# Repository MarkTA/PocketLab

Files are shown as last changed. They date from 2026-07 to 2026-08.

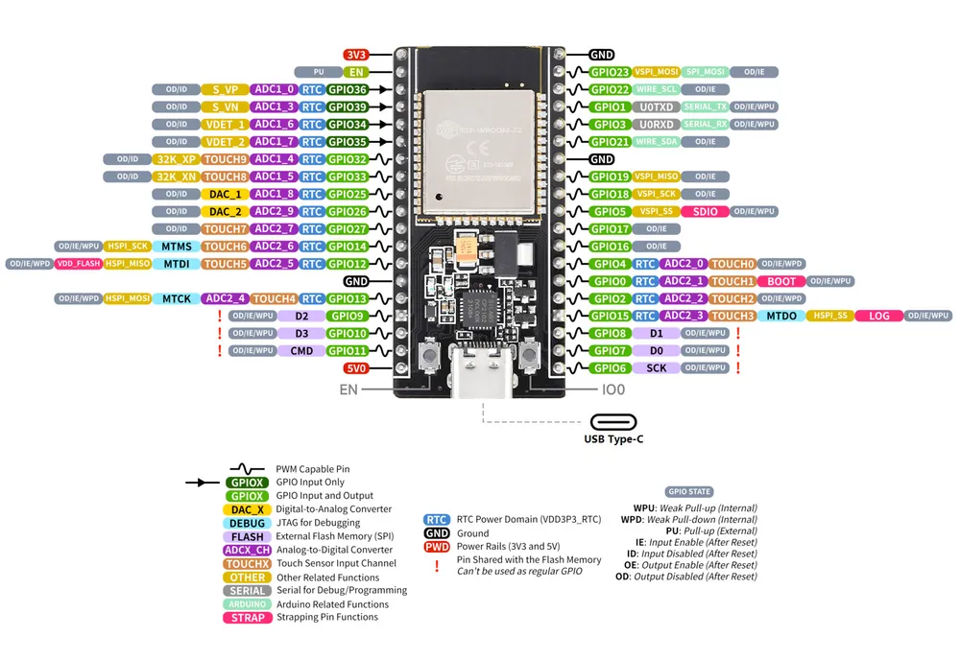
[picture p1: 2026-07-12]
docs/Component Reference/NodeMCU-ESP32S-BLE/en5HGiIniw-1000.webp

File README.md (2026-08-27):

# PocketLab

PocketLab is a modular, portable electronics instrumentation platform designed to combine common bench tools with a mobile interface.

The system is built around a compact **Bluetooth Low Energy (BLE) digital multimeter**, with additional instruments designed as stackable hardware modules. The goal is to create a practical, low-cost electronics lab that can travel with a laptop or fit in a small work area.

## Current Development

The first hardware prototype, **PocketLab DMM EVT-0**, is currently in PCB development.

### DMM EVT-0

- **Nordic nRF52840** BLE microcontroller
- **TI ADS1220** 24-bit delta-sigma ADC
- Voltage and resistance measurement
- Relay-based measurement routing
- USB-C power and charging
- Battery-powered portable operation
- 4-layer custom PCB designed in **Altium Designer**
- Stackable interface for future PocketLab instrument modules
- BLE communication with the PocketLab mobile application

EVT-0 is intentionally focused on validating the complete hardware/software system: PCB design, assembly, measurement circuitry, calibration, firmware, BLE communication, and mobile application integration.

## Planned Modules

PocketLab is designed as a modular platform rather than a single instrument.

Planned development includes:

- **FPGA Oscilloscope** — high-speed single-channel acquisition using an AMD Artix-7 FPGA and TI ADS6125 12-bit, 125 MS/s ADC
- **Function Generator**
- Additional measurement and electronics-development modules

## Software

PocketLab includes a companion mobile application for instrument control, measurement display, data logging, and interaction with connected modules.

The application is being developed with **React Native** and communicates with PocketLab hardware over Bluetooth Low Energy.

## Project Goals

PocketLab is also an ongoing engineering platform for developing experience in:

- Mixed-signal circuit design
- PCB schematic capture and layout
- Embedded systems
- Bluetooth Low Energy
- Precision data acquisition
- FPGA and RTL development
- Hardware/software integration
- Test, calibration, and design validation

## License

The software in this repository is licensed under the Apache License 2.0.

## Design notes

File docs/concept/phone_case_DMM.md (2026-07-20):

# PocketLab Phone-Case Multimeter Concept

**Recorded:** July 16, 2026  
**Status:** Future project idea—defer until the current PocketLab function generator is complete

## Concept

A compact, low-voltage digital multimeter integrated into—or attached to—a phone case. The phone supplies the display, controls, graphing, data logging, and user interface through a native mobile app. A thin measurement module contains the analog front end, precision ADC, low-power nRF52 microcontroller, BLE interface, and power source.

The defining physical feature would be two independently retractable probes with approximately 12-inch leads. Each probe would store along the edge of the case, while its wire retracts into a replaceable twin-reel cartridge on the back of the phone.

## Initial Product Scope

- Low-voltage electronics use only
- Approximately 0–30 V DC measurement
- Resistance and continuity
- Diode test
- Live numeric display and scrolling graph
- Automatic BLE connection and offline operation
- Measurement history and data export
- Two independent 12-inch retractable probes
- No mains rating
- No current measurement in the first version

## Proposed Architecture

- nRF52 MCU/module for low-power BLE and measurement control
- External precision ADC
- Protected, autoranging analog front end
- Thin rechargeable battery, coin cell, or USB-C power
- React Native PocketLab app as the display and interface
- Modular electronics pod compatible with multiple phone-specific shells
- 3D-printed enclosure prototypes using PETG, with optional TPU phone-retention features

## Retractable-Probe Design

- Two side-by-side reels, approximately 25–30 mm in diameter
- Thin, flexible 28–30 AWG silicone-insulated wire
- Constant-force or clock-style return springs
- Pull-and-lock ratchet with tug-to-release retraction
- Short probes stored in molded channels along the phone edges
- Replaceable reel/probe cartridge for serviceability
- Prefer a limited-rotation flexible clock-spring electrical connection instead of sliding contacts or inexpensive slip rings
- Calibrate and subtract lead resistance for continuity and low-resistance measurements

## Product Differentiators

- Always available because it stays attached to the phone
- Self-storing probes with no separate lead pouch
- Phone-quality display, controls, graphing, and logging
- Pocketable low-voltage electronics tool for students, makers, embedded developers, and technicians
- Fast, memorable demonstration for interviews and professional networking
- Potential foundation for additional PocketLab modules, including a function generator, oscilloscope, and logic analyzer

## Important Engineering Questions

- Can the twin-reel mechanism remain thin, smooth, and reliable over thousands of cycles?
- Can the rotating electrical connection maintain stable resistance without adding noise?
- What reel and probe geometry is comfortable in a pocket?
- How should the instrument pod attach across different phone models?
- What input protection is appropriate for the stated 30 V maximum?
- What accuracy, sample rate, battery life, and production cost are achievable?
- Does the mechanical design contain protectable intellectual property, and what related prior art exists?

## Recommended Future Development Sequence

1. Inventory the available nRF52 modules and development board.
2. Build a bench prototype that measures 0–5 V DC and sends readings to the PocketLab app over BLE.
3. Characterize accuracy, noise, update rate, and power consumption.
4. Disassemble inexpensive badge reels or retractable cable mechanisms for dimensional and durability studies.
5. Print a non-electronic PETG phone-case mockup with a twin-reel cartridge.
6. Develop and cycle-test the reel, ratchet, probe storage, and clock-spring connection.
7. Combine the mechanical prototype with the measurement electronics.
8. Expand to 0–30 V, resistance, continuity, and diode modes.
9. Conduct prior-art, market, manufacturability, and cost studies before designing a production PCB.

## Current Decision

Preserve this concept for later development without interrupting the present PocketLab function-generator work. Finish and document the function generator first, then revisit the phone-case multimeter as a potential second PocketLab instrument and commercial product.

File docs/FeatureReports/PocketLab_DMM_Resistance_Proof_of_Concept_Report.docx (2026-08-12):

ENGINEERING VALIDATION REPORT

# PocketLab DMM Resistance Measurement Proof of Concept

ADS1220 breadboard validation and provisional Rev A switching architecture

Project: PocketLab modular test platform

Test platform: ESP32 NodeMCU-32S + genuine ADS1220IPWR on a breadboard breakout

Report date: August 8, 2026

Status: Proof of concept successful; final parts and protection network pending schematic review

# Executive conclusion

Outcome: The tested resistance architectures provide credible overlapping coverage from continuity/near-zero resistance through approximately 10 MΩ. The genuine ADS1220 successfully supported both IDAC-based ratiometric measurements and a separate supply-ratiometric voltage-divider method.

The breadboard work was intentionally architectural, not a final accuracy qualification. One-percent resistors, jumper/contact resistance, solderless-breadboard leakage, and unguarded high-impedance nodes dominate several observed errors. Those limitations do not invalidate the topology; they define what the first precision PCB must improve.

# 1. Test platform and common settings

Item | Bench configuration
ADC | ADS1220IPWR, 24-bit delta-sigma ADC, TSSOP-16
Controller | ESP32 NodeMCU-32S
Supplies | 3.3 V analog and digital rails; common analog/digital ground on breadboard
SPI | Mode 1 (CPOL=0, CPHA=1), 1 MHz
Conversion | 20 SPS, normal mode, continuous conversion; typically 10 samples/report
Serial interface | 115200 baud; configurable divider firmware supports rref, samples, interval, predict, start/stop, once, status, regs, and adcreset
Safety state | Unprotected bench circuit. Tests used only unpowered resistors and discharged components.

# 2. Pin assignments

## ADS1220IPWR TSSOP-16 and ESP32 wiring

Pin | ADS1220 signal | Bench connection | Function
1 | SCLK | ESP32 GPIO 18 | SPI clock
2 | CS | ESP32 GPIO 27 | Active-low chip select
3 | CLK | DGND | Internal oscillator used
4 | DGND | Ground | Digital ground
5 | AVSS | Ground | Analog ground
6 | AIN3 / REFN1 | Unused | Reserve/test point on PCB
7 | AIN2 | IDAC Node A | IDAC1 injection point in ratiometric ohms mode
8 | REFN0 | AGND | External reference low
9 | REFP0 | Rref top / 3.3 V | Rref node in IDAC mode; excitation rail in divider mode
10 | AIN1 | Node B / AGND | Negative ADC input; grounded in divider mode
11 | AIN0 / REFP1 | Node A / divider junction | Positive ADC input
12 | AVDD | 3.3 V | 100 nF or larger to AVSS
13 | DVDD | 3.3 V | 100 nF or larger to DGND
14 | DRDY | ESP32 GPIO 26 | Dedicated data-ready, active low
15 | DOUT / DRDY | ESP32 GPIO 19 | SPI MISO
16 | DIN | ESP32 GPIO 23 | SPI MOSI

Pin numbers above are for the PW (TSSOP-16) package used in the breadboard build. Any adapter/header numbering should be checked against the adapter schematic before PCB capture.

# 3. Tested resistance configurations

## A. IDAC verification with 9.99 kΩ reference

Purpose: verify that the genuine ADS1220 correctly produces its low excitation-current settings before relying on ratiometric resistance measurements. IDAC1 was routed directly to REFP0 with 9.99 kΩ from REFP0 to REFN0/AGND. The 10 µA, 50 µA, and 100 µA settings correspond to nominal reference voltages of 0.0999 V, 0.4995 V, and 0.9990 V.

Interpretation: The genuine ADS1220 corrected the abnormal 10 µA behavior seen on the earlier third-party module, clearing the internal IDAC for continued range development.

## B. IDAC/ratiometric resistance mode

Wiring and equation:

Node/path | Connection
Node A | AIN2 (IDAC1 output) tied to AIN0; Rx connects from Node A to Node B
Node B | AIN1 tied to REFP0; Rref connects from Node B to REFN0/AGND
Measurement | ADC measures AIN0 − AIN1 while REFP0 − REFN0 is the external reference
Equation | Rx = (ADC code / 2²³) × Rref / PGA gain

Because the same IDAC current passes through Rx and Rref, absolute IDAC-current error largely cancels. Tested range configurations included 21.6 kΩ / 50 µA and 100.6 kΩ / 10 µA. The latter used registers 00 04 41 60 at gain 1 and was exercised across the resistor set below.

Comparison value | ADS1220 mean | Approx. FS use | Observation
99.8 Ω | 100.940 Ω | 0.100% | Low ADC utilization; lead/contact/offset effects dominate
1.003 kΩ | 1.005676 kΩ | 1.000% | After subtracting the same-setup short mean, result was approximately 1.0028 kΩ
4.74 kΩ | 4.752627 kΩ | 4.724% | Stable proof-of-concept response
9.90 kΩ | 9.897055 kΩ | 9.838% | Close agreement at gain 1
21.49 kΩ | 21.475935 kΩ | 21.348% | Stable midrange response

The gain-1 short averaged 2.876 Ω with 0.160 Ω batch-to-batch standard deviation. That offset is not a universal correction; it changes with gain, switch path, probes, and physical connections. Low-ohm production measurements therefore require per-range zeroing and automatic PGA selection. True sub-ohm accuracy would require a later Kelvin/four-wire mode.

## C. 1.000 MΩ supply-ratiometric divider mode

Connection/setting | Divider-mode assignment
AIN0 (pin 11) | Junction of 1.000 MΩ reference and Rx
AIN1 (pin 10) | AGND
REFP0 (pin 9) | Same 3.3 V excitation rail feeding Rref
REFN0 (pin 8) | AGND
IDACs | Disabled
Registers | 01 04 40 00: AIN0−AIN1, gain 1, PGA bypassed, external REFP0/REFN0
Equation | k = ADC code / 2²³; Rx = Rref × k / (1 − k)

Fluke reading | ADS1220 mean | Difference | Divider ratio | Interpretation
100.6 kΩ | 100.0879 kΩ | −0.51% | 9.10% | Clean lower overlap with IDAC ranges
467 kΩ | 462.628 kΩ | −0.94% | 31.63% | Stable mid-divider result; modest upward settling drift
9.80 MΩ | 9.6159 MΩ | −1.88% | 90.58% | Successful multi-megaohm measurement; leakage and near-full-scale sensitivity visible

The increasing negative error with resistance is consistent with leakage becoming more influential, while the nominal 1 MΩ reference value, Fluke uncertainty, ADC input current, and breadboard contamination also contribute. The 9.80 MΩ reading operated near 91% of ADC full scale, making the calculated resistance highly sensitive to small ratio errors. A 10 MΩ reference is therefore recommended for the upper range.

# 4. Coverage demonstrated and proposed range map

Target region | Method | Provisional configuration | Evidence/status
Continuity to ~1 kΩ | IDAC, ratiometric | 10 kΩ precision Rref; ~100 µA; higher PGA gain | Partially demonstrated; low-ohm accuracy needs zeroing and gain
~1 kΩ to 10 kΩ | IDAC, ratiometric | 10 kΩ precision Rref; 100 µA; auto gain | Topology and excitation verified
~10 kΩ to 100 kΩ | IDAC, ratiometric | 100 kΩ precision Rref; 10 µA | Validated from 100 Ω through 21.49 kΩ; electrical headroom supports extension
~100 kΩ to 3–5 MΩ | Voltage divider, ratiometric | 1 MΩ precision Rref; 3.3 V excitation/reference | Validated at ~100 kΩ and 467 kΩ; 10 MΩ measurement also succeeded with reduced accuracy
~3 MΩ to 20 MΩ+ | Voltage divider, ratiometric | 10 MΩ precision Rref; guarded high-Z path | Recommended next range; not yet tested

Range policy: Use overlapping ranges and autorange toward the center of ADC span. Avoid relying on results below roughly 1% or above roughly 90% of full scale when a neighboring range is available.

# 5. Provisional Rev A switching architecture

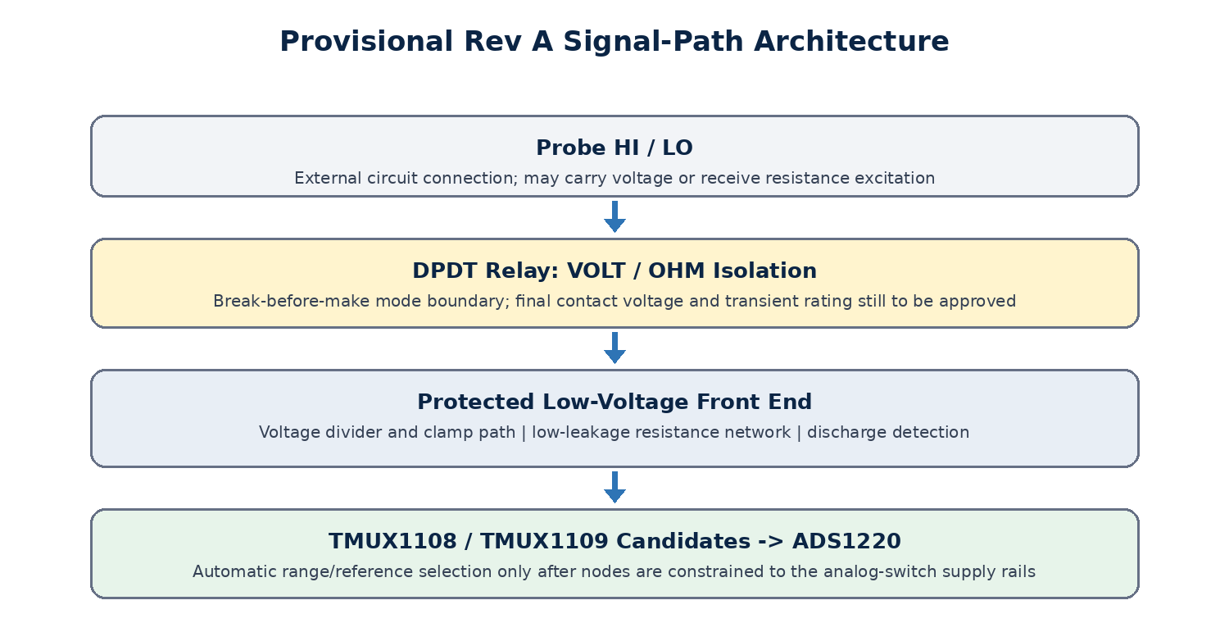
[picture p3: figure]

Figure 1. Proposed separation between the hazardous/probe-level mode boundary and the protected low-voltage range-selection network.

## Relay: voltage/ohms mode boundary

Use a DPDT, break-before-make relay to select the probe pair between the voltage-measurement front end and the powered resistance-measurement front end. Mechanical contacts provide galvanic separation from the low-voltage analog switches and prevent the ADS1220 IDAC from being connected to an energized voltage source during normal operation.

- Default/fail-safe state should be voltage mode or fully disconnected, with resistance excitation disabled during boot, reset, brownout, and relay transitions.
- Firmware must disable both IDACs, wait for the relay to settle, verify the selected state where possible, and only then enable the chosen resistance range.
- Include a transistor or MOSFET coil driver, flyback suppression, a defined MCU pull state, and local supply decoupling. Do not drive the 3 V coil directly from an MCU pin.
- The Panasonic TQ2-3V remains a useful prototype candidate: sealed, 2 Form C (DPDT), break-before-make, 3 V coil, and 140 mW rated coil power. Its published nominal resistive switching capacity is 1 A at 30 VDC. Final approval depends on the exact location of the relay relative to the input protection/divider and the product’s maximum DC input and transient requirements.

Purchasing gate: Do not commit the TQ2-3V as the final probe-level relay until the voltage-mode protection/divider schematic proves that every contact operating and transient condition is within the relay’s ratings. If the relay directly sees the planned ~70 V input, select or validate a relay specifically for that DC voltage and measurement-category environment.

## Analog multiplexers: automatic resistor and topology ranges

Candidate | Topology | Best provisional role | Reason / constraint
TMUX1108PWR | Single 8:1 precision multiplexer | Select one of several reference/excitation branches or calibration/open positions | Very low leakage, break-before-make, enable-all-off state; 0–VDD signal path only
TMUX1109PWR | Dual 4:1 / differential 4:1 precision multiplexer | Switch two related low-voltage nodes together, such as ADC input/reference or paired topology nodes | Coordinated dual channels reduce GPIO and timing mismatch; same rail-limit restriction

Both TI parts are strong candidates because their typical leakage is in the picoamp region, they are bidirectional and break-before-make, and they include an enable state that disconnects all channels. At 3.3 V, however, their analog signal pins must remain within the switch supply rails. They are not input-protection devices and must sit behind the relay and protection/scaling network.

- Do not automatically assume the TMUX on-resistance is harmless in the continuity/low-ohm path. TMUX1108 is typically about 4 Ω at a 3.3 V supply under its datasheet test condition. Place it so its resistance is calibrated as part of Rref/path resistance, or bypass it with a lower-resistance solution for the lowest range.
- For the 1 MΩ and 10 MΩ divider ranges, leakage is more important than on-resistance. Keep the high-impedance node short, guarded, clean, and separated from relay-coil and digital traces.
- Reserve explicit all-off/open, short-calibration, 10 kΩ, 100 kΩ, 1 MΩ, and optional 10 MΩ states. Unused channels can become test or future ranges only after leakage impact is reviewed.
- Add 0 Ω links and test points so each range can be isolated from the switch during bring-up. This allows direct resistor testing before attributing errors to the multiplexer.

# 6. Recommended Rev A implementation plan

1. Freeze the functional range plan. Adopt overlapping low/mid IDAC ranges plus 1 MΩ and 10 MΩ divider ranges. Treat Kelvin measurement as a future enhancement, not a Rev A blocker.
2. Complete the voltage-input protection and divider schematic first. Establish maximum input, transient goals, discharge detection, current limiting, creepage/clearance, and the voltage actually appearing at the mode relay and TMUX nodes.
3. Draw the full switching truth table. For every relay and TMUX state, define probe connection, ADC inputs, reference selection, IDAC route, expected node voltages, boot state, and forbidden transitions.
4. Select precision references. Use low-tempco 0.05% or 0.01% parts where cost permits; provide 10 kΩ, 100 kΩ, 1 MΩ, and optional 10 MΩ footprints. Store measured/calibrated value per assembled board.
5. Prototype the uncertain switching functions quickly. Validate TMUX leakage at ~10 MΩ, low-range series resistance/zero repeatability, relay-mode isolation, and relay-driver behavior before the consolidated DigiKey order.
6. Lay out the analog section for measurement integrity. Separate high-Z nodes from digital/relay traces, add guard copper where useful, omit solder mask only when justified, provide cleaning access, and place decoupling and RC filters at the ADC pins.
7. Implement safe autoranging firmware. Start de-energized, open analog switches before changing range, wait for settling, reject overrange/negative ratios, and fall back to voltage/disconnected mode after faults or reset.
8. Calibrate and verify the PCB by range. Record zero/path resistance, Rref value, gain/offset constants, leakage behavior, repeatability, temperature drift, and cross-checks against the Fluke and a better reference instrument when available.

# 7. Rev A acceptance targets

Gate | Acceptance evidence
Coverage | Continuity/near-zero through at least 10 MΩ with no manual rewiring
Autoranging | Stable range selection with overlap and no IDAC exposure during switching
Mode safety | Ohms excitation cannot be enabled while the voltage path or an overvoltage condition is present
Low-ohm behavior | Repeatable software-zero result; continuity response target defined separately from precision resistance
High-ohm behavior | 1 MΩ and 10 MΩ ranges characterized for leakage after PCB cleaning and environmental exposure
Serviceability | Test points and 0 Ω isolation links allow each reference and switch path to be measured independently
Documentation | Per-range register map, switching truth table, calibration constants, and protection assumptions captured in the schematic notes

# Appendix A. Test artifacts and source documents

The following firmware files preserve the breadboard configurations summarized in this report. Serial measurement logs from the working sessions were reduced into the result tables above; the PCB design should retain new raw logs by board serial number and range.

Firmware artifact | Purpose
ADS1220_9k99_IDAC_Range_Test.ino | Direct 10 µA / 50 µA / 100 µA IDAC verification with 9.99 kΩ
ADS1220_21k6_50uA_Ratiometric_Test.ino | 21.6 kΩ / 50 µA ratiometric resistance configuration
ADS1220_100k6_10uA_Ratiometric_Test.ino | 100.6 kΩ / 10 µA multi-resistor configuration
ADS1220_Serial_Configurable_Resistance_Divider.ino | Serial-configurable 1 MΩ supply-ratiometric divider configuration

## Manufacturer references

Texas Instruments, ADS1220 datasheet (Rev. D, May 2026) (https://www.ti.com/lit/ds/symlink/ads1220.pdf)

Texas Instruments, TMUX1108 datasheet (Rev. B) (https://www.ti.com/lit/ds/symlink/tmux1108.pdf)

Texas Instruments, TMUX1109 datasheet (Rev. A) (https://www.ti.com/lit/ds/symlink/tmux1109.pdf)

Panasonic Industry, TQ2-3V product specifications (https://na.industrial.panasonic.com/products/relays-contactors/mechanical-signal-relays/series/119572/model/119866)

PocketLab DMM •

PocketLab DMM | Engineering Validation Report

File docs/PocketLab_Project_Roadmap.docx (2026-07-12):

PocketLab Project Roadmap

# Vision

PocketLab is a portable, BLE-controlled electronics laboratory built around an ESP32. The first instrument is a programmable function generator. Future instruments will include an oscilloscope, logic analyzer, programmable power supply, and signal injector. The mobile application should be instrument-focused and transport-agnostic.

# Architecture

UI → Instrument API → PocketLab Device → Transport → BLE (future USB/Wi-Fi). The UI never sends raw BLE commands. Instruments expose methods such as setFrequency(), setAmplitude(), and outputEnabled().

# Milestone 1 – BLE Foundation

Complete: scanning, connecting, reconnecting, disconnecting, service discovery, read/write characteristics, connection status UI.

# Milestone 2 – PocketLab Command Protocol

Implement ASCII request/response protocol (PING, INFO, SET_FREQ, SET_AMP, SET_OFFSET, SET_WAVE, OUTPUT). Every command returns OK or ERR.

# Milestone 3 – Command Parser Firmware

Create a reusable parser independent of BLE. BLE callback simply forwards received commands to the parser.

# Milestone 4 – Function Generator

Integrate AD9833 driver. Connect all UI controls to firmware commands. Verify waveform, frequency, amplitude, offset, presets, and output enable.

# Milestone 5 – Protocol Robustness

Device identification, firmware versioning, capability discovery, validation, acknowledgements, error handling.

Milestone 6 – Notifications

Push asynchronous status changes, settings updates, and faults from device to app.

Milestone 7 – Hardware

Rail-to-rail output amplifier, adjustable offset, output protection, calibration, PCB prototype.

# Milestone 8 – Additional Instruments

Reuse the same transport and command framework for oscilloscope, logic analyzer, programmable power supply, and signal injector.

# Design Principles

• Separate UI from transport. • Commands are human-readable during development. • Every command receives a response. • BLE is only one transport layer. • Each instrument exposes a clean API. • Reuse infrastructure whenever possible.

# Conversation Context

Current status: BLE communication infrastructure is operational. The next task is implementing the PocketLab command protocol and firmware command parser before integrating the AD9833 function generator.

src/

├── app/

│ ├── navigation/

│ └── providers/

│

├── core/

│ ├── device/

│ │ ├── PocketLabDevice.ts

│ │ ├── DeviceProvider.tsx

│ │ └── deviceTypes.ts

│ │

│ ├── transport/

│ │ ├── PocketLabTransport.ts

│ │ ├── BleTransport.ts

│ │ └── transportTypes.ts

│ │

│ └── protocol/

│ ├── commands.ts

│ ├── responses.ts

│ ├── parser.ts

│ └── protocolTypes.ts

│

├── instruments/

│ ├── functionGenerator/

│ │ ├── FunctionGenerator.ts

│ │ ├── FunctionGeneratorScreen.tsx

│ │ ├── FunctionGeneratorControls.tsx

│ │ ├── FunctionGeneratorPreview.tsx

│ │ └── functionGeneratorTypes.ts

│ │

│ ├── oscilloscope/

│ │ ├── Oscilloscope.ts

│ │ ├── OscilloscopeScreen.tsx

│ │ └── oscilloscopeTypes.ts

│ │

│ ├── logicAnalyzer/

│ │ ├── LogicAnalyzer.ts

│ │ ├── LogicAnalyzerScreen.tsx

│ │ └── logicAnalyzerTypes.ts

│ │

│ ├── powerSupply/

│ │ ├── PowerSupply.ts

│ │ ├── PowerSupplyScreen.tsx

│ │ └── powerSupplyTypes.ts

│ │

│ └── signalInjector/

│ ├── SignalInjector.ts

│ ├── SignalInjectorScreen.tsx

│ └── signalInjectorTypes.ts

│

├── features/

│ └── connection/

│ ├── DeviceStatusCard.tsx

│ ├── ScanDeviceSheet.tsx

│ └── blePermissions.ts

│

├── components/

│ └── shared UI components

│

├── themes/

└── utils/

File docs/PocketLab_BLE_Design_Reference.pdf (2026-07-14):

PROJECT REFERENCE

# PocketLab BLE Design

A durable reference for the function generator's BLE architecture, safety model, and extensible GATT namespace.

1/3

## SYSTEM AT A GLANCE

MOBILE APP

React Native / Expo

BLE LINK

Custom GATT service

CONTROL

ESP32 + NimBLE

SIGNAL

AD9833 DDS

## DESIGN BASELINE

## Control objective

Low-latency, bidirectional control with explicit device state, predictable disconnect behavior, and room for future PocketLab instruments.

## Logical safe idle

WAVE=DC | FREQ=0
AMP=0.00 | OFFSET=0.00
OUTPUT=OFF

DC is an internal safe-state sentinel. The AD9833 is not asked to synthesize DC; hardware output is disabled instead.

SUFFIX | ATTRIBUTE | ACCESS | ROLE | STATUS
0001 | PocketLab service | Primary service | Function-generator control namespace | In use
0002 | Command | Write / Write NR | App -> ESP32 request frames | In use
0003 | Response | Notify + Read | ESP32 -> app ACK, ERR, data | In use
0004 | State | Read + Notify | Snapshot and unsolicited state changes | Reserved
0005 | Device info | Read | Protocol version and capabilities | Reserved

SERVICE 8f5b0001-6c4d-4a73-a8f1-3d9ea01c0001

COMMAND 8f5b0002-6c4d-4a73-a8f1-3d9ea01c0001

Strategy: replace N in 8f5b000N with the table suffix; keep the shared 128-bit base for every function-generator attribute.

PocketLab BLE Design Reference | Baseline: firmware v0.3.2 | Mark Anderson | 13 July 2026 | 1

ENGINEERING RECORD

# NimBLE Migration & Debugging

The important failures, observations, and design rules preserved as reusable project knowledge.

2/3

## WHY NIMBLE

### Lean stack

Lower memory overhead and a smaller embedded BLE surface for the ESP32.

### Explicit behavior

Characteristic properties, callbacks, notifications, and advertising are configured deliberately.

### Stable foundation

A consistent server API for reconnect handling and future PocketLab services.

## DEBUGGING HISTORY

### 10 JUL Generic GATT baseline

BAAD/F00D demo reads worked. Writes appeared successful on Android, but the ESP32 onWrite callback did not run and the original value remained unchanged.

### 11 JUL Write-path isolation

Request and Command modes plus write-with-response and write-without-response were tested. In one nRF Connect test, the attribute value changed to PING while callback logging was still absent.

### 11-12 JUL Custom service + reconnect

Service discovery, characteristic reads, notifications, connection status, and automatic reconnect worked. A PING write was accepted, then the app timed out after 5 seconds waiting for a response.

### 12 JUL NimBLE command path operational

The custom command server began delivering responsive app control. Fast round trips confirmed the BLE path was viable for interactive waveform control.

### 13 JUL Safe-idle hardening

Disconnect behavior exposed an unwanted roughly 3.3 V DC output. The design separated logical DC idle from supported AD9833 waveforms and made OUTPUT=OFF the default and disconnect action.

## MIGRATION GUARDRAILS

AREA | RULE TO KEEP
Callbacks | Attach characteristic callbacks before starting the service; log payload length and decoded text at entry.
Properties | Firmware properties must match the app's selected write type. Support both only when both paths are tested.
Notifications | Subscribe before sending the first command; create one response for every accepted request.
Reconnect | On disconnect, force safe idle, restart advertising, and let only the app initiate automatic reconnect.
State | Keep logical state separate from hardware modes; DC is never passed to the AD9833 waveform function.
PocketLab BLE Design Reference | Baseline: firmware v0.3.2 | Mark Anderson | 13 July 2026 | 2

PROTOCOL SPECIFICATION

# PocketLab Command Protocol v1

A compact ASCII request/response protocol designed to remain reliable at the default BLE MTU of 23 bytes.

3/3

## WIRE FORMAT

UTF-8/ASCII, one frame per characteristic write or notification, no terminator required. Keep v1 frames at 20 bytes or fewer so they fit the MTU-3 payload without fragmentation. The app permits one outstanding request at a time.

## COMMAND SET

REQUEST | PURPOSE | SUCCESS RESPONSE
PING | Verify the complete write/notify path | OK:PONG
GET:STATE | Request a complete state transaction | STATE:* frames, then STATE:END
SET:WAVE:SINE | Set SINE, TRIANGLE, or SQUARE | OK:WAVE:SINE
SET:FREQ:1000 | Set output frequency in hertz | OK:FREQ:1000
SET:AMP:0.65 | Set requested amplitude in Vpp | OK:AMP:0.65
SET:OFFSET:0.00 | Set requested DC offset in volts | OK:OFFSET:0.00
OUTPUT:ON | Enable hardware output after validation | OK:OUTPUT:ON
OUTPUT:OFF | Immediately disable hardware output | OK:OUTPUT:OFF

## STATE TRANSACTION

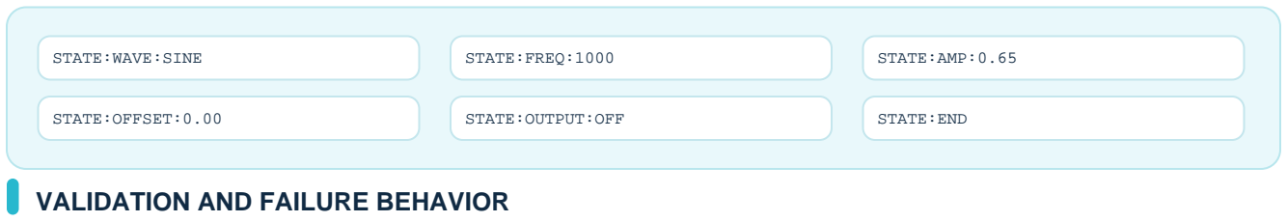
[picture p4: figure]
STATE:WAVE:SINE; STATE:FREQ:1000; STATE:AMP:0.65; STATE:OFFSET:0.00; STATE:OUTPUT:OFF; STATE:END; VALIDATION AND FAILURE BEHAVIOR
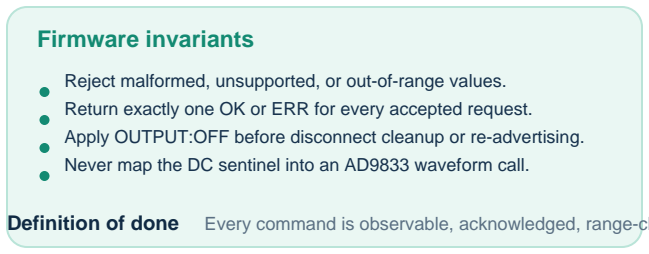
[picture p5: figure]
Firmware invariants

Reject malformed, unsupported, or out-of-range values.
Return exactly one OK or ERR for every accepted request. Apply OUTPUT:OFF before disconnect cleanup or re-advertising. Never map the DC sentinel into an AD9833 waveform call.

### Implementation sequence

1 Add parser + unit tests
2 Add response notification queue 3 Serialize app requests + timeout 4 Verify MTU 23 and reconnect cases 5 Record scope readings by waveform Definition of done Every command is observable, acknowledged, range-checked, and safe across disconnect/reconnect.
PocketLab BLE Design Reference | Baseline: firmware v0.3.2 | Mark Anderson | 13 July 2026 | 3

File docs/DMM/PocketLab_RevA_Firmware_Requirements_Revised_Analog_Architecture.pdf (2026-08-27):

# PocketLab Rev A Firmware Requirements

## Revised ADS1220 / TMUX1109 Analog Architecture

Status: design note for schematic freeze and later firmware implementation. Revision date: 2026-08-18. This document reflects the revised unipolar resistance excitation plan while preserving the ADS1220 bipolar analog supply (+2.5 V / -2.5 V). Core rule: voltage measurement remains bipolar-capable, but all valid resistance-mode probe signals are constrained to approximately 0 V through +2.5 V. The ADS1220 internal low-side PSW is not used.

## 1. Final ADS1220 analog pin assignment

ADS1220 input | Connection | Purpose
AIN0 | VSENSE_BUF | Voltage measurement input
AIN1 | GND | Voltage reference input and high-ohms negative ADC input
AIN2 | OHMS_SENSE_LO | Resistance Rref/divider junction
AIN3 | OHMS_SENSE_HI | Resistance probe-high node and IDAC1 destination
REFP0 | ADC_REFP0 | Ratiometric reference high
REFN0 | GND | Ratiometric reference low

## 2. ADS1220 mode configuration

Mode | ADC MUX | MUX bits | Reference | PGA / IDAC
Voltage | AIN0 - AIN1 | 0000 | Internal 2.048 V | Gain 1, PGA bypass, IDAC off
10k Rref | AIN3 - AIN2 | 0111 | REFP0 / REFN0 | IDAC on, PSW off
100k Rref | AIN3 - AIN2 | 0111 | REFP0 / REFN0 | IDAC on, PSW off
1M divider | AIN1 - AIN2 | 0011 | +2V5A / GND | Gain 1, PGA bypass, IDAC off
10M divider | AIN1 - AIN2 | 0011 | +2V5A / GND | Gain 1, PGA bypass, IDAC off

The ADS1220 datasheet defines MUX=0000 as AIN0-AIN1, 0011 as AIN1-AIN2, and 0111 as AIN3-AIN2. For high-ohms mode the conversion is intentionally negative because AIN1 is GND and AIN2 is the positive divider node.

## 3. External TMUX1109 functions

MUX_OHMS keeps the four range states. A1:A0 = 00/01/10/11 selects 10k/100k/1M/10M. Its A bank selects the Rref topology; its B bank selects REFP0. EN=0 must disconnect all channels.

A1 A0 | Range | Rref connection | ADC_REFP0 | IDAC / PSW
00 | 10k | 10k to GND | OHMS_SENSE_LO | IDAC selected / PSW OFF
01 | 100k | 100k to GND | OHMS_SENSE_LO | IDAC selected / PSW OFF
10 | 1M | 1M to +2V5A | +2V5A | IDAC OFF / PSW OFF
11 | 10M | 10M to +2V5A | +2V5A | IDAC OFF / PSW OFF

Repurposed MUX_ADC: DA connects to OHMS_SENSE_HI. S1A and S2A are NC/open. S3A and S4A connect to GND. The B bank is unused. Prefer MUX_ADC_EN=0 in voltage and low/mid-ohms modes, and MUX_ADC_EN=1 only in the 1M/10M divider modes. TMUX1109 EN=0 turns all channels off.

## 4. Resistance-mode electrical behavior

Low/mid ohms (10k and 100k Rref): IDAC1 is routed to AIN3/OHMS_SENSE_HI. Current flows through Rx and the selected Rref to GND. The ADC measures AIN3-AIN2 while REFP0 is tied to OHMS_SENSE_LO and REFN0 to GND. This remains ratiometric because the same excitation current flows through Rx and Rref.
High ohms (1M and 10M Rref): the selected Rref is connected from +2V5A to OHMS_SENSE_LO. The repurposed TMUX1109 grounds OHMS_SENSE_HI. Rx therefore sits between OHMS_SENSE_LO and GND. REFP0 is +2V5A and REFN0 is GND. The ADC measures AIN1-AIN2 = GND - OHMS_SENSE_LO.
High-ohms conversion: sign-extend the 24-bit conversion to a signed integer. For a valid divider reading the code should be negative. Define k = -code / 2^23 (gain 1), then compute Rx = Rref * k / (1 - k). Reject k <= 0, k >= 1, unexpected positive code, or values too close to either endpoint.

## 5. IDAC requirements and compliance

The ADS1220 IDAC output pin must remain at or below approximately AVDD - 0.9 V for specified IDAC accuracy. With AVDD = +2.5 V, the AIN3/OHMS_SENSE_HI target is therefore <= about +1.6 V while an IDAC is active.

Example setting | Approx. total R at 1.6 V compliance | Approx. Rx headroom after Rref
100 uA, 10k Rref | 16k ohm | 6k ohm
50 uA, 10k Rref | 32k ohm | 22k ohm
10 uA, 100k Rref | 160k ohm | 60k ohm

Do not freeze autorange thresholds from these estimates alone. Bench characterization should choose the current/PGA combination that keeps the IDAC in compliance while maintaining adequate ADC utilization. The earlier 100 uA / 10k and 10 uA / 100k values remain useful starting points, not unconditional full-range settings.

## 6. Required mode-transition sequence

1. Enter safe state: IDAC off, PSW off, MUX_ADC_EN=0, MUX_OHMS_EN=0, ohms relays open.
2. If entering resistance mode, first verify the DUT is not externally energized and no protection fault is present.
3. Program A1/A0 for the desired range while the muxes are disabled.
4. Configure ADS1220 input MUX, reference source, gain, PGA bypass, and IDAC current.
5. For low/mid ohms: enable MUX_OHMS, route IDAC1 to AIN3 only after programming the IDAC current, then wait at least 200 us for IDAC startup.
6. For high ohms: enable MUX_OHMS, then enable MUX_ADC ground-switch state; IDAC remains off.
7. Close the ohms relays only in the intended safe sequence; allow relay and analog settling.
8. Start/synchronize conversion, discard initial unsettled conversion(s) as required by bench characterization, then accept data.
9. On fault, reset, brownout, overrange, invalid ratio, or mode change: IDAC off first, disable muxes, then open ohms relays.

## 7. Provisional firmware configuration by mode

Item | Voltage | 10k/100k ohms | 1M/10M ohms
OHMS relays | Open | Closed after safety check | Closed after safety check
MUX_OHMS | Disabled | Enabled; range selected | Enabled; range selected
MUX_ADC | Disabled | Disabled | Enabled; S3/S4 -> GND
ADS MUX | 0000 | 0111 | 0011
VREF bits | 00 internal | 01 external REFP0/REFN0 | 01 external REFP0/REFN0
PSW | 0 | 0 | 0
IDAC | Off | Selected by range/compliance | Off
IDAC1 route | Disabled | AIN3 (I1MUX=100) | Disabled
PGA | Bypass initially | Range-dependent | Bypass
Expected sign | +/- voltage | Positive Rx drop | Negative code; negate in FW

## 8. Calibration and diagnostic requirements

- Store calibrated Rref values per board for 10k, 100k, 1M, and 10M ranges.
- Low-ohm calibration must include probe/lead resistance, reed-relay contact resistance, R_PROT_HI/LO, and any series switch resistance in the active path.
- Characterize zero offset separately for each gain/current/range combination; do not apply one universal short correction.
- High-ohms calibration must characterize leakage after PCB cleaning and under representative humidity/temperature conditions.
- Log the selected range, ADC register state, raw signed code, calculated ratio k, calibrated Rref, and protection/fault status during development.
- Autorange should prefer the middle of the useful ADC ratio span and avoid ratios close to 0 or 1 when an overlapping range exists.

## 9. Schematic items to correct before freeze

- MUX_ADC wiring: S1A/S2A must be NC; S3A/S4A must be GND. In the supplied screenshot S1A/S2A are presently tied to GND, which is reversed for the intended range coding.
- MUX_OHMS truth-table note: remove the old high-ohms 'PSW CLOSE' and 'AVDD-AVSS reference' text. High-ohms now uses PSW OFF and external +2V5A/GND reference.
- ADC firmware note: remove the old statement that 1M/10M uses the analog-supply reference and PSW. Replace it with the revised note provided with this document.
- Protection stage: TMUX7462F threshold/supply compatibility remains a separate open item. Do not declare the schematic frozen until that protection issue is resolved.
- Probe loading check: review the permanently connected voltage-divider path during resistance mode. If it remains across the probes, either isolate it in hardware or explicitly include its parallel loading in the resistance model/calibration, especially on the 1M/10M ranges.

## 10. References

- Texas Instruments, ADS1220 datasheet, Rev. D, May 2026 (SBAS501D).
- Texas Instruments, TMUX1109 datasheet, Rev. A, February 2024 (SCDS406A).
- PocketLab DMM Resistance Measurement Proof of Concept engineering validation report, August 8, 2026.

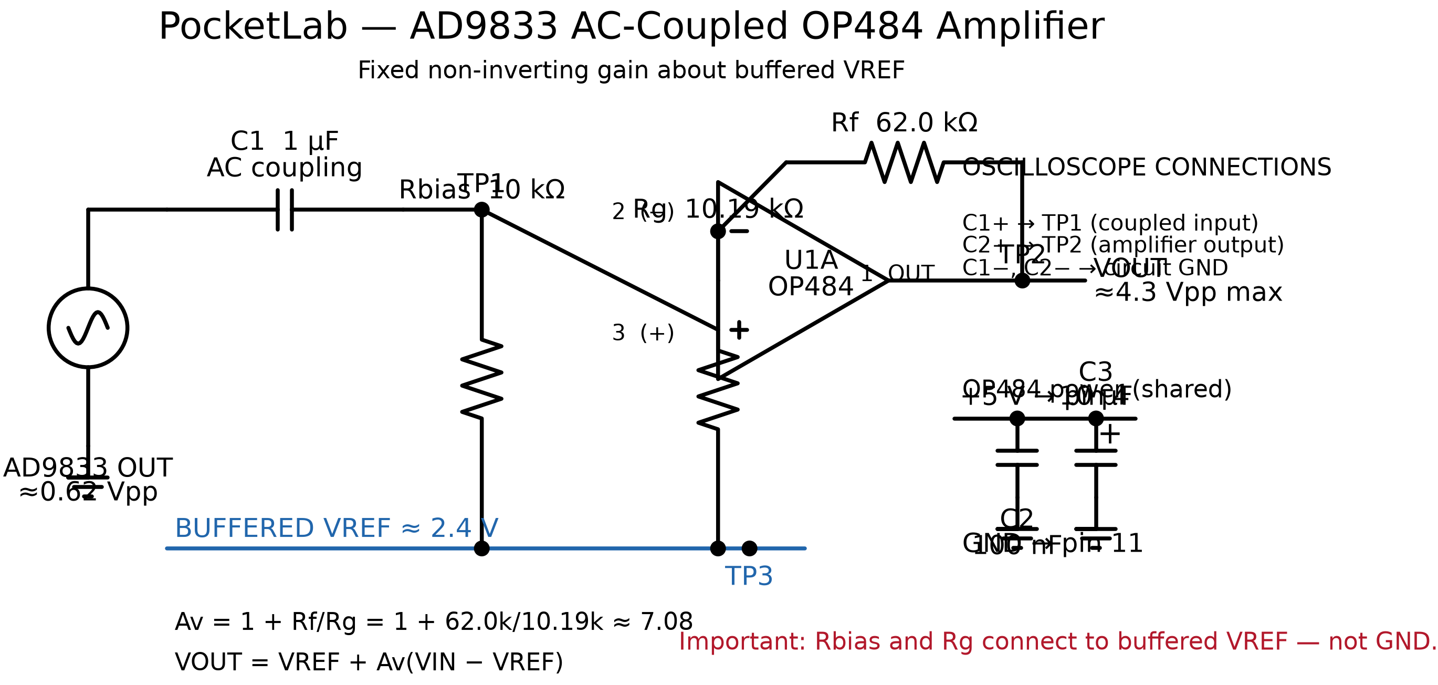
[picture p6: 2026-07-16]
hardware/schematics/PocketLab_OP484_Amplifier_Schematic.png

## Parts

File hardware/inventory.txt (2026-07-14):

ADALP2000 Analog Parts Kit Inventory
Kit part number: 240-000
Source: Analog Devices ADALP2000
Note: This inventory reflects the items visible in the two provided photographs.

AMPLIFIERS
1 x AD8226 - Instrumentation amplifier - Breakout board
1 x ADTL082 - JFET operational amplifier - Breakout board
1 x AD8542 - CMOS rail-to-rail operational amplifier - Breakout board
2 x OP482 - High-speed JFET operational amplifier - 14-lead PDIP
1 x OP484 - Precision rail-to-rail input/output operational amplifier - 14-lead PDIP
2 x OP27 - Low-noise precision operational amplifier - 8-lead PDIP
2 x OP37 - Precision operational amplifier - 8-lead PDIP
2 x OP97 - Low-power, high-precision operational amplifier - 8-lead PDIP
1 x LTC1541 - Micropower operational amplifier, comparator, and reference - Breakout board

SENSORS
1 x AD8210 - Current-shunt monitor - Breakout board
1 x AD22151 - Magnetic-field sensor - Breakout board
1 x ADXL327 - Three-axis accelerometer - Breakout board
2 x AD22100 - Voltage-output temperature sensor - TO-92
1 x AD592 - Current-output temperature sensor - TO-92
1 x TMP01 - Temperature controller - 8-lead PDIP
1 x Electret microphone
1 x 10 kOhm thermistor
1 x OP999 - PIN photodiode

POWER COMPONENTS
1 x ADP3300 - 3.3 V, 50 mA LDO linear regulator - Breakout board
1 x LT3092 - Programmable current source - Breakout board
1 x LTM8067 - Isolated DC-to-DC converter - Breakout board
1 x LT3080 - Adjustable 1.1 A LDO regulator - TO-220
1 x LT1054 - Switched-capacitor regulator - 8-lead PDIP

DATA CONVERSION
1 x AD654 - Voltage-to-frequency converter - 8-lead PDIP
1 x AD5626 - 12-bit nanoDAC+ - Breakout board
1 x AD7920 - 12-bit, 250 kSPS SPI ADC - Breakout board

MISCELLANEOUS INTEGRATED CIRCUITS
1 x AD584 - Programmable voltage reference - 8-lead PDIP
2 x AD8561 - Comparator - 8-lead PDIP
1 x LTC1485 - Differential bus transceiver - 8-lead PDIP
1 x LTC1043 - Precision switched-capacitor building block - 8-lead PDIP

TRANSISTORS AND MOSFETS
3 x 2N3904 - Small-signal NPN transistor
3 x 2N3906 - Small-signal PNP transistor
1 x IRF510 - Power MOSFET
1 x TIP31CFS - NPN power transistor
1 x TIP32CFS - PNP power transistor
1 x ZVN2110A - N-channel DMOS FET
2 x ZVN3310 - N-channel MOSFET
2 x ZVP2110A - P-channel MOSFET

LOGIC ICS
1 x SN74HC08 - Quad AND gate - 14-lead PDIP
1 x SN74HC32 - Quad OR gate - 14-lead PDIP
1 x SN74HC273 - Octal flip-flop
1 x SN74HC04 - Hex inverter - 14-lead PDIP

Note: The printed card appears to describe the SN74HC273 as a 14-lead PDIP, but this part is normally supplied in a larger package. Check the physical IC before relying on the package description.

DIODES
1 x 1N3064 - Small-signal diode
1 x 1N4001 - General-purpose rectifier
1 x 1N4735 - 1 W Zener diode
4 x 1N914 - Fast-switching diode

LEDS AND INFRARED COMPONENTS
2 x Green LED
2 x Yellow LED
2 x Red LED
1 x QED123 - Infrared LED
1 x QSD123 - Infrared phototransistor

POTENTIOMETERS
1 x 5 kOhm
2 x 10 kOhm
1 x 50 kOhm

RESISTORS
5 x 1.1 Ohm
5 x 10 Ohm
5 x 47 Ohm
5 x 68 Ohm
5 x 100 Ohm
5 x 470 Ohm
5 x 1 kOhm
5 x 1.5 kOhm
5 x 2.2 kOhm
5 x 4.7 kOhm
5 x 6.8 kOhm
5 x 10 kOhm
5 x 20 kOhm
5 x 47 kOhm
5 x 68 kOhm
5 x 100 kOhm
5 x 200 kOhm
5 x 470 kOhm
5 x 1 MOhm
5 x 5 MOhm
1 x 6.2 Ohm, 10 W power resistor

CAPACITORS
2 x 39 pF
2 x 100 pF
2 x 0.001 uF
2 x 0.0047 uF
2 x 0.01 uF
2 x 0.047 uF
2 x 0.1 uF
2 x 1 uF
2 x 4.7 uF
2 x 10 uF
2 x 22 uF
2 x 47 uF
1 x 220 uF

INDUCTORS AND MAGNETICS
2 x RFB0807-1R0L - 1.0 uH
2 x RFB0807-100L - 10 uH
2 x RFB0807-101L - 100 uH
2 x RFB0807-102L - 1 mH
2 x RFB0807-103L - 10 mH
1 x HPH1-1400L - Hexa-Path magnetics - Breakout board
1 x HPH1-0190L - Hexa-Path magnetics - Breakout board

OTHER HARDWARE
1 x Speaker
1 x Solderless breadboard
1 x Flathead screwdriver
1 x USB connector breakout board
1 x Audio connector breakout board
45 x Jumper wires with pin ends

BOB = breakout board for a surface-mount device.

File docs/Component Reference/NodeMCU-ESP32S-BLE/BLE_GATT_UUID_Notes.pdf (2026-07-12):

PocketLab BLE reference | Page 1

# PocketLab BLE GATT and UUID Notes

A compact reference for custom BLE services, characteristics, properties, and addressing.

BLE Device

GATT Server

Service

Characteristic

Descriptor

## 1. UUIDs

A UUID is the address used to identify a BLE service, characteristic, or descriptor. The client uses the service UUID to find a subsystem and the characteristic UUID to find a specific value or command inside it.

## 2. Standard vs. custom UUIDs

Bluetooth SIG defines standard short UUIDs, such as 0x180F for Battery Service. Private projects should use custom 128-bit UUIDs because commands such as SET_FREQ or OUTPUT ON are application-specific.

## 3. GATT server and client

GATT means Generic Attribute Profile. In PocketLab, the ESP32 is the GATT server because it owns the data structure. The phone or laptop is the GATT client because it connects, discovers, reads, writes, and subscribes.

## 4. Services

A service groups related characteristics. One PocketLab service may contain command, response, device-state, and firmware-information characteristics. Larger systems can later separate instruments into multiple services.

## 5. Characteristics

A characteristic holds a value and declares which operations are permitted. Its UUID identifies it; its properties define whether it can be read, written, notified, or indicated.

## 6. Characteristic properties

Read: client asks for the current value. Write with response: client sends a value and waits for a GATT acknowledgment; nRF Connect calls this a Request. Write without response: client sends without acknowledgment; nRF Connect calls this a Command. Notify: server pushes updates to a subscribed client. Indicate: like notify, but the client confirms receipt.

## 7. Descriptors

Descriptors provide metadata about a characteristic. The most common is 0x2902, the Client Characteristic Configuration Descriptor, which enables notifications or indications. BLE libraries usually manage it automatically when the app subscribes.

## 8. PocketLab current structure

The minimal test uses one custom service and one characteristic with Read, Write, and Write Without Response. The phone writes PING, the ESP32 onWrite callback runs, and a later read returns PING.

## 9. Recommended PocketLab structure

Use a Command RX characteristic for phone-to-ESP32 writes and a Response TX characteristic for ESP32-to-phone reads or notifications. A separate Device State characteristic can expose current settings and notify when they change.

## 10. RX and TX naming

RX and TX are named from the ESP32 peripheral perspective. Command RX means the ESP32 receives commands there. Response TX means the ESP32 transmits responses there.

## 11. Advertising vs. GATT

Advertising is how the ESP32 announces itself before connection, using a small packet containing items such as device name or service UUID. GATT is the full data structure discovered after connection. The advertisement does not need to list every characteristic.

## 12. How a BLE write is addressed

A write needs three things: the active device connection, the service UUID, and the characteristic UUID. All three must belong to the same current connection. This is why stale Device objects can cause confusing failures even when the UUIDs are correct.

## 13. UUIDs do not define behavior

A UUID is only an identifier. Behavior comes from characteristic properties, server callbacks, and the application protocol. Both sides must agree that a given characteristic carries commands such as PING or SET_FREQ 1000.

## 14. Useful analogy

Think of a BLE service as an API namespace, a characteristic as an endpoint, a UUID as the endpoint address, Read as GET, Write as POST or PUT, and Notify as a server-pushed event. The analogy is not exact, but it is useful.

# Custom UUID Rules

Use these rules when creating PocketLab services and characteristics.

Format | Use 128-bit UUIDs: xxxxxxxx-xxxx-xxxx-xxxx-xxxxxxxxxxxx
Characters | Hexadecimal only: 0-9 and a-f. Uppercase or lowercase is acceptable.
Generation | Generate a random UUID with PowerShell: [guid]::NewGuid()
Short UUIDs | Do not invent custom 16-bit or 32-bit UUIDs; those spaces are intended for Bluetooth SIG assignments.
Uniqueness | Keep every service and characteristic UUID unique within the design.
Avoid | Do not use 00000000-0000-0000-0000-000000000000.
Behavior | The UUID does not determine Read, Write, Notify, or protocol meaning. Code and properties do.

## Example PocketLab UUID family

Service: 7a110001-2d44-4a73-a8f1-3d9ea01c0001 Command RX: 7a110002-2d44-4a73-a8f1-3d9ea01c0001 Response TX: 7a110003-2d44-4a73-a8f1-3d9ea01c0001 Device State: 7a110004-2d44-4a73-a8f1-3d9ea01c0001

## Recommended PocketLab GATT layout

Object | Properties | Purpose
PocketLab Service | - | Groups the custom PocketLab protocol.
Command RX | Write, Write Without Response | Phone sends commands to the ESP32.
Response TX | Read, Notify | ESP32 returns command responses.
Device State | Read, Notify | Current frequency, waveform, amplitude, offset, and output state.

## PocketLab communication flow

ESP32 advertises PocketLab service
-> Phone discovers and connects
-> Phone discovers services and characteristics -> Phone writes a command to Command RX
-> ESP32 parses the command in onWrite()
-> ESP32 sends a response through Response TX
-> Phone receives the response by read or notification

## Key rule

After connecting and discovering services, keep one authoritative connected Device object and use that same object for reads, writes, notifications, and connection checks.

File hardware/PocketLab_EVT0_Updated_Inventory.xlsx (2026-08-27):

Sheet: Summary
PocketLab EVT-0 - DigiKey Inventory
Reconciled from shipped quantities on four DigiKey packing lists; user-confirmed items are tracked separately.
Packlists |  | Shipped line items |  | Total units shipped |  | Unique DigiKey MPNs
4 |  | 51 |  | 571 |  | 51
Packing-list reconciliation
Source PDF | Invoice | Sales Order | Order Date | Document Date | Line Items | Units Shipped | Status
DK_PACKLIST_129266064(1).pdf | 129266064 | 100418268 | 2026-07-15 | 2026-07-15 | 3 | 9 | Complete
DK_PACKLIST_129819844(1).pdf | 129819844 | 100611278 | 2026-07-25 | 2026-07-27 | 10 | 101 | Complete
DK_PACKLIST_130620885(1).pdf | 130620885 | 100887148 | 2026-08-08 | 2026-08-09 | 7 | 41 | Complete
DK_PACKLIST_131043164.pdf | 131043164 | 101027459 | 2026-08-17 | 2026-08-18 | 31 | 420 | Complete
Source notes
• Quantities represent items shipped on the attached packing lists; Qty Used is intentionally initialized to zero.
• DK_PACKLIST_131043164.pdf confirms 10 × GRM21BR61C226ME44L, 22 µF / 16 V / X5R / 0805, with zero backordered.
• MDBT50Q-1MV2 modules are user-confirmed on hand and are excluded from DigiKey shipment totals.
• RGV3216P-3004-B-T1 is normalized to 3 MΩ; the earlier inventory sheet incorrectly described it as 30 MΩ.

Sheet: DigiKey Inventory
Category | Manufacturer | Manufacturer Part Number | DigiKey Part Number | Normalized Description | Total Shipped | Qty Used | Qty Available | Packlist Invoice | Verification | Notes
Capacitors | KEMET | C0805C103K5RACTU | 399-C0805C103K5RACTUCT-ND | CAP CER 10000PF 50V X7R 0805 | 10 | 0 | 10 | 131043164 | Verified shipped
Capacitors | KEMET | C0805C104K3RACTU | 399-C0805C104K3RACTUCT-ND | CAP CER 0.1UF 25V X7R 0805 | 100 | 0 | 100 | 131043164 | Verified shipped
Capacitors | KEMET | C0805C220J5GACTU | 399-C0805C220J5GACTUCT-ND | CAP CER 22PF 50V C0G/NP0 0805 | 10 | 0 | 10 | 131043164 | Verified shipped
Capacitors | KYOCERA AVX | 0805YD106KAT2A | 478-5165-1-ND | CAP CER 10UF 16V X5R 0805 | 50 | 0 | 50 | 131043164 | Verified shipped
Capacitors | Murata Electronics | GRM21BR61C226ME44L | 490-10747-1-ND | CAP CER 22UF 16V X5R 0805 | 10 | 0 | 10 | 131043164 | Verified shipped
Capacitors | Murata Electronics | GRM21BR71C105KA01L | 490-1691-1-ND | CAP CER 1UF 16V X7R 0805 | 50 | 0 | 50 | 131043164 | Verified shipped
Capacitors | Murata Electronics | GRM21BR71C225KA12L | 490-3906-1-ND | CAP CER 2.2UF 16V X7R 0805 | 10 | 0 | 10 | 131043164 | Verified shipped
Capacitors | Murata Electronics | GRM21BR71C475KE51L | 490-14466-1-ND | CAP CER 4.7UF 16V X7R 0805 | 10 | 0 | 10 | 131043164 | Verified shipped
Connectors | GCT | USB4105-GF-A | 2073-USB4105-GF-ACT-ND | CONN RCP USB2.0 TYP C 16P SMD RA | 3 | 0 | 3 | 131043164 | Verified shipped
Connectors | JST Sales America Inc. | S2B-PH-SM4-TB | 455-S2B-PH-SM4-TBCT-ND | CONN HEADER SMD R/A 2POS 2MM | 3 | 0 | 3 | 131043164 | Verified shipped
Connectors | Samtec Inc. | FTSH-105-01-L-DV-K | SAM8799-ND | CONN HEADER SMD 10POS 1.27MM | 2 | 0 | 2 | 131043164 | Verified shipped
Crystals | Raltron Electronics | RT3215-32.768-12.5-TR-10PPM | 2151-RT3215-32.768-12.5-TR-10PPMCT-ND | CRYSTAL 32.7680KHZ 12.5PF SMD | 3 | 0 | 3 | 131043164 | Verified shipped
Diodes & Protection | Diodes Incorporated | BAV199-7-F | BAV199-FDICT-ND | DIODE ARRAY GP 85V 140MA SOT23-3 | 10 | 0 | 10 | 129819844 | Verified shipped
Diodes & Protection | Nexperia USA Inc. | PTVS60VP1UP,115 | 1727-4448-1-ND | TVS DIODE 60VWM 96.8VC SOD1285 | 10 | 0 | 10 | 131043164 | Verified shipped
Diodes & Protection | onsemi | 1N914BWT | 1N914BWTCT-ND | DIODE STANDARD 75V 200MA SOD523F | 10 | 0 | 10 | 131043164 | Verified shipped
Diodes & Protection | STMicroelectronics | BAT54SFILMY | 497-12132-1-ND | DIODE ARR SCHOTT 40V 300MA SOT23 | 10 | 0 | 10 | 129819844 | Verified shipped
Diodes & Protection | Texas Instruments | TPD2E001DRLR | 296-21883-1-ND | TVS DIODE 5.5VWM SOT5 | 2 | 0 | 2 | 131043164 | Verified shipped
Fuses & Protection | Bourns Inc. | MF-R010-2 | 118-MF-R010-2CT-ND | PTC RESET FUSE 60V 100MA RADIAL | 5 | 0 | 5 | 130620885 | Verified shipped
ICs - ADC | Texas Instruments | ADS1220IPWR | 296-39851-1-ND | IC ADC 24BIT 16-TSSOP | 2 | 0 | 2 | 129819844 | Verified shipped
ICs - Amplifiers | Texas Instruments | OPA197IDGKR | 296-44205-1-ND | IC OPAMP GP 1 CIRCUIT 8VSSOP | 4 | 0 | 4 | 129819844 | Verified shipped
ICs - Amplifiers | Texas Instruments | TLV9154IDR | 296-TLV9154IDRCT-ND | IC OPAMP GP 4 CIRCUIT 14SOIC | 4 | 0 | 4 | 129266064 | Verified shipped
ICs - Analog Switching | Texas Instruments | TMUX1108PWR | 296-53256-1-ND | IC MUX 8:1 4OHM 16TSSOP | 2 | 0 | 2 | 130620885 | Verified shipped
ICs - Analog Switching | Texas Instruments | TMUX1109PWR | 296-53438-1-ND | IC MUX DUAL 4:1 4OHM 16TSSOP | 2 | 0 | 2 | 130620885 | Verified shipped
ICs - Analog Switching | Texas Instruments | TMUX7462FPWR | 296-TMUX7462FPWRCT-ND | 60-V FAULT-PROTECTED, LATCH-UP I | 2 | 0 | 2 | 131043164 | Verified shipped
ICs - Comparator | Texas Instruments | TLV3501AIDR | 296-43611-1-ND | IC COMPARATOR 1CH 8-SOIC | 3 | 0 | 3 | 129266064 | Verified shipped
ICs - Digital Potentiometer | Renesas Electronics Corporation | ISL23415WFUZ | ISL23415WFUZ-ND | IC DIG POT 10K 10-MSOP | 3 | 0 | 3 | 129819844 | Verified shipped
ICs - Power Management | Texas Instruments | BQ25180YBGR | 296-BQ25180YBGRCT-ND | 1-A LI-ION IC PROGRAMMABLE CHARG | 3 | 0 | 3 | 131043164 | Verified shipped
ICs - Power Management | Texas Instruments | LM27762DSSR | 296-47331-1-ND | IC REG CHARGE PUMP ADJ DL 12WSON | 2 | 0 | 2 | 131043164 | Verified shipped
ICs - Power Management | Texas Instruments | TPS63900DSKR | 296-TPS63900DSKRCT-ND | IC REG BUCK BST PROG 400MA 10SON | 4 | 0 | 4 | 131043164 | Verified shipped
ICs - Power Management | Texas Instruments | TPS7A3901DSCR | 296-TPS7A3901DSCRCT-ND | IC REG LINEAR POS/NEG ADJ 10WSON | 2 | 0 | 2 | 131043164 | Verified shipped
Inductors | Würth Elektronik | 74479275222 | 732-9708-1-ND | FIXED IND 2.2UH 2A 190 MOHM SMD | 4 | 0 | 4 | 131043164 | Verified shipped
Power Modules | Traco Power | TMA 0505D | 1951-2715-ND | DC DC CONVERTER +/-5V 1W | 2 | 0 | 2 | 129266064 | Verified shipped
Relays | Coto Technology | 9201-05-00TR | 306-1389-1-ND | RELAY REED SPST 500MA 5V | 2 | 0 | 2 | 129819844 | Verified shipped
Relays | Panasonic Industry | TQ2-3V | 255-1225-5-ND | RELAY TELECOM DPDT 1A 3V | 2 | 0 | 2 | 130620885 | Verified shipped
Resistors | Stackpole Electronics Inc. | RNCF0805TKY10K0 | RNCF0805TKY10K0CT-ND | RES SMD 10K OHM 0.01% 1/8W 0805 | 10 | 0 | 10 | 129819844 | Verified shipped
Resistors | Susumu | RGV3216P-3004-B-T1 | 408-RGV3216P-3004-B-T1CT-ND | RES 3M OHM 0.1% 1/4W 1206, thin-film anti-sulfur | 20 | 0 | 20 | 129819844 | Verified shipped | 3004 is 3 MΩ. Corrected from the earlier inventory-sheet typo of 30 MΩ; packlist description omitted the value.
Resistors | Susumu | RGV3216P-3603-B-T1 | 408-RGV3216P-3603-B-T1CT-ND | RES 360K OHM 0.1% 1/4W 1206 | 20 | 0 | 20 | 129819844 | Verified shipped
Resistors | Susumu | RGV3216P-6203-B-T1 | 408-RGV3216P-6203-B-T1CT-ND | RES 620K OHM 0.1% 1/4W 1206 | 20 | 0 | 20 | 129819844 | Verified shipped
Resistors | TE Connectivity Passive Product | CPF-A-0805B100KE1 | 1712-CPF-A-0805B100KE1CT-ND | RES SMD 100K OHM 0.1% 1/10W 0805 | 10 | 0 | 10 | 130620885 | Verified shipped
Resistors | TE Connectivity Passive Product | CPF-A-0805B1M0E1 | 1712-CPF-A-0805B1M0E1CT-ND | RES SMD 1M OHM 0.1% 1/10W 0805 | 10 | 0 | 10 | 130620885 | Verified shipped
Resistors | Vishay | MCA1206MD1005BP500 | 749-MCA1206MD1005BP500CT-ND | RES 10M OHM 0.1% 0.52W 1206 | 10 | 0 | 10 | 130620885 | Verified shipped
Resistors | YAGEO | RC0805FR-0711KL | 311-11.0KCRCT-ND | RES 11K OHM 1% 1/8W 0805 | 10 | 0 | 10 | 131043164 | Verified shipped
Resistors | YAGEO | RC0805FR-0716K2L | 311-16.2KCRCT-ND | RES 16.2K OHM 1% 1/8W 0805 | 10 | 0 | 10 | 131043164 | Verified shipped
Resistors | YAGEO | RC0805FR-0721KL | 311-21.0KCRCT-ND | RES 21K OHM 1% 1/8W 0805 | 10 | 0 | 10 | 131043164 | Verified shipped
Resistors | YAGEO | RC0805FR-07270KL | 311-270KCRCT-ND | RES 270K OHM 1% 1/8W 0805 | 10 | 0 | 10 | 131043164 | Verified shipped
Resistors | YAGEO | RC0805FR-07274KL | 311-274KCRCT-ND | RES 274K OHM 1% 1/8W 0805 | 10 | 0 | 10 | 131043164 | Verified shipped
Resistors | YAGEO | RC0805FR-0727RL | 311-27.0CRCT-ND | RES 27 OHM 1% 1/8W 0805 | 10 | 0 | 10 | 131043164 | Verified shipped
Resistors | YAGEO | RC0805FR-0736K5L | 311-36.5KCRCT-ND | RES 36.5K OHM 1% 1/8W 0805 | 25 | 0 | 25 | 131043164 | Verified shipped
Resistors | YAGEO | RC0805FR-078K25L | 311-8.25KCRCT-ND | RES 8.25K OHM 1% 1/8W 0805 | 10 | 0 | 10 | 131043164 | Verified shipped
Sensors | Murata Electronics | NCU18XH103F6SRB | 490-18139-1-ND | THERMISTOR NTC 10KOHM 3380K 0603 | 5 | 0 | 5 | 131043164 | Verified shipped
Transistors | onsemi | MMBT3904LT1G | MMBT3904LT1GOSCT-ND | TRANS NPN 40V 0.2A SOT23-3 | 20 | 0 | 20 | 131043164 | Verified shipped

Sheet: Packlist Detail
Invoice | Order Date | Document Date | Line | Category | Manufacturer Part Number | DigiKey Part Number | Manufacturer | Qty Ordered | Qty Shipped | Qty Backordered | Packlist Description | Source PDF
129266064 | 2026-07-15 | 2026-07-15 | 1 | Power Modules | TMA 0505D | 1951-2715-ND | Traco Power | 2 | 2 | 0 | DC DC CONVERTER +/-5V 1W | DK_PACKLIST_129266064(1).pdf
129266064 | 2026-07-15 | 2026-07-15 | 2 | ICs - Comparator | TLV3501AIDR | 296-43611-1-ND | Texas Instruments | 3 | 3 | 0 | IC COMPARATOR 1CH 8-SOIC | DK_PACKLIST_129266064(1).pdf
129266064 | 2026-07-15 | 2026-07-15 | 3 | ICs - Amplifiers | TLV9154IDR | 296-TLV9154IDRCT-ND | Texas Instruments | 4 | 4 | 0 | IC OPAMP GP 4 CIRCUIT 14SOIC | DK_PACKLIST_129266064(1).pdf
129819844 | 2026-07-25 | 2026-07-27 | 1 | Resistors | RGV3216P-3004-B-T1 | 408-RGV3216P-3004-B-T1CT-ND | Susumu | 20 | 20 | 0 | RESISTOR THIN FILM ANTIC SULFUR | DK_PACKLIST_129819844(1).pdf
129819844 | 2026-07-25 | 2026-07-27 | 2 | Resistors | RGV3216P-3603-B-T1 | 408-RGV3216P-3603-B-T1CT-ND | Susumu | 20 | 20 | 0 | RES 360K OHM 0.1% 1/4W 1206 | DK_PACKLIST_129819844(1).pdf
129819844 | 2026-07-25 | 2026-07-27 | 3 | Resistors | RGV3216P-6203-B-T1 | 408-RGV3216P-6203-B-T1CT-ND | Susumu | 20 | 20 | 0 | RES 620K OHM 0.1% 1/4W 1206 | DK_PACKLIST_129819844(1).pdf
129819844 | 2026-07-25 | 2026-07-27 | 4 | ICs - Amplifiers | OPA197IDGKR | 296-44205-1-ND | Texas Instruments | 4 | 4 | 0 | IC OPAMP GP 1 CIRCUIT 8VSSOP | DK_PACKLIST_129819844(1).pdf
129819844 | 2026-07-25 | 2026-07-27 | 5 | Diodes & Protection | BAV199-7-F | BAV199-FDICT-ND | Diodes Incorporated | 10 | 10 | 0 | DIODE ARRAY GP 85V 140MA SOT23-3 | DK_PACKLIST_129819844(1).pdf
129819844 | 2026-07-25 | 2026-07-27 | 6 | Diodes & Protection | BAT54SFILMY | 497-12132-1-ND | STMicroelectronics | 10 | 10 | 0 | DIODE ARR SCHOTT 40V 300MA SOT23 | DK_PACKLIST_129819844(1).pdf
129819844 | 2026-07-25 | 2026-07-27 | 7 | Relays | 9201-05-00TR | 306-1389-1-ND | Coto Technology | 2 | 2 | 0 | RELAY REED SPST 500MA 5V | DK_PACKLIST_129819844(1).pdf
129819844 | 2026-07-25 | 2026-07-27 | 8 | ICs - Digital Potentiometer | ISL23415WFUZ | ISL23415WFUZ-ND | Renesas Electronics Corporation | 3 | 3 | 0 | IC DIG POT 10K 10-MSOP | DK_PACKLIST_129819844(1).pdf
129819844 | 2026-07-25 | 2026-07-27 | 9 | ICs - ADC | ADS1220IPWR | 296-39851-1-ND | Texas Instruments | 2 | 2 | 0 | IC ADC 24BIT 16-TSSOP | DK_PACKLIST_129819844(1).pdf
129819844 | 2026-07-25 | 2026-07-27 | 10 | Resistors | RNCF0805TKY10K0 | RNCF0805TKY10K0CT-ND | Stackpole Electronics Inc. | 10 | 10 | 0 | RES SMD 10K OHM 0.01% 1/8W 0805 | DK_PACKLIST_129819844(1).pdf
130620885 | 2026-08-08 | 2026-08-09 | 1 | ICs - Analog Switching | TMUX1109PWR | 296-53438-1-ND | Texas Instruments | 2 | 2 | 0 | IC MUX DUAL 4:1 4OHM 16TSSOP | DK_PACKLIST_130620885(1).pdf
130620885 | 2026-08-08 | 2026-08-09 | 2 | ICs - Analog Switching | TMUX1108PWR | 296-53256-1-ND | Texas Instruments | 2 | 2 | 0 | IC MUX 8:1 4OHM 16TSSOP | DK_PACKLIST_130620885(1).pdf
130620885 | 2026-08-08 | 2026-08-09 | 3 | Relays | TQ2-3V | 255-1225-5-ND | Panasonic Industry | 2 | 2 | 0 | RELAY TELECOM DPDT 1A 3V | DK_PACKLIST_130620885(1).pdf
130620885 | 2026-08-08 | 2026-08-09 | 4 | Resistors | CPF-A-0805B1M0E1 | 1712-CPF-A-0805B1M0E1CT-ND | TE Connectivity Passive Product | 10 | 10 | 0 | RES SMD 1M OHM 0.1% 1/10W 0805 | DK_PACKLIST_130620885(1).pdf
130620885 | 2026-08-08 | 2026-08-09 | 5 | Resistors | CPF-A-0805B100KE1 | 1712-CPF-A-0805B100KE1CT-ND | TE Connectivity Passive Product | 10 | 10 | 0 | RES SMD 100K OHM 0.1% 1/10W 0805 | DK_PACKLIST_130620885(1).pdf
130620885 | 2026-08-08 | 2026-08-09 | 6 | Resistors | MCA1206MD1005BP500 | 749-MCA1206MD1005BP500CT-ND | Vishay | 10 | 10 | 0 | RES 10M OHM 0.1% 0.52W 1206 | DK_PACKLIST_130620885(1).pdf
130620885 | 2026-08-08 | 2026-08-09 | 7 | Fuses & Protection | MF-R010-2 | 118-MF-R010-2CT-ND | Bourns Inc. | 5 | 5 | 0 | PTC RESET FUSE 60V 100MA RADIAL | DK_PACKLIST_130620885(1).pdf
131043164 | 2026-08-17 | 2026-08-18 | 1 | Diodes & Protection | 1N914BWT | 1N914BWTCT-ND | onsemi | 10 | 10 | 0 | DIODE STANDARD 75V 200MA SOD523F | DK_PACKLIST_131043164.pdf
131043164 | 2026-08-17 | 2026-08-18 | 2 | Transistors | MMBT3904LT1G | MMBT3904LT1GOSCT-ND | onsemi | 20 | 20 | 0 | TRANS NPN 40V 0.2A SOT23-3 | DK_PACKLIST_131043164.pdf
131043164 | 2026-08-17 | 2026-08-18 | 3 | ICs - Power Management | LM27762DSSR | 296-47331-1-ND | Texas Instruments | 2 | 2 | 0 | IC REG CHARGE PUMP ADJ DL 12WSON | DK_PACKLIST_131043164.pdf
131043164 | 2026-08-17 | 2026-08-18 | 4 | ICs - Analog Switching | TMUX7462FPWR | 296-TMUX7462FPWRCT-ND | Texas Instruments | 2 | 2 | 0 | 60-V FAULT-PROTECTED, LATCH-UP I | DK_PACKLIST_131043164.pdf
131043164 | 2026-08-17 | 2026-08-18 | 5 | Diodes & Protection | PTVS60VP1UP,115 | 1727-4448-1-ND | Nexperia USA Inc. | 10 | 10 | 0 | TVS DIODE 60VWM 96.8VC SOD1285 | DK_PACKLIST_131043164.pdf
131043164 | 2026-08-17 | 2026-08-18 | 6 | ICs - Power Management | BQ25180YBGR | 296-BQ25180YBGRCT-ND | Texas Instruments | 3 | 3 | 0 | 1-A LI-ION IC PROGRAMMABLE CHARG | DK_PACKLIST_131043164.pdf
131043164 | 2026-08-17 | 2026-08-18 | 7 | ICs - Power Management | TPS63900DSKR | 296-TPS63900DSKRCT-ND | Texas Instruments | 4 | 4 | 0 | IC REG BUCK BST PROG 400MA 10SON | DK_PACKLIST_131043164.pdf
131043164 | 2026-08-17 | 2026-08-18 | 8 | Inductors | 74479275222 | 732-9708-1-ND | Würth Elektronik | 4 | 4 | 0 | FIXED IND 2.2UH 2A 190 MOHM SMD | DK_PACKLIST_131043164.pdf
131043164 | 2026-08-17 | 2026-08-18 | 9 | ICs - Power Management | TPS7A3901DSCR | 296-TPS7A3901DSCRCT-ND | Texas Instruments | 2 | 2 | 0 | IC REG LINEAR POS/NEG ADJ 10WSON | DK_PACKLIST_131043164.pdf
131043164 | 2026-08-17 | 2026-08-18 | 10 | Sensors | NCU18XH103F6SRB | 490-18139-1-ND | Murata Electronics | 5 | 5 | 0 | THERMISTOR NTC 10KOHM 3380K 0603 | DK_PACKLIST_131043164.pdf
131043164 | 2026-08-17 | 2026-08-18 | 11 | Connectors | S2B-PH-SM4-TB | 455-S2B-PH-SM4-TBCT-ND | JST Sales America Inc. | 3 | 3 | 0 | CONN HEADER SMD R/A 2POS 2MM | DK_PACKLIST_131043164.pdf
131043164 | 2026-08-17 | 2026-08-18 | 12 | Crystals | RT3215-32.768-12.5-TR-10PPM | 2151-RT3215-32.768-12.5-TR-10PPMCT-ND | Raltron Electronics | 3 | 3 | 0 | CRYSTAL 32.7680KHZ 12.5PF SMD | DK_PACKLIST_131043164.pdf
131043164 | 2026-08-17 | 2026-08-18 | 13 | Connectors | USB4105-GF-A | 2073-USB4105-GF-ACT-ND | GCT | 3 | 3 | 0 | CONN RCP USB2.0 TYP C 16P SMD RA | DK_PACKLIST_131043164.pdf
131043164 | 2026-08-17 | 2026-08-18 | 14 | Connectors | FTSH-105-01-L-DV-K | SAM8799-ND | Samtec Inc. | 2 | 2 | 0 | CONN HEADER SMD 10POS 1.27MM | DK_PACKLIST_131043164.pdf
131043164 | 2026-08-17 | 2026-08-18 | 15 | Diodes & Protection | TPD2E001DRLR | 296-21883-1-ND | Texas Instruments | 2 | 2 | 0 | TVS DIODE 5.5VWM SOT5 | DK_PACKLIST_131043164.pdf
131043164 | 2026-08-17 | 2026-08-18 | 16 | Resistors | RC0805FR-0727RL | 311-27.0CRCT-ND | YAGEO | 10 | 10 | 0 | RES 27 OHM 1% 1/8W 0805 | DK_PACKLIST_131043164.pdf
131043164 | 2026-08-17 | 2026-08-18 | 17 | Resistors | RC0805FR-078K25L | 311-8.25KCRCT-ND | YAGEO | 10 | 10 | 0 | RES 8.25K OHM 1% 1/8W 0805 | DK_PACKLIST_131043164.pdf
131043164 | 2026-08-17 | 2026-08-18 | 18 | Resistors | RC0805FR-0711KL | 311-11.0KCRCT-ND | YAGEO | 10 | 10 | 0 | RES 11K OHM 1% 1/8W 0805 | DK_PACKLIST_131043164.pdf
131043164 | 2026-08-17 | 2026-08-18 | 19 | Resistors | RC0805FR-0716K2L | 311-16.2KCRCT-ND | YAGEO | 10 | 10 | 0 | RES 16.2K OHM 1% 1/8W 0805 | DK_PACKLIST_131043164.pdf
131043164 | 2026-08-17 | 2026-08-18 | 20 | Resistors | RC0805FR-0721KL | 311-21.0KCRCT-ND | YAGEO | 10 | 10 | 0 | RES 21K OHM 1% 1/8W 0805 | DK_PACKLIST_131043164.pdf
131043164 | 2026-08-17 | 2026-08-18 | 21 | Resistors | RC0805FR-0736K5L | 311-36.5KCRCT-ND | YAGEO | 25 | 25 | 0 | RES 36.5K OHM 1% 1/8W 0805 | DK_PACKLIST_131043164.pdf
131043164 | 2026-08-17 | 2026-08-18 | 22 | Resistors | RC0805FR-07270KL | 311-270KCRCT-ND | YAGEO | 10 | 10 | 0 | RES 270K OHM 1% 1/8W 0805 | DK_PACKLIST_131043164.pdf
131043164 | 2026-08-17 | 2026-08-18 | 23 | Resistors | RC0805FR-07274KL | 311-274KCRCT-ND | YAGEO | 10 | 10 | 0 | RES 274K OHM 1% 1/8W 0805 | DK_PACKLIST_131043164.pdf
131043164 | 2026-08-17 | 2026-08-18 | 24 | Capacitors | C0805C104K3RACTU | 399-C0805C104K3RACTUCT-ND | KEMET | 100 | 100 | 0 | CAP CER 0.1UF 25V X7R 0805 | DK_PACKLIST_131043164.pdf
131043164 | 2026-08-17 | 2026-08-18 | 25 | Capacitors | GRM21BR71C105KA01L | 490-1691-1-ND | Murata Electronics | 50 | 50 | 0 | CAP CER 1UF 16V X7R 0805 | DK_PACKLIST_131043164.pdf
131043164 | 2026-08-17 | 2026-08-18 | 26 | Capacitors | GRM21BR71C225KA12L | 490-3906-1-ND | Murata Electronics | 10 | 10 | 0 | CAP CER 2.2UF 16V X7R 0805 | DK_PACKLIST_131043164.pdf
131043164 | 2026-08-17 | 2026-08-18 | 27 | Capacitors | GRM21BR71C475KE51L | 490-14466-1-ND | Murata Electronics | 10 | 10 | 0 | CAP CER 4.7UF 16V X7R 0805 | DK_PACKLIST_131043164.pdf
131043164 | 2026-08-17 | 2026-08-18 | 28 | Capacitors | 0805YD106KAT2A | 478-5165-1-ND | KYOCERA AVX | 50 | 50 | 0 | CAP CER 10UF 16V X5R 0805 | DK_PACKLIST_131043164.pdf
131043164 | 2026-08-17 | 2026-08-18 | 29 | Capacitors | C0805C103K5RACTU | 399-C0805C103K5RACTUCT-ND | KEMET | 10 | 10 | 0 | CAP CER 10000PF 50V X7R 0805 | DK_PACKLIST_131043164.pdf
131043164 | 2026-08-17 | 2026-08-18 | 30 | Capacitors | C0805C220J5GACTU | 399-C0805C220J5GACTUCT-ND | KEMET | 10 | 10 | 0 | CAP CER 22PF 50V C0G/NP0 0805 | DK_PACKLIST_131043164.pdf
131043164 | 2026-08-17 | 2026-08-18 | 31 | Capacitors | GRM21BR61C226ME44L | 490-10747-1-ND | Murata Electronics | 10 | 10 | 0 | CAP CER 22UF 16V X5R 0805 | DK_PACKLIST_131043164.pdf

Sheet: User Confirmed
User-confirmed on-hand items not included in DigiKey shipment totals
Category | Manufacturer Part Number | Description | Qty Confirmed | Qty Used | Qty Available | Evidence / Notes
BLE MCU Modules | MDBT50Q-1MV2 | Raytac nRF52840 BLE module with chip antenna | 3 | 0 | 3 | Quantity confirmed directly by the user on 2026-08-21; not present in the supplied packing lists.

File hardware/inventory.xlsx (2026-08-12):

MFG# | QTY | Description | Intention | In Use | Notes | Vendor
Function Generator
TMA 0505D | 2 | DC DC Converter +/- 5V 1W | FG: 10V output envelope | Yes | Powered by 4.7 V produced approx. +/- 5.12 V output | DigiKey
OP484 | 1 | IC OP Amp x 4 | FG: amplify signal to desired range | No | Replaced with TLV9154 for its bipolar capabilities | AD Parts kit
TLV9154IDR | 4 | IC BiPolar OP Amp x 4 | FG: amplify signal to desired range | Yes |  | DigiKey
X9C103S | 4 | IC DIG POT 10K | FG: Signal Amplitude Control | No | 32 wiper positions and niosy. Replaced with ISL23415 | Amazon
ISL23415WFUZ | 3 | IC DIG POT 10K | FG: Signal Amplitude Control | YES | 255 wiper position, finer control with less noise | DigiKey
AD9833 | 1 | DDS SIGNAL GENERTOR | FG: SINE, TRIANGLE, SQUARE WAVE GEN | YES | MIGHT BE REPLACED IN THE FUTURE WITH FPGA CONTROL | Amazon
AD5626 | 1 | 12-Bit Digital to Analog Converter | FG: SIGNAL OFFSET CONTROL | YES |  | AD Parts kit
TLV3501AIDR | 3 | IC Comparator 1Ch | FG: TTL/ Digital Square wave generator | No | To be added in future revision | DigiKey
Digial MultiMeter
RGV3216P-3004-B-T1 | 20 | RES 30M OHM 0.1% 1/4W 1206 | DMM: high-side divider |  |  | DigiKey
RGV3216P-3603-B-T1 | 20 | RES 360K OHM 0.1% 1/4W 1206 | DMM: high-side divider |  |  | DigiKey
RGV3216P-6203-B-T1 | 20 | RES 620K OHM 0.1% 1/4W 1206 | DMM: high-side divider |  |  | DigiKey
OPA197IDGKR | 4 | IC OPAMP GP 1 CIRCUIT 8VSSOP | DMM: Precision DMM input buffer |  |  | DigiKey
BAV199-7-F | 10 | DIODE ARRAY GP 85V 140MA SOT23-3 | DMM: Low-leakage input protection/clamping |  |  | DigiKey
BAT54SFILMY | 10 | DIODE ARR SCHOTT 40V 300MA SOT23 | DMM: Schottky clamps protecting the ADC input |  |  | DigiKey
9201-05-00TR | 2 | RELAY REED SPST 500MA 5V | DMM: 5 V reed relay for resistance/diode-mode switching |  |  | DigiKey
ADS1220 ADC Module | 1 | 24 Bit ADC Converter Module | DMM: 24-bit DMM ADC with PGA and current sources |  |  | DigiKey
ADS1220IPWR | 2 | IC ADC 24BIT 16-TSSOP | DMM: 24-bit DMM ADC with PGA and current sources |  |  | Amazon
RNCF0805TKY10K0 | 10 | RES SMD 10K OHM 0.01% 1/8W 0805 | DMM: Precision 10.000 kΩ lower divider resistor |  |  | DigiKey
FEATHER NRF52 BLUEFRUIT LE | 1 | MDBT42Q, nRF52832 - Bluetooth® Smart 4.x Low Energy (BLE) Transceiver 2.4GHz Evaluation Board | DMM: BLE +MCU |  |  | Adafruit
Resistors
Resistor 1% 0.25W | 15 | 1 Ω
Resistor 1% 0.25W | 15 | 1.5 Ω
Resistor 1% 0.25W | 15 | 2.2 Ω
Resistor 1% 0.25W | 15 | 3.3 Ω
Resistor 1% 0.25W | 15 | 4.7 Ω
Resistor 1% 0.25W | 15 | 6.8 Ω
Resistor 1% 0.25W | 15 | 10 Ω
Resistor 1% 0.25W | 15 | 15 Ω
Resistor 1% 0.25W | 15 | 22 Ω
Resistor 1% 0.25W | 15 | 33 Ω
Resistor 1% 0.25W | 15 | 47 Ω
Resistor 1% 0.25W | 15 | 68 Ω
Resistor 1% 0.25W | 20 | 100 Ω
Resistor 1% 0.25W | 20 | 120 Ω
Resistor 1% 0.25W | 20 | 150 Ω
Resistor 1% 0.25W | 20 | 180 Ω
Resistor 1% 0.25W | 20 | 220 Ω
Resistor 1% 0.25W | 20 | 270 Ω
Resistor 1% 0.25W | 20 | 330 Ω
Resistor 1% 0.25W | 20 | 390 Ω
Resistor 1% 0.25W | 20 | 470 Ω
Resistor 1% 0.25W | 20 | 560 Ω
Resistor 1% 0.25W | 20 | 680 Ω
Resistor 1% 0.25W | 20 | 820 Ω
Resistor 1% 0.25W | 20 | 1 kΩ
Resistor 1% 0.25W | 20 | 1.2 kΩ
Resistor 1% 0.25W | 20 | 1.5 kΩ
Resistor 1% 0.25W | 20 | 1.8 kΩ
Resistor 1% 0.25W | 20 | 2.2 kΩ
Resistor 1% 0.25W | 20 | 2.7 kΩ
Resistor 1% 0.25W | 20 | 3.3 kΩ
Resistor 1% 0.25W | 20 | 3.9 kΩ
Resistor 1% 0.25W | 20 | 4.7 kΩ
Resistor 1% 0.25W | 20 | 5.6 kΩ
Resistor 1% 0.25W | 20 | 6.8 kΩ
Resistor 1% 0.25W | 20 | 8.2 kΩ
Resistor 1% 0.25W | 20 | 10 kΩ
Resistor 1% 0.25W | 20 | 12 kΩ
Resistor 1% 0.25W | 20 | 15 kΩ
Resistor 1% 0.25W | 20 | 18 kΩ
Resistor 1% 0.25W | 20 | 22 kΩ
Resistor 1% 0.25W | 20 | 27 kΩ
Resistor 1% 0.25W | 20 | 33 kΩ
Resistor 1% 0.25W | 20 | 39 kΩ
Resistor 1% 0.25W | 20 | 47 kΩ
Resistor 1% 0.25W | 20 | 56 kΩ
Resistor 1% 0.25W | 20 | 68 kΩ
Resistor 1% 0.25W | 20 | 82 kΩ
Resistor 1% 0.25W | 15 | 100 kΩ
Resistor 1% 0.25W | 15 | 150 kΩ
Resistor 1% 0.25W | 15 | 220 kΩ
Resistor 1% 0.25W | 15 | 330 kΩ
Resistor 1% 0.25W | 15 | 470 kΩ
Resistor 1% 0.25W | 15 | 680 kΩ
Resistor 1% 0.25W | 15 | 1 MΩ
Resistor 1% 0.25W | 15 | 1.5 MΩ
Resistor 1% 0.25W | 15 | 2.2 MΩ
Resistor 1% 0.25W | 15 | 3.3 MΩ
Resistor 1% 0.25W | 15 | 4.7 MΩ
Resistor 1% 0.25W | 15 | 6.8 MΩ
Resistor 1% 0.25W | 15 | 10 MΩ
DIODES
P/N | QTY | V(RRM) | I(AV)
1N4001 | 10 | 50 V | 1A
1N4002 | 10 | 100 V | 1A
1N4003 | 10 | 200 V | 1A
1N4004 | 10 | 400 V | 1A
1N4005 | 10 | 600 V | 1A
1N4006 | 10 | 800 V | 1A
1N4007 | 10 | 1000 V | 1A
1N4148 | 10 | 100 V | 200 mA
1N5404 | 10 | 400 V | 3A
1N5406 | 10 | 600 V | 3A
1N5408 | 10 | 1000 V | 3A
RL207 | 10 | 1000 V | 2A
UF4007 | 10 | 1000 V | 1A
FR107 | 10 | 1000 V | 1A
FR207 | 10 | 1000 V | 2A
1N5817 | 10 | 20 V | 1A
1N5819 | 10 | 40 V | 1A
1N5822 | 10 | 40 V | 3A
15SQ045 | 5 | 45 V | 15A
10A10 | 5 | 1000 V | 10A
1N914 | 100 | 100 V | 200mA
CAPACITORS
Type | QTY | Capacitance | Voltage | Marking Code | Dimensions
Ceramic | 10 | 10pF |  | 100
Ceramic | 10 | 20pF |  | 200
Ceramic | 10 | 30pF |  | 300
Ceramic | 10 | 47pF |  | 470
Ceramic | 10 | 56pF |  | 560
Ceramic | 10 | 68pF |  | 680
Ceramic | 10 | 100pF |  | 101
Ceramic | 10 | 220pF |  | 221
Ceramic | 10 | 330pF |  | 331
Ceramic | 10 | 680pF |  | 681
Ceramic | 10 | 1nF |  | 102
Ceramic | 10 | 4.7nF |  | 472
Ceramic | 10 | 10nF |  | 103
Ceramic | 10 | 47nF |  | 473
Ceramic | 10 | 100nF |  | 104
Ceramic | 10 | 0.15µF |  | 154
Ceramic | 10 | 0.22µF |  | 224
Ceramic | 10 | 0.33µF |  | 334
Ceramic | 10 | 0.47µF |  | 474
Ceramic | 10 | 0.68µF |  | 684
Ceramic | 10 | 1µF |  | 105
Ceramic | 10 | 2.2µF |  | 225
Ceramic | 10 | 4.7µF |  | 475
Ceramic | 10 | 10µF |  | 106
Electrolytic | 10 | 0.1µF | 50V |  | 4x7mm
Electrolytic | 10 | 0.22µF | 50V |  | 5x11mm
Electrolytic | 10 | 0.47µF | 50V |  | 5x11mm
Electrolytic | 10 | 1µF | 50V |  | 5x11mm
Electrolytic | 10 | 2.2µF | 50V |  | 4x7mm
Electrolytic | 10 | 3.3µF | 50V |  | 4x7mm
Electrolytic | 10 | 4.7µF | 50V |  | 4x7mm
Electrolytic | 10 | 10µF | 25V |  | 4x7mm
Electrolytic | 10 | 10µF | 50V |  | 5x11mm
Electrolytic | 10 | 22µF | 16V |  | 4x7mm
Electrolytic | 10 | 22µF | 25V |  | 4x7mm
Electrolytic | 10 | 33µF | 16V |  | 4x7mm
Electrolytic | 10 | 47µF | 10V |  | 4x7mm
Electrolytic | 10 | 47µF | 25V |  | 5x11mm
Electrolytic | 10 | 47µF | 50V |  | 6x11mm
Electrolytic | 10 | 100µF | 16V |  | 5x11mm
Electrolytic | 10 | 100µF | 25V |  | 5x11mm
Electrolytic | 10 | 220µF | 10V |  | 5x11mm
Electrolytic | 10 | 220µF | 25V |  | 6x11mm
Electrolytic | 10 | 330µF | 25V |  | 8x12mm
Electrolytic | 10 | 470µF | 10V |  | 6x11mm
Electrolytic | 10 | 470µF | 16V |  | 8x12mm
Electrolytic | 10 | 680µF | 16V |  | 8x12mm
Electrolytic | 10 | 1000µF | 16V |  | 10x16mm
Analog Parts Kit
MFG# | QTY | Description | Intention | In Use | Notes | Vendor
AD8226 | 1 | Instrumentation amplifier (breakout board) |  |  |  | AD Parts kit
ADTL082 | 1 | JFET operational amplifier (breakout board) |  |  |  | AD Parts kit
AD8542 | 1 | CMOS rail-to-rail operational amplifier (breakout board) |  |  |  | AD Parts kit
OP482 | 2 | High-speed JFET operational amplifier, 14-lead PDIP |  |  |  | AD Parts kit
OP484 | 1 | Precision rail-to-rail input/output operational amplifier, 14-lead PDIP |  |  |  | AD Parts kit
OP27 | 2 | Low-noise precision operational amplifier, 8-lead PDIP |  |  |  | AD Parts kit
OP37 | 2 | Precision operational amplifier, 8-lead PDIP |  |  |  | AD Parts kit
OP97 | 2 | Low-power high-precision operational amplifier, 8-lead PDIP |  |  |  | AD Parts kit
LTC1541 | 1 | Micropower amplifier, comparator, and reference (breakout board) |  |  |  | AD Parts kit
AD8210 | 1 | Current-shunt monitor (breakout board) |  |  |  | AD Parts kit
AD22151 | 1 | Magnetic-field sensor (breakout board) |  |  |  | AD Parts kit
ADXL327 | 1 | 3-axis accelerometer (breakout board) |  |  |  | AD Parts kit
AD22100 | 2 | Voltage-output temperature sensor, TO-92 |  |  |  | AD Parts kit
AD592 | 1 | Current-output temperature sensor, TO-92 |  |  |  | AD Parts kit
TMP01 | 1 | Temperature controller, 8-lead PDIP |  |  |  | AD Parts kit
Electret microphone | 1 | Electret microphone |  |  |  | AD Parts kit
10 kΩ thermistor | 1 | Thermistor, 10 kΩ |  |  |  | AD Parts kit
OP999 | 1 | PIN photodiode |  |  |  | AD Parts kit
ADP3300 | 1 | 3.3 V, 50 mA LDO linear regulator (breakout board) |  |  |  | AD Parts kit
LT3092 | 1 | Programmable current source (breakout board) |  |  |  | AD Parts kit
LTM8067 | 1 | Isolated DC-to-DC converter (breakout board) |  |  |  | AD Parts kit
LT3080 | 1 | Adjustable 1.1 A LDO regulator, TO-220 |  |  |  | AD Parts kit
LTC1054 | 1 | Switched-capacitor regulator, 8-lead PDIP |  |  |  | AD Parts kit
AD654 | 1 | Voltage-to-frequency converter, 8-lead PDIP |  |  |  | AD Parts kit
AD5626 | 1 | 12-bit nanoDAC+ (breakout board) |  |  |  | AD Parts kit
AD7091R-5 | 1 | 12-bit 4-channel I²C ADC (breakout board) |  |  |  | AD Parts kit
AD584 | 1 | Programmable voltage reference, 8-lead PDIP |  |  |  | AD Parts kit
AD8561 | 2 | Comparator, 8-lead PDIP |  |  |  | AD Parts kit
LTC1485 | 1 | Differential bus transceiver, 8-lead PDIP |  |  |  | AD Parts kit
LTC1043 | 1 | Precision switched-capacitor building block, 8-lead PDIP |  |  |  | AD Parts kit
Resistor 1.1 Ω | 5 | Through-hole resistor, 1.1 Ω |  |  |  | AD Parts kit
Resistor 10 Ω | 5 | Through-hole resistor, 10 Ω |  |  |  | AD Parts kit
Resistor 47 Ω | 5 | Through-hole resistor, 47 Ω |  |  |  | AD Parts kit
Resistor 68 Ω | 5 | Through-hole resistor, 68 Ω |  |  |  | AD Parts kit
Resistor 100 Ω | 5 | Through-hole resistor, 100 Ω |  |  |  | AD Parts kit
Resistor 470 Ω | 5 | Through-hole resistor, 470 Ω |  |  |  | AD Parts kit
Resistor 1 kΩ | 5 | Through-hole resistor, 1 kΩ |  |  |  | AD Parts kit
Resistor 1.5 kΩ | 5 | Through-hole resistor, 1.5 kΩ |  |  |  | AD Parts kit
Resistor 2.2 kΩ | 5 | Through-hole resistor, 2.2 kΩ |  |  |  | AD Parts kit
Resistor 4.7 kΩ | 5 | Through-hole resistor, 4.7 kΩ |  |  |  | AD Parts kit
Resistor 6.8 kΩ | 5 | Through-hole resistor, 6.8 kΩ |  |  |  | AD Parts kit
Resistor 10 kΩ | 5 | Through-hole resistor, 10 kΩ |  |  |  | AD Parts kit
Resistor 20 kΩ | 5 | Through-hole resistor, 20 kΩ |  |  |  | AD Parts kit
Resistor 47 kΩ | 5 | Through-hole resistor, 47 kΩ |  |  |  | AD Parts kit
Resistor 68 kΩ | 5 | Through-hole resistor, 68 kΩ |  |  |  | AD Parts kit
Resistor 100 kΩ | 5 | Through-hole resistor, 100 kΩ |  |  |  | AD Parts kit
Resistor 200 kΩ | 5 | Through-hole resistor, 200 kΩ |  |  |  | AD Parts kit
Resistor 470 kΩ | 5 | Through-hole resistor, 470 kΩ |  |  |  | AD Parts kit
Resistor 1 MΩ | 5 | Through-hole resistor, 1 MΩ |  |  |  | AD Parts kit
Resistor 5 MΩ | 5 | Through-hole resistor, 5 MΩ |  |  |  | AD Parts kit
Power resistor 6.2 Ω | 1 | Power resistor, 6.2 Ω, 10 W |  |  |  | AD Parts kit
Potentiometer 5 kΩ | 1 | Potentiometer, 5 kΩ |  |  |  | AD Parts kit
Potentiometer 10 kΩ | 2 | Potentiometer, 10 kΩ |  |  |  | AD Parts kit
Potentiometer 50 kΩ | 1 | Potentiometer, 50 kΩ |  |  |  | AD Parts kit
Capacitor 39 pF | 2 | Capacitor, 39 pF |  |  |  | AD Parts kit
Capacitor 100 pF | 2 | Capacitor, 100 pF |  |  |  | AD Parts kit
Capacitor 0.001 µF | 2 | Capacitor, 0.001 µF |  |  |  | AD Parts kit
Capacitor 0.0047 µF | 2 | Capacitor, 0.0047 µF |  |  |  | AD Parts kit
Capacitor 0.01 µF | 2 | Capacitor, 0.01 µF |  |  |  | AD Parts kit
Capacitor 0.047 µF | 2 | Capacitor, 0.047 µF |  |  |  | AD Parts kit
Capacitor 0.1 µF | 2 | Capacitor, 0.1 µF |  |  |  | AD Parts kit
Capacitor 1 µF | 2 | Capacitor, 1 µF |  |  |  | AD Parts kit
Capacitor 4.7 µF | 2 | Capacitor, 4.7 µF |  |  |  | AD Parts kit
Capacitor 10 µF | 2 | Capacitor, 10 µF |  |  |  | AD Parts kit
Capacitor 22 µF | 2 | Capacitor, 22 µF |  |  |  | AD Parts kit
Capacitor 47 µF | 2 | Capacitor, 47 µF |  |  |  | AD Parts kit
Capacitor 220 µF | 1 | Capacitor, 220 µF |  |  |  | AD Parts kit
2N3904 | 3 | Small-signal NPN transistor |  |  |  | AD Parts kit
2N3906 | 3 | Small-signal PNP transistor |  |  |  | AD Parts kit
IRF510 | 1 | Power MOSFET |  |  |  | AD Parts kit
TIP31CFS | 1 | NPN power transistor |  |  |  | AD Parts kit
TIP32CFS | 1 | PNP power transistor |  |  |  | AD Parts kit
ZVN2110A | 1 | N-channel DMOS FET |  |  |  | AD Parts kit
ZVN3310 | 2 | N-channel DMOS FET |  |  |  | AD Parts kit
ZVP2110A | 2 | P-channel MOSFET |  |  |  | AD Parts kit
SN74HC08 | 1 | Quad AND gate, 14-lead PDIP |  |  |  | AD Parts kit
SN74HC32 | 1 | Quad OR gate, 14-lead PDIP |  |  |  | AD Parts kit
SN74HC273 | 1 | Octal flip-flop, 14-lead PDIP |  |  |  | AD Parts kit
SN74HC04 | 1 | Hex inverter, 14-lead PDIP |  |  |  | AD Parts kit
Green LED | 2 | Green LED |  |  |  | AD Parts kit
Yellow LED | 2 | Yellow LED |  |  |  | AD Parts kit
Red LED | 2 | Red LED |  |  |  | AD Parts kit
QED123 | 1 | Infrared LED |  |  |  | AD Parts kit
QSD123 | 1 | Infrared phototransistor |  |  |  | AD Parts kit
1N3064 | 1 | Small-signal diode |  |  |  | AD Parts kit
1N4001 | 1 | General-purpose plastic rectifier diode |  |  |  | AD Parts kit
1N4735 | 1 | 1 W Zener diode |  |  |  | AD Parts kit
1N914 | 4 | Fast-switching diode |  |  |  | AD Parts kit
RFB0807-1R0L | 2 | Inductor, 1.0 µH |  |  |  | AD Parts kit
RFB0807-100L | 2 | Inductor, 10 µH |  |  |  | AD Parts kit
RFB0807-101L | 2 | Inductor, 100 µH |  |  |  | AD Parts kit
RFB0807-102L | 2 | Inductor, 1 mH |  |  |  | AD Parts kit
RFB0807-103L | 2 | Inductor, 10 mH |  |  |  | AD Parts kit
HPH1-1400L | 1 | Hexa-Path magnetics component (breakout board) |  |  |  | AD Parts kit
HPH1-0190L | 1 | Hexa-Path magnetics component (breakout board) |  |  |  | AD Parts kit
Speaker | 1 | Speaker |  |  |  | AD Parts kit
Solderless breadboard | 1 | Solderless breadboard |  |  |  | AD Parts kit
Flathead screwdriver | 1 | Flathead screwdriver |  |  |  | AD Parts kit
USB connector | 1 | USB connector (breakout board) |  |  |  | AD Parts kit
Audio connector | 1 | Audio connector (breakout board) |  |  |  | AD Parts kit
Jumper wires | 45 | Jumper wires with pin ends |  |  |  | AD Parts kit

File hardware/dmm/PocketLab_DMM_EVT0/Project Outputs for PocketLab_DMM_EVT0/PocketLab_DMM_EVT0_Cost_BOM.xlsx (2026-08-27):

Name | Description | Designator | Footprint | Quantity | Manufacturer | Manufacturer Part Number | Supplier | Supplier Part Number | Supplier 1 | Supplier Stock 1 | Supplier Subtotal per Board 1 | Supplier Order Qty 1 | Supplier Subtotal 1
1K | RES 1/8W 0805 | R36 | R0805 | 1 | Stackpole Electronics | RNCF0805TKY10K0 | DigiKey | RNCF0805TKY10K0CT-ND
1M RREF | RES 1/8W 0805 | R41 | R0805 | 1 | Stackpole Electronics | RNCF0805TKY10K0 | DigiKey | RNCF0805TKY10K0CT-ND
1N914BWT | DIODE STANDARD 75V 200MA SOD523F | D2 | 1N914BWT | 1 | onsemi | 1N914BWT | DigiKey | 1N914BWTCT-ND
2.2R | RES 1/8W 0805 | R23 | R0805 | 1 | Stackpole Electronics | RNCF0805TKY10K0 | DigiKey | RNCF0805TKY10K0CT-ND
10k | THERMISTOR NTC 10KOHM 3380K 0603 / NTC Thermistor 10k 0603 (1608 Metric) | RT1 | 0608_THERM | 1 | Murata | NCU18XH103F6SRB | DigiKey | 490-18139-6-ND
10K RREF | RES 1/8W 0805 | R38 | R0805 | 1 | Stackpole Electronics | RNCF0805TKY10K0 | DigiKey | RNCF0805TKY10K0CT-ND
10-PIN BUS | 10-pin stackable module interface for power, I2C, SPI, and shared interrupt | J6 | MODULE_BUS_10_TAB_SLOT | 1
11K | RES 1/8W 0805 | R1 | R0805 | 1 | Stackpole Electronics | RNCF0805TKY10K0 | DigiKey | RNCF0805TKY10K0CT-ND
16.2K | RES 1/8W 0805 | R15 | R0805 | 1 | Stackpole Electronics | RNCF0805TKY10K0 | DigiKey | RNCF0805TKY10K0CT-ND
21K | RES 1/8W 0805 | R3 | R0805 | 1 | Stackpole Electronics | RNCF0805TKY10K0 | DigiKey | RNCF0805TKY10K0CT-ND
32.768KHz DNP | Parallel - Fundamental Quartz Crystal, 0.032768MHz Nom | Y1 | RT3215 | 1 | Raltron Electronics | RT3215-32.768-12.5-TR-10PPM | DigiKey | 2151-RT3215-32.768-12.5-TR-10PPMCT-ND
100K RREF | RES 1/8W 0805 | R39 | R0805 | 1 | Stackpole Electronics | RNCF0805TKY10K0 | DigiKey | RNCF0805TKY10K0CT-ND
360K | RES 360K OHM 0.1% 1/4W 1206 | R49 | R1206 | 1 | Susumu | RGV3216P-3603-B-T1 | DigiKey | 408-RGV3216P-3603-B-T1CT-ND
360K RREF | RES 1/8W 0805 | R40 | R0805 | 1 | Stackpole Electronics | RNCF0805TKY10K0 | DigiKey | RNCF0805TKY10K0CT-ND
ADS1220IPWR | IC ADC 24BIT 16-TSSOP | U6 | ADS1220IPWR | 1 | Texas Instruments | ADS1220IPWR | DigiKey | 296-39851-1-ND
B3U-1000P | Switch Tactile N.O. SPST Round Button Solder Tab 12VDC 200000Cycles 1.5N SMD Emboss T/R | SW1 | B3U-1000P | 1 | Omron | B3U-1000P | Arrow Electronics | B3U-1000P
BQ25180YBGR | 5.5V /Polymer 1 1A DSBGA-8(1.1x1.6) Battery Management ICs ROHS | U4 | BQ25180 | 1 | Texas Instruments | BQ25180YBGR | DigiKey | 296-BQ25180YBGRCT-ND
FCR7350B | 4 mm shrouded banana socket, PCB mount | J5 | FCR7350R | 1 | Cliff | FCR7350R | DigiKey | 4654-FCR7350R-ND
FCR7350R | 4 mm shrouded banana socket, PCB mount | J4 | FCR7350R | 1 | Cliff | FCR7350R | DigiKey | 4654-FCR7350R-ND
HDR 10POS | CONN HEADER SMD 10POS 1.27MM / Connector Header Surface Mount 10 position 0.050" (1.27mm) | J3 | FTSH-105-01-L-DV-K | 1 | Samtec | FTSH-105-01-L-DV-K | DigiKey | SAM8799-ND
LM27762 | IC REG CHARGE PUMP ADJ DL 12WSON | U1 | LM27762 | 1 | Texas Instruments | LM27762DSSR | DigiKey | 296-47331-1-ND
MDBT50Q-1MV2 | 802.15.4, Bluetooth Bluetooth v5.4, ZigbeeÂ® Transceiver Module 2.36GHz ~ 2.5GHz Integrated, Chip Surface Mount | U5 | NRF52840_MDBT50Q-1MV2 | 1
MMBT3904LT1G | TRANS NPN 40V 0.2A SOT23-3 | Q1 | MMBT3904 | 1 | onsemi | MMBT3904LT1G | DigiKey | MMBT3904LT1GOSDKR-ND
OPA197IDGKR | Precision rail-to-rail operational amplifier | U8 | OPA197IDGKR | 1 | Texas Instruments | OPA197IDGKR | DigiKey | 296-44205-1-ND
S2B-PH-SM4-TB | Board Connector, 2 Contact(s), 1 Row(s), Male, Right Angle, Surface Mount Terminal | J2 | S2B-PH-SM4-TB | 1 | JST | S2B-PH-SM4-TB | DigiKey | 455-S2B-PH-SM4-TBDKR-ND
TMUX1109PWR | 4 4.9Ω Double Pole Four Throw (DP4T) TSSOP-16-175mil Analog Switches, Multiplexers ROHS | U7 | TMUX1109PWR | 1 | Texas Instruments | TMUX1109PWR | DigiKey | 296-53438-1-ND
TQ2-3V (ATQ201) | Electromechanical Relay Double Pole Double Throw 1A 3 Volt 64.3Ohm Through Hole | K1 | TQ2-3V | 1 | Panasonic | TQ2-3V | DigiKey | 255-1225-5-ND | Future Electronics
TVS DIODE 5.5VWM | TVS DIODE 5.5VWM SOT5 | D1 | TPD2E001DRLR | 1 | Texas Instruments | TPD2E001DRLR | DigiKey | 296-21883-1-ND
USB-C | USB Connector, 24 Contact(s), Female, Right Angle, Solder Terminal, Locking, Receptacle | J1 | USB4105-GF-A | 1 | Global Connector Technology | USB4105-GF-A | DigiKey | 2073-USB4105-GF-ADKR-ND
0R | RES 1/8W 0805 | R8, R14 | R0805 | 2 | Stackpole Electronics | RNCF0805TKY10K0 | DigiKey | RNCF0805TKY10K0CT-ND
1uF |  | C11, C13 | C0805 | 2
2.2uF |  | C3, C5 | C0805 | 2
2.2uH | FIXED IND 2.2UH 2A 190 MOHM SMD | L1, L2 | L_2.2uH | 2 | Wurth Elektronik | 74479275222 | DigiKey | 732-9708-1-ND
4.7uF |  | C1, C6 | C0805 | 2
8.25K | RES 1/8W 0805 | R4, R18 | R0805 | 2 | Stackpole Electronics | RNCF0805TKY10K0 | DigiKey | RNCF0805TKY10K0CT-ND
10nF |  | C22, C23 | C0805 | 2
22uF |  | C8, C10 | C0805 | 2
27R | RES 1/8W 0805 | R24, R25 | R0805 | 2 | Stackpole Electronics | RNCF0805TKY10K0 | DigiKey | RNCF0805TKY10K0CT-ND
CLOAD DNP |  | C17, C18 | C0805 | 2
TPS63900DSKR | Buck-Boost Yes 2MHz Programmable 1 5V 1.8V 5.5V 1.8V WFDFN-10(EP) SMD mount，glue mount | U2, U3 | TPS63900 | 2 | Texas Instruments | TPS63900DSKR | DigiKey | 296-TPS63900DSKRCT-ND
5.1K | RES 1/8W 0805 | R7, R11, R12 | R0805 | 3 | Stackpole Electronics | RNCF0805TKY10K0 | DigiKey | RNCF0805TKY10K0CT-ND
36.5K | RES 1/8W 0805 | R13, R17, R19 | R0805 | 3 | Stackpole Electronics | RNCF0805TKY10K0 | DigiKey | RNCF0805TKY10K0CT-ND
TEST POINT | SMD TEST POINT | TP1, TP2, TP3 |  | 3
1.0uF |  | C4, C19, C26, C27 | C0805 | 4
3M | RES 30M OHM 0.1% 1/4W 1206 | R45, R46, R47, R48 | R1206 | 4 | Susumu | RGV3216P-3004-B-T1 | DigiKey | 408-RGV3216P-3004-B-T1CT-ND
10uF |  | C7, C9, C12, C15, C16 | C0805 | 5
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

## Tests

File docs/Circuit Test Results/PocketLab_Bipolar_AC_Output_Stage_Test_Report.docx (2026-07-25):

POCKETLAB

# Bipolar AC Output Stage

Breadboard Validation and Characterization Report

Project | PocketLab Programmable Function Generator
Test date | July 22, 2026
Prepared for | Mark Anderson
Status | PASS — provisional high-impedance AC output validated

Executive result A 47 µF coupling capacitor, 100 Ω protection resistor, and permanent 100 kΩ ground-reference resistor converted the existing 2.34 V-biased output into a clean bipolar waveform centered within a few millivolts of 0 V. Amplitude tracking was within 0.5% from 10 Hz through 100 kHz under high-impedance loading. Loads of 10 kΩ or greater produced about 1% or less additional attenuation.

# 1. Objective

Validate a passive output branch that removes the function generator’s DC bias while preserving the AC waveform. The stage was evaluated for waveform centering, amplitude transfer, frequency response, load response, and power-switching behavior.

# 2. Circuit under test

Connection | Component / node | Purpose
DC OUT → capacitor + | 47 µF, 10 V electrolytic | Blocks steady DC after charging; passes the changing waveform
Capacitor − → AC OUT | 100 Ω series resistor | Limits fault and capacitive-load current; creates predictable load attenuation
AC OUT → ground | 100 kΩ permanent resistor | References output average to 0 V and discharges the capacitor
Measurement | Analog Discovery 3, 1 MΩ input | High-impedance observation of DC OUT and AC OUT

Capacitor polarity was positive toward the OP484 output and negative toward AC OUT. The existing DC output remained available and unchanged.

# 3. Operating principle

At steady state, the capacitor charges to approximately the 2.34 V DC bias at DC OUT. The constant component is blocked, while voltage changes are coupled through. The 100 kΩ resistor establishes ground as the new average level.

vDC(t) ≈ 2.343 V + 0.496 sin(2πft) V

vAC(t) ≈ 0.496 sin(2πft) V

The permanent 100 kΩ resistor in parallel with the 1 MΩ instrument input gives about 90.9 kΩ. With 47 µF, the calculated high-pass corner is approximately 0.037 Hz—far below the tested 10 Hz minimum.

Important limitation This stage produces negative waveform excursions but not a negative DC rail. It supports an AC waveform centered at 0 V; it cannot provide steady negative offset or an adjustable center below ground.

# 4. Safety and initial powered checks

- Continuity confirmed from OP484 pin 1 / existing output to the capacitor positive lead.
- Capacitor negative lead to AC OUT measured approximately 99.1 Ω.
- AC OUT to circuit ground measured approximately 99.8 kΩ.
- AC OUT to +5 V measured about 100 kΩ and rising, consistent with capacitor charging rather than a short.
- +5 V to ground showed no short; measurement grounds used common circuit ground.

Initial powered checks were normal: +5 V rail = 4.71 V; supply current = 0.06–0.07 A; DC OUT = 2.345 V when active; AC OUT decayed toward 0 V. With output logically off, DC OUT measured 10.6 mV and AC OUT measured 0.0 mV.

# 5. Initial 1 kHz validation

Metric | AC OUT result | Interpretation
Maximum | +0.50396 V | Near expected +0.5 V peak
Minimum | −0.50196 V | Near expected −0.5 V peak
Peak-to-peak | 1.0059 V | 0.59% above 1.00 V command
Average | +1.818 mV | Essentially centered at ground
Frequency | 999.05 Hz | Matches 1 kHz command

A two-channel capture showed DC OUT at approximately 0.992 Vpp centered at 2.343 V and AC OUT at approximately 0.994 Vpp centered near 0 V. The stage removed the bias while preserving waveform amplitude and phase.

# 6. No-added-load frequency sweep

Set f | AC Vpp | DC Vpp | AC/DC | AC average | Phase
10 Hz | 0.9473 | 0.9505 | 99.67% | +1.72 mV | 0.254°
100 Hz | 0.9560 | 0.9606 | 99.52% | +1.92 mV | 0.245°
1 kHz | 0.9936 | 0.9952 | 99.84% | +1.97 mV | 0.205°
10 kHz | 0.9966 | 0.9982 | 99.84% | +2.00 mV | 0.311°
50 kHz | 0.9874 | 0.9888 | 99.86% | −0.64 mV | 0.473°
100 kHz | 0.9487 | 0.9504 | 99.83% | +1.72 mV | 0.552°
200 kHz | 0.8427 | 0.8310 | 101.41%* | +2.60 mV | 0.794°

*At 200 kHz the waveform was visibly distorted; automatic Vpp is sensitive to peaks and noise, so the apparent ratio above 100% is not passive gain.

## Frequency-sweep findings

- AC OUT remained within approximately −0.6 mV to +2.6 mV of ground.
- From 10 Hz through 100 kHz, AC OUT differed from DC OUT by less than 0.5%.
- Phase difference stayed below 0.8° at every tested point.
- No visible low-frequency droop occurred at 10 Hz.
- Amplitude reduction and distortion near 200 kHz appeared on both outputs and therefore originate primarily in the upstream DDS/amplifier path.

# 7. 1 kHz load sweep

Added load | Effective load* | AC Vpp | DC Vpp | AC/DC | AC average
None | 90.9 kΩ | 0.9940 | 0.9955 | 99.85% | +11.28 mV
100 kΩ | 47.6 kΩ | 0.9893 | 0.9917 | 99.76% | +4.11 mV
10 kΩ | 9.01 kΩ | 0.9831 | 0.9925 | 99.06% | +2.16 mV
1 kΩ | 988 Ω | 0.8932 | 0.9858 | 90.61% | +0.84 mV

*Includes the permanent 100 kΩ resistor and the Analog Discovery’s 1 MΩ input.

Loss closely matches the divider formed by the intentional 100 Ω resistor and effective load. For the 1 kΩ test, predicted transfer was 90.8% and measured transfer was 90.6%. Estimated peak output current was approximately 0.45 mA.

## Load-sweep findings

- Loads of 10 kΩ or greater preserved amplitude to about 1% or better.
- The 1 kΩ load caused approximately 9.4% attenuation, consistent with the 100 Ω protection resistor.
- No clipping, oscillation, or major distortion was visible under any tested load.
- DC OUT remained stable; the loads did not significantly disturb the OP484 stage.
- The output is not intended for 50 Ω loads.

# 8. Power-switching transient

A separate bench-supply switching capture showed a positive transient at both outputs. The largest recorded excursions were approximately +2.80 V at AC OUT and +2.88 V at DC OUT, with no significant negative excursion. These remained inside the approximately 0–4.71 V internal supply range.

The coupling capacitor converts a rapid internal DC-level change into a pulse at AC OUT. Narrow spikes and the intermediate plateau may also include supply switching or switch bounce. The capture does not prove that extremely short spikes are absent, but it showed no immediately dangerous excursion for the generator or Analog Discovery.

External-circuit caution The transient is acceptable for breadboard characterization but could disturb a sensitive device connected to AC OUT. Keep the external load disconnected during power transitions, or set OUTPUT OFF and isolate the device before cycling bench power.

# 9. Conclusions and provisional rating

Parameter | Provisional rating / conclusion
Waveforms | Sine validated; triangle characterization pending
Recommended frequency | 10 Hz–100 kHz
Extended operation | 200 kHz with reduced amplitude and visible upstream distortion
Amplitude | 1.00 Vpp characterized; higher-amplitude sweep pending
Output center | Approximately 0 V; within a few millivolts in the sweep
Recommended load | 10 kΩ or greater
1 kΩ operation | Usable with approximately 9% attenuation at 1 kHz
50 Ω drive | Not supported
DC capability | AC only; no sustained negative DC or adjustable negative center

Overall result: PASS. The passive bipolar AC-output stage removes the midrail bias, centers the waveform near ground, and preserves signal integrity over the intended high-impedance range.

# 10. Recommended next steps

1. Capture startup and shutdown separately at 20–100 ms/div with OUTPUT OFF before cycling power.
2. Run triangle checks at 10 Hz, 1 kHz, 50 kHz, and 200 kHz.
3. Test 2.0, 4.0, and 4.15 Vpp into high impedance; verify symmetry and clipping margin.
4. Add an AC/DC selector, first manual, then evaluate a relay or suitable analog switch with startup isolation.
5. Implement safe switching: mute, establish midrail, switch coupling, settle, restore amplitude, and unmute.
6. Add COUPLING=AC/DC to firmware/BLE and update the app so AC mode displays 0 V center and disables adjustable offset.

# 11. Safe breadboard operation

- Before shutdown: set OUTPUT OFF, verify AC OUT is near 0 V, isolate the external device, then switch off bench power.
- At startup: leave output disconnected, power the generator, wait for safe initialization, then connect the load and enable output.
- Do not connect laptop USB and external 5 V simultaneously until the ESP32 board’s dual-power behavior is verified.
- Use common ground and avoid wiring changes while powered or attached to the laptop.

Bipolar AC Output Stage — Test Report • July 22, 2026 •

POCKETLAB / FUNCTION GENERATOR

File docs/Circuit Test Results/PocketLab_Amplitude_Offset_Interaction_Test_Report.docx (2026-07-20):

TEST REPORT

PocketLab Amplitude/Offset Interaction Test

Firmware envelope validation versus measured analog output limits

Project: PocketLab BLE-Controlled Function Generator

Test date: July 16, 2026

Test frequency: 1 kHz

Primary waveform: Sine

Overall result: PASS WITH FOLLOW-UP ACTIONS

# Executive Summary

The amplitude/offset interaction test confirmed that the firmware's combined unipolar-output envelope protection behaves as configured. Legal combinations were accepted, out-of-envelope combinations were rejected, and rejected commands preserved the preceding valid waveform. The mobile application also clamped an attempted 4.16 Vpp command to its 4.15 Vpp maximum.

The analog output remained visually sinusoidal without obvious hard clipping across the tested legal combinations. Amplitude accuracy was strong at 2.00 Vpp and 4.15 Vpp. The principal finding was a systematic negative offset error: measured OP484 output mean was typically below the requested offset, with the error increasing to approximately 0.14-0.19 V in demanding medium- and maximum-amplitude cases.

# Test Objective

Verify that the firmware's legal amplitude/offset envelope matches the practical analog limits of the AD5626/X9C103S/OP484 signal path, including combinations near the lower and upper rails and commands immediately inside and outside the configured envelope.

# Configuration and Acceptance Criteria

- Configured active-output envelope: 0.20 V minimum to 4.40 V maximum.
- Maximum commanded amplitude: 4.15 Vpp.
- A legal sine-wave state must satisfy offset - Vpp/2 >= 0.20 V and offset + Vpp/2 <= 4.40 V.
- Accepted commands should produce the requested waveform without obvious clipping or rail excursion.
- Rejected commands should not alter or momentarily disturb the preceding valid output.

# Measurement Channels

Channel 1: AD5626 offset-control output

Channel 2: OP484 final analog output

# Recorded Test Results

For rejected commands, the displayed measurements belong to the preceding valid state and demonstrate output retention; they are not measurements of the rejected request.

Test | Request Vpp / Offset | Control result | CH1 Avg / Vpp (V) | CH2 Mean (V) | CH2 Vpp (V) | CH2 Min-Max (V) | Assessment
1 | 0.50 / 0.46 | Accepted | 0.456 / 0.082 | 0.442 | 0.447 | 0.220-0.667 | Clean; Vpp 10.6% low
2 | 0.50 / 4.14 | Blocked | 0.456 / 0.081 | 0.442 | 0.449 retained | 0.220-0.669 | App sent 4.09 V; firmware OFFSET_OUT_OF_RANGE
3 | 2.00 / 1.25 | Accepted | 1.240 / 0.300 | 1.199 | 2.023 | 0.192-2.215 | Clean; lower peak 8 mV below 0.20 V model
4 | 2.00 / 2.30 | Accepted | 2.283 / 0.301 | 2.206 | 2.016 | 1.195-3.211 | Clean; mean 94 mV low
5 | 2.00 / 3.35 | Accepted | 3.327 / 0.296 | 3.215 | 2.019 | 2.204-4.222 | Clean; mean 136 mV low
6 | 4.15 / 2.30 | Accepted | 2.271 / 0.589 | 2.125 | 4.144 | 0.062-4.207 | Full amplitude; little lower-rail margin
7 | 0.50 / 0.44 | Rejected | 2.270 / 0.589 | 2.114 retained | 4.145 retained | 0.051-4.195 | Correct rejection; prior output retained
8 | 0.50 / 4.16 | Blocked | 2.270 / 0.589 | 2.114 retained | 4.145 retained | 0.050-4.195 | App sent 4.09 V; firmware OFFSET_OUT_OF_RANGE
9 | 2.00 / 1.21 | Accepted | 1.200 / 0.296 | 1.163 | 2.006 | 0.169-2.175 | Clean; measured minimum below model boundary
10 | 2.00 / 1.19 | Rejected | 1.200 / 0.297 | 1.162 retained | 2.005 retained | 0.169-2.174 | Correct rejection; prior output retained
11 | 2.00 / 3.39 | Accepted | 3.367 / 0.293 | 3.251 | 2.018 | 2.240-4.258 | Clean; mean 140 mV low
12 | 2.00 / 3.41 | Rejected | 3.368 / 0.294 | 3.259 retained | 2.013 retained | 2.247-4.260 | Correct rejection; prior output retained
13 | 4.15 / 2.28 | Accepted | 2.252 / 0.589 | 2.107 | 4.145 | 0.044-4.189 | Full amplitude; lower peak near ground
14 | 4.15 / 2.27 | Rejected | 2.250 / 0.589 | 2.096 retained | 4.143 retained | 0.035-4.178 | Correct rejection; prior output retained
15 | 4.15 / 2.32 | Accepted | 2.290 / 0.589 | 2.136 | 4.147 | 0.072-4.219 | Full amplitude; waveform visually smooth
16 | 4.15 / 2.33 | Rejected | 2.289 / 0.589 | 2.132 retained | 4.143 retained | 0.068-4.211 | Correct rejection; prior output retained
17 | 4.14 / 2.30 | App -> 4.15 | 2.270 / 0.589 | 2.113 | 4.147 | 0.049-4.196 | App normalized request to 4.15 Vpp
18 | 4.16 / 2.30 | App -> 4.15 | 2.270 / 0.589 | 2.113 | 4.146 | 0.050-4.196 | App clamped above-maximum request; firmware not exercised
R1 | 4.15 / 2.28 | Accepted repeat | 2.250 / 0.590 | 2.098 | 4.147 | 0.034-4.181 | Repeat confirms stability
R2 | 4.15 / 2.32 | Accepted repeat | 2.290 / 0.589 | 2.134 | 4.149 | 0.069-4.218 | Repeat confirms stability

# Analysis

## Firmware Envelope Behavior

All combined-envelope boundary cases that reached the firmware produced the expected outcome. Commands just inside the lower and upper boundaries were accepted, while commands just outside were rejected. The retained-waveform measurements following Tests 7, 10, 12, 14, and 16 show that rejection did not replace the valid operating state.

## Amplitude Accuracy

At a 2.00 Vpp request, measured output ranged from 2.0062 to 2.0228 Vpp across the accepted offset settings, corresponding to approximately +0.3% to +1.1% error. At a 4.15 Vpp request, accepted and repeat measurements ranged from 4.1444 to 4.1490 Vpp, within approximately 6 mV of the request. The 0.50 Vpp low-offset case measured 0.4472 Vpp and therefore showed substantially greater relative error at the low-amplitude end.

## Offset Accuracy and Analog Margin

The measured OP484 mean was consistently lower than the requested offset. Representative errors were -47 mV at 2.00 Vpp/1.21 V offset, -94 mV at 2.00 Vpp/2.30 V offset, -140 mV at 2.00 Vpp/3.39 V offset, and approximately -164 to -184 mV for maximum-amplitude cases.

Consequently, the real analog peaks do not track the firmware's calculated 0.20-4.40 V envelope symmetrically. Maximum-amplitude legal states produced approximately 0.03-4.22 V. Although no obvious hard clipping was visible, the lower peak approached ground closely enough that the current envelope provides little practical lower-rail margin.

## Mobile-App Limit Behavior

An attempted 4.16 Vpp command was forced to 4.15 Vpp on the mobile side before transmission. This is a successful application-layer safety behavior, but it means the firmware's independent rejection of amplitudes above MAX_AMPLITUDE_VPP was not exercised through the normal UI. The intended high-offset low-amplitude requests were also altered to 4.09 V and rejected as OFFSET_OUT_OF_RANGE, revealing a limit or numeric-control mismatch between the app and firmware.

# Conclusions

- PASS: Combined amplitude/offset envelope validation operated correctly for all commands that reached the firmware.
- PASS: Rejected commands preserved the preceding valid output state.
- PASS: No obvious hard clipping or unsafe rail excursion was observed in the accepted cases.
- PASS: Medium- and maximum-amplitude accuracy was strong and repeatable.
- FOLLOW-UP: Offset calibration does not presently make the requested offset equal the measured OP484 mean.
- FOLLOW-UP: The high-offset UI behavior and firmware absolute offset range should be aligned.

PocketLab Function Generator | Verification Report

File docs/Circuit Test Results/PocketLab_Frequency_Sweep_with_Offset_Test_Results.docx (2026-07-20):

# FREQUENCY SWEEP WITH OFFSET

Sine and Triangle Wave Performance from 10 Hz to 200 kHz

Project | PocketLab BLE-Controlled Function Generator
Test configuration | 1.00 Vpp, 2.35 V commanded offset, output enabled
Signal path | AD9833 → 47 µF coupling → X9C103S → OP484
Test date / operator | July 16, 2026 / Mark Anderson

# Executive Summary

RESULT: PASS WITH CHARACTERIZED LIMITATIONS. The offset-enabled analog path remained bounded and stable throughout the sweep. No clipping, rail excursion, or frequency-dependent baseline movement was observed at the tested 1 Vpp setting. The measured center was approximately 2.30 V rather than the commanded 2.35 V, indicating a repeatable calibration offset of about −50 mV.

Both waveforms showed moderate low-frequency amplitude loss at 10 Hz and increasing ripple/distortion above 10–50 kHz. Sine amplitude remained nearly flat through 200 kHz, although waveform fidelity was poor at 100–200 kHz. Triangle amplitude began to decline above 50 kHz and its shape was poor by 100–200 kHz.

# 1. Objective

Evaluate amplitude, DC offset, waveform shape, and phase behavior with offset control enabled at representative frequencies from 10 Hz to 200 kHz. Special attention was given to the low-frequency response of the 47 µF AC-coupling capacitor and to high-frequency waveform degradation.

# 2. Test Configuration

Parameter | Setting
Waveforms | Sine and triangle
Commanded amplitude | 1.00 Vpp
Commanded offset | 2.35 V
Frequencies | 10 Hz, 100 Hz, 1 kHz, 10 kHz, 50 kHz, 100 kHz, 200 kHz
Oscilloscope coupling | DC
Channel 1 | X9C wiper / OP484 input
Channel 2 | OP484 output
Acquisition | 16 Ki samples; timebase and sample rate adjusted by frequency

Amplitude was taken from the Channel 2 peak-to-peak measurement. Offset was recorded using the Channel 2 average. WaveForms automatic phase measurements are retained as approximate values; their reliability decreases when the waveform is noisy or strongly non-sinusoidal.

# 3. Sine-Wave Results

Frequency | Vpp (V) | Average (V) | Min–Max (V) | Phase | Shape
10 Hz | 0.932 | 2.299 | 1.834–2.765 | 0.34° | Clean; low-frequency attenuation
100 Hz | 0.956 | 2.299 | 1.821–2.778 | 2.72° | Clean; amplitude recovering
1 kHz | 1.061 | 2.299 | 1.765–2.826 | 12.71° | Clean fundamental; visible noise
10 kHz | 1.073 | 2.299 | 1.762–2.835 | 14.02° | Sine retained; periodic ripple
50 kHz | 1.077 | 2.300 | 1.759–2.836 | 14.30° | Strong ripple/distortion
100 kHz | 1.063 | 2.300 | 1.765–2.828 | 15.03° | Considerable distortion
200 kHz | 1.068 | 2.298 | 1.755–2.823 | 18.93° | Poor sine fidelity; no clipping

Sine amplitude increased from 0.932 Vpp at 10 Hz to approximately 1.06–1.08 Vpp from 1 kHz upward. The output average remained within 2.298–2.300 V at all test frequencies.

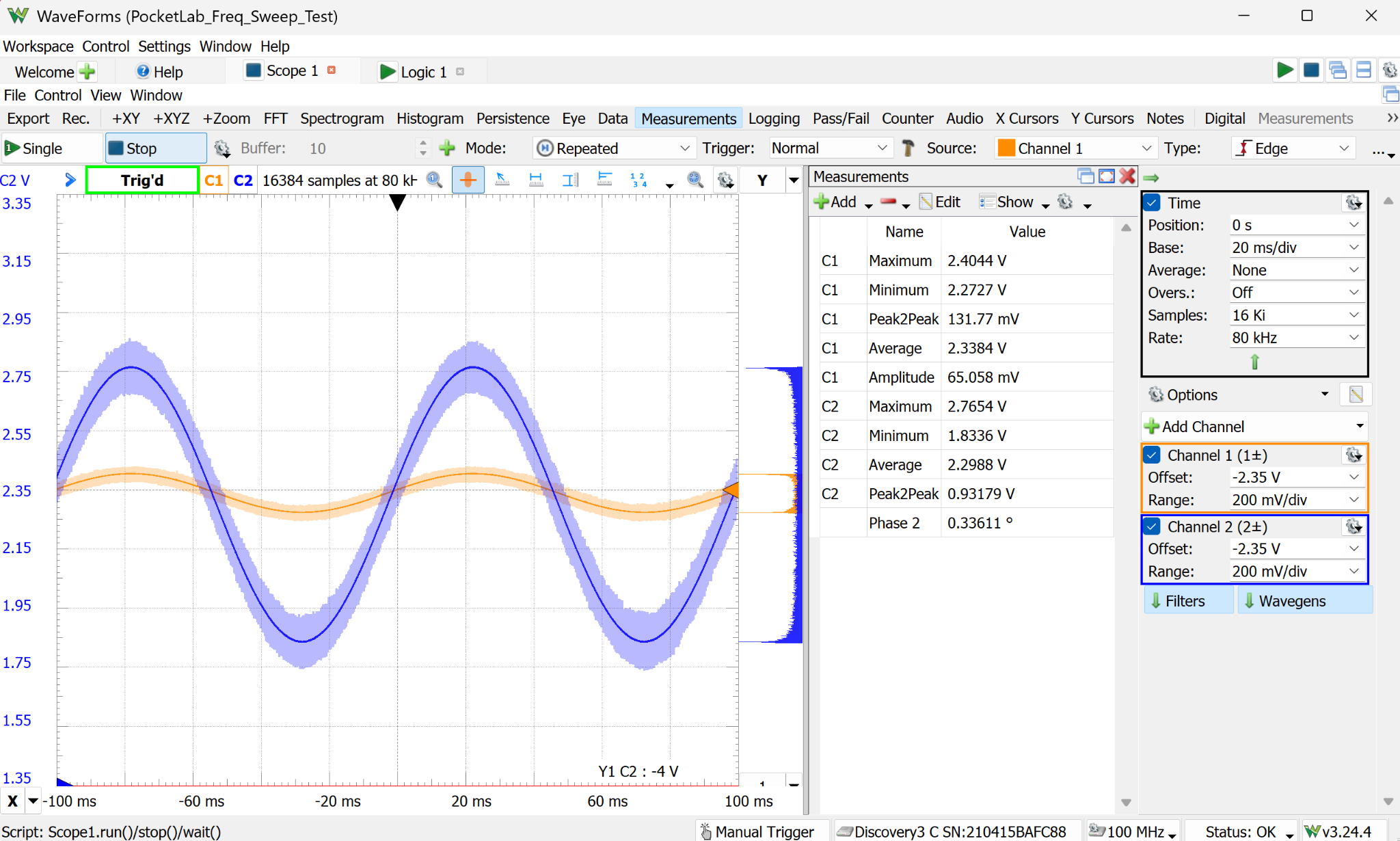
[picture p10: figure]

Figure 1. 10 Hz sine: clean, stable baseline with 0.932 Vpp output.

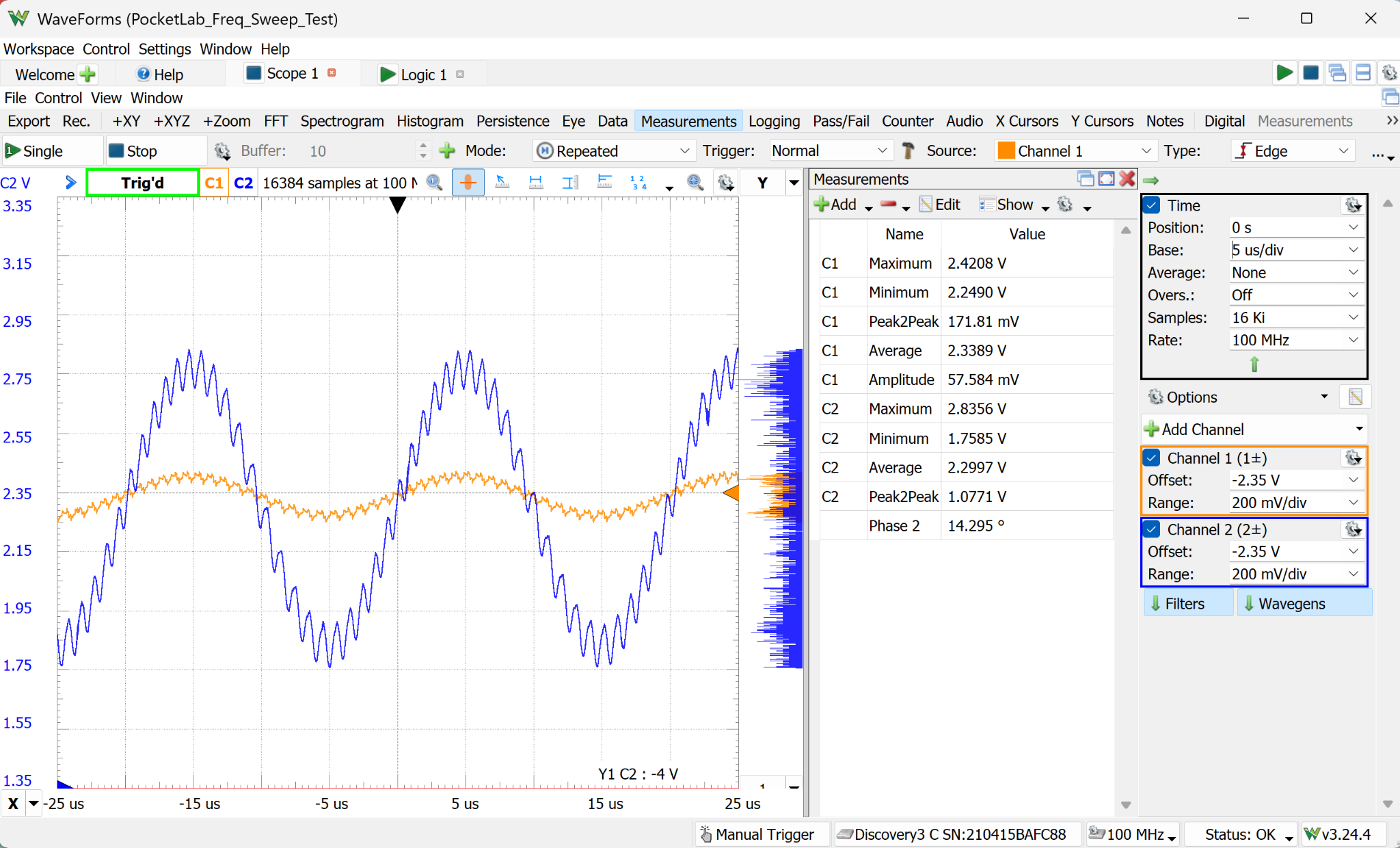
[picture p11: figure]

Figure 2. 50 kHz sine: amplitude retained, but periodic ripple is prominent.

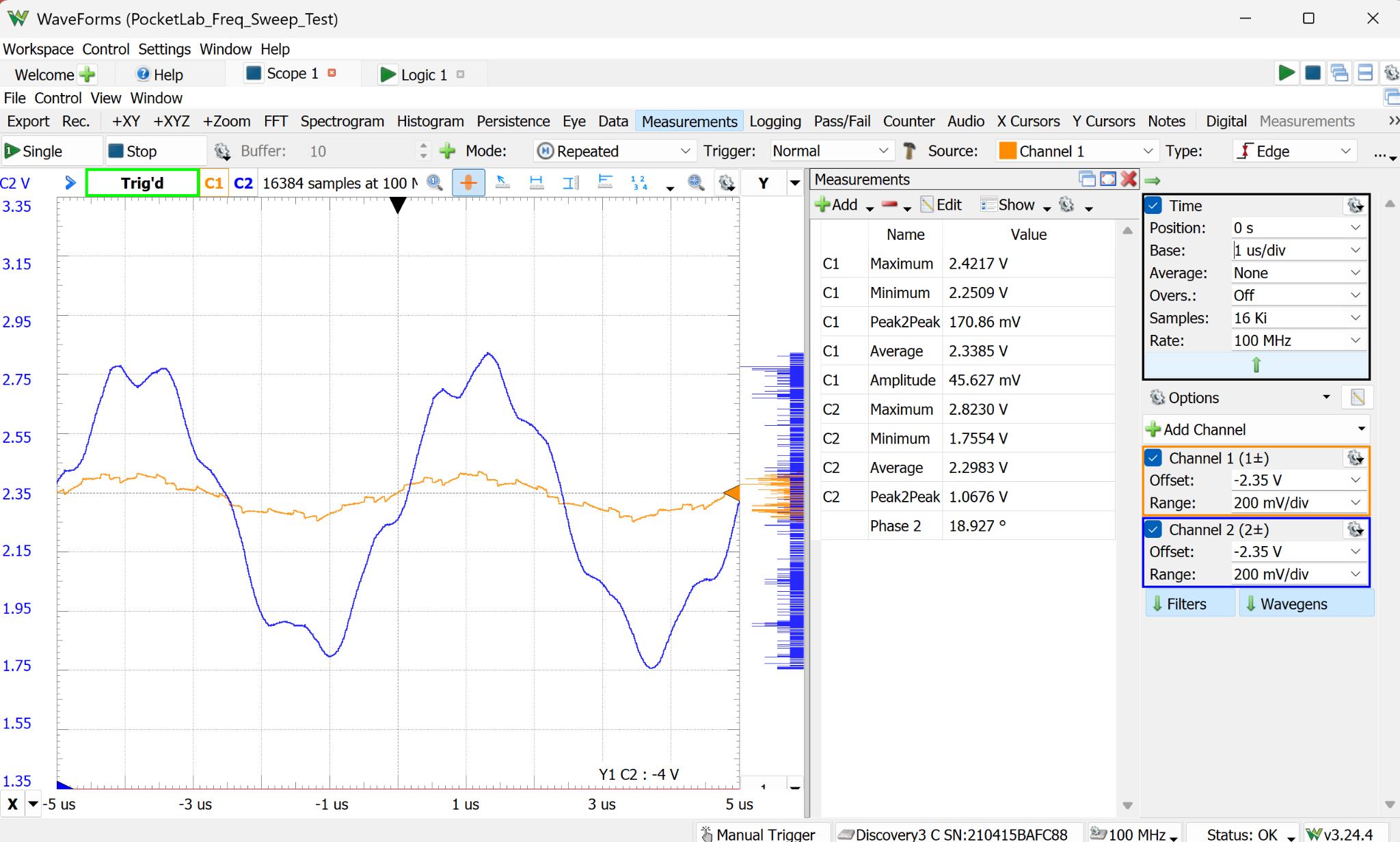
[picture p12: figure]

Figure 3. 200 kHz sine: substantial shape distortion without clipping.

# 4. Triangle-Wave Results

Frequency | Vpp (V) | Average (V) | Min–Max (V) | Phase | Shape
10 Hz | 0.930 | 2.299 | 1.835–2.765 | 0.40° | Clean, straight slopes; attenuated
100 Hz | 0.953 | 2.299 | 1.822–2.776 | 3.25° | Clean triangle
1 kHz | 1.060 | 2.299 | 1.767–2.826 | 15.44° | Clean shape; noisy trace
10 kHz | 1.060 | 2.299 | 1.765–2.825 | 16.97° | Triangle retained; strong ripple
50 kHz | 1.059 | 2.291 | 1.768–2.827 | 17.46° | Triangular envelope; corrugated
100 kHz | 1.021 | 2.300 | 1.772–2.793 | 18.32° | Uneven slopes; considerable distortion
200 kHz | 1.009 | 2.298 | 1.789–2.799 | 22.17° | Rounded/irregular; poor fidelity

Triangle amplitude matched the sine response at low and mid frequencies, then declined to 1.021 Vpp at 100 kHz and 1.009 Vpp at 200 kHz. The triangular envelope remained recognizable at 50 kHz, but ripple and peak irregularity dominated at 100–200 kHz.

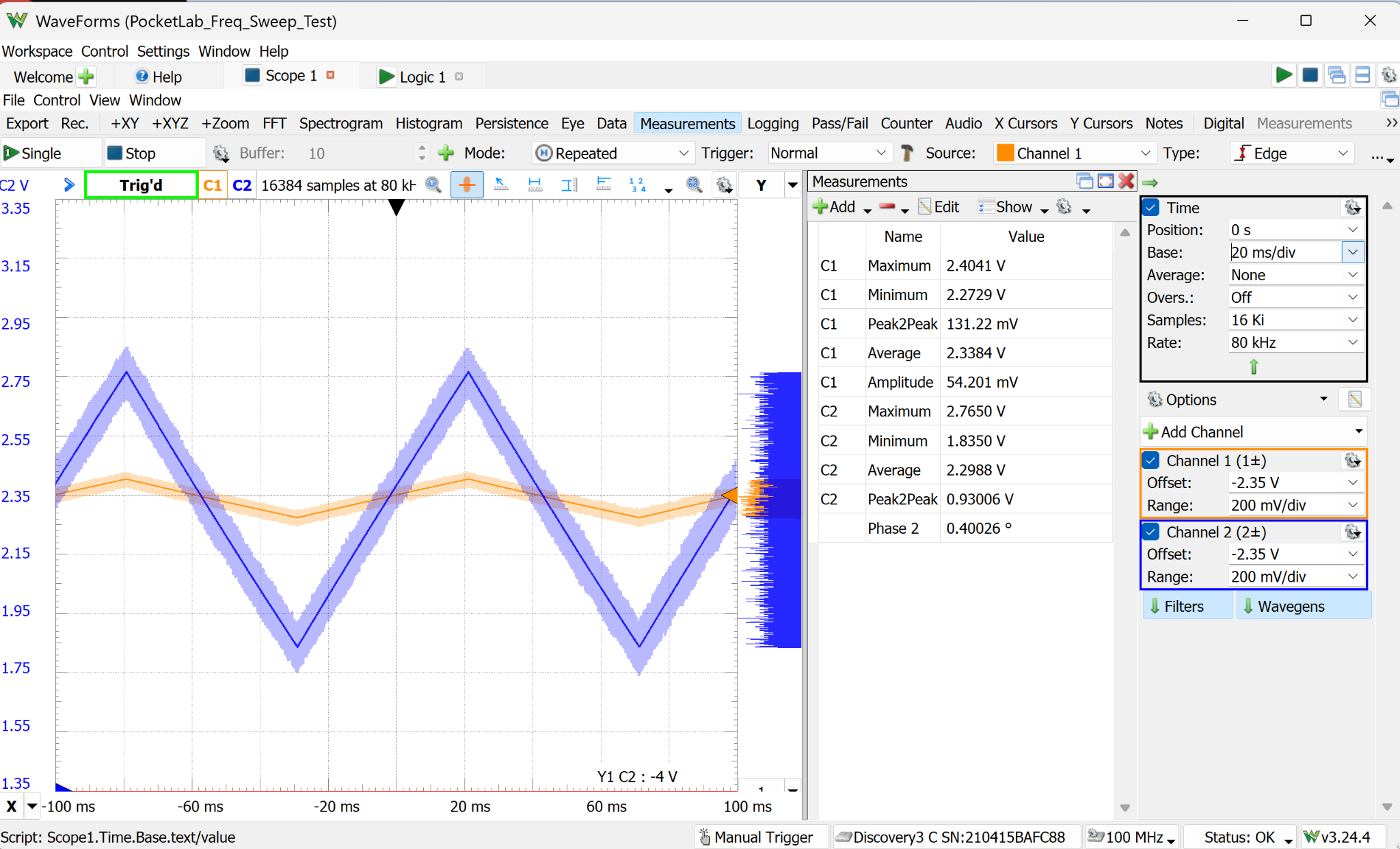
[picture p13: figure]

Figure 4. 10 Hz triangle: straight slopes, stable center, and 0.930 Vpp output.

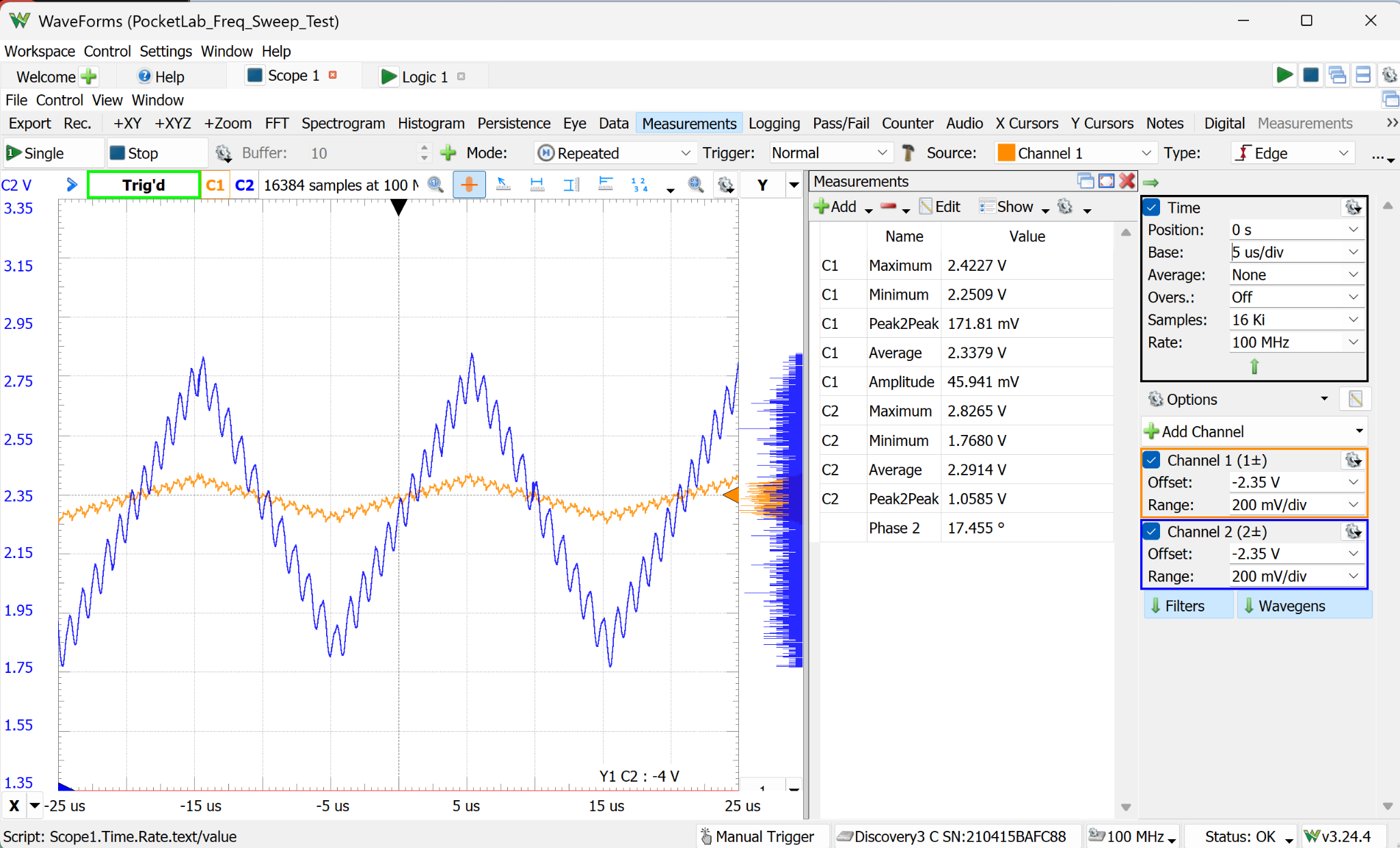
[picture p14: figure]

Figure 5. 50 kHz triangle: triangular envelope retained with severe ripple.

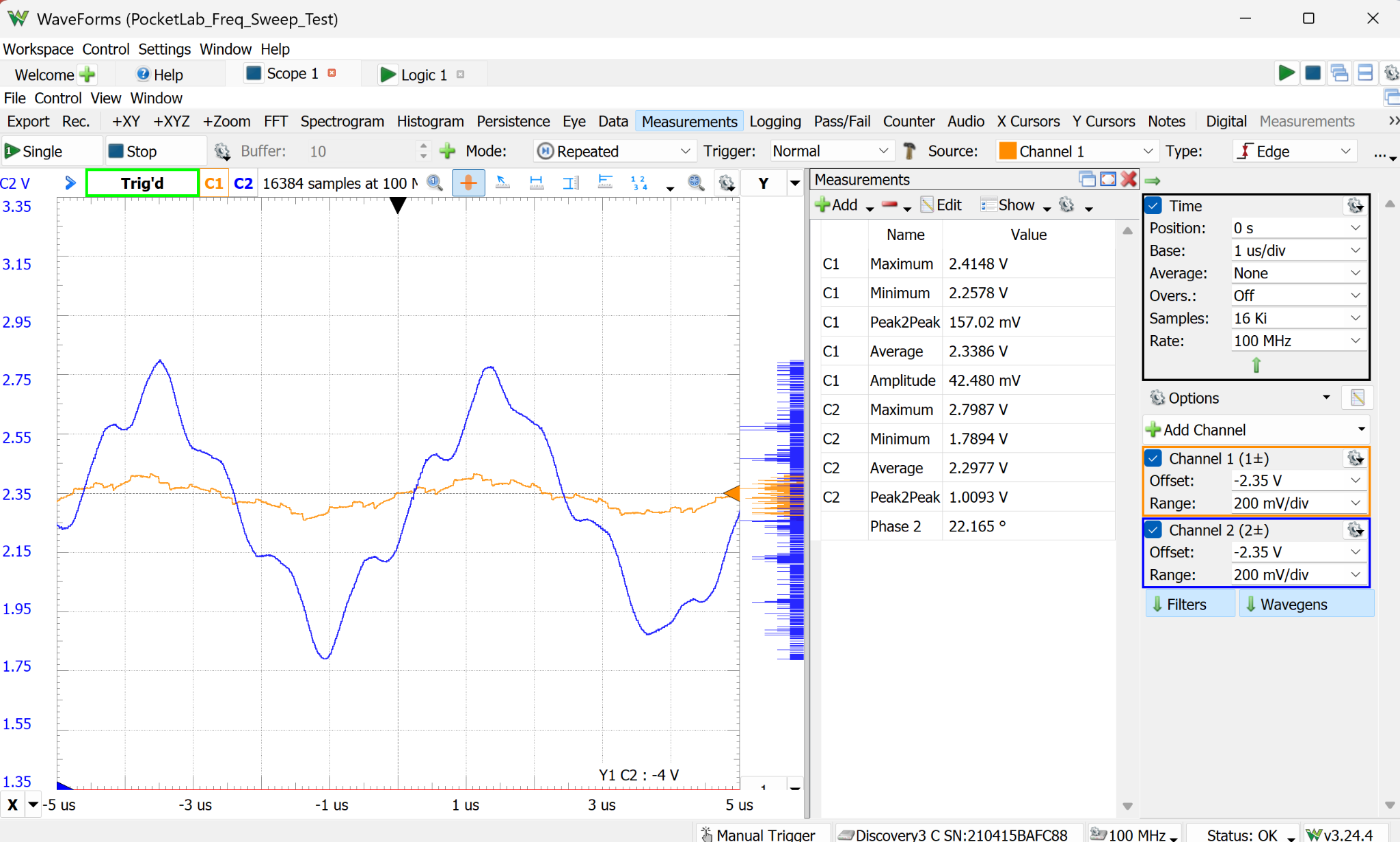
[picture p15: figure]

Figure 6. 200 kHz triangle: rounded, irregular peaks and poor waveform fidelity.

# 5. Analysis

## 5.1 Low-Frequency Coupling Response

Using the observed midband amplitudes as the reference, the 10 Hz sine result is approximately 13.5% below the 50 kHz sine amplitude (about −1.25 dB). The 10 Hz triangle result is approximately 12.3% below its 1–50 kHz midband value (about −1.13 dB). The 100 Hz results remain roughly 10–11% below midband.

The 47 µF coupling capacitor therefore provides usable 10 Hz operation, but it does not produce fully flat amplitude response at the low-frequency limit. Importantly, neither waveform showed obvious baseline tilt, slow movement, or loss of DC-offset control after settling.

## 5.2 Offset Accuracy and Stability

The requested center was 2.35 V. Nearly all output averages measured 2.298–2.300 V, with one 50 kHz triangle capture reading 2.291 V. The approximately −50 mV systematic error is small and stable, suggesting DAC/reference/path calibration rather than frequency-dependent baseline movement.

## 5.3 High-Frequency Fidelity

Periodic ripple was visible on Channel 1 and amplified on Channel 2, indicating that a substantial portion originates before the OP484 output—within or around the AD9833, X9C103S, wiring, grounding, or breadboard signal path. Amplitude measurements alone therefore overstate usable high-frequency performance: magnitude remains near target while waveform purity deteriorates.

## 5.4 Phase Behavior

The automatic phase reading increased with frequency, reaching approximately 19° for the 200 kHz sine and 22° for the 200 kHz triangle. These readings are best treated as trend indicators. The small, noisy Channel 1 signal and the harmonic content of distorted triangle waves reduce the validity of a single automatic phase value.

# 6. Acceptance Assessment

Criterion | Status | Evidence
No unsafe rail excursion | PASS | All outputs remained between approximately 1.75 V and 2.84 V.
Offset stable versus frequency | PASS | Output average remained near 2.30 V across both sweeps.
1 Vpp amplitude at 1 kHz | PASS / CAL | Measured approximately 1.06 Vpp; calibration can remove the gain error.
Usable 10 Hz output | PASS WITH LOSS | Clean waveform and stable baseline; approximately 12–14% attenuation.
High-frequency amplitude retention | PASS | Sine remained near 1.06–1.08 Vpp through 200 kHz.
High-frequency waveform fidelity | LIMITED | Visible degradation above 10–50 kHz; poor at 100–200 kHz.

# 7. Conclusions and Recommended Follow-Up

- Retain the 47 µF coupling capacitor for the current prototype; its 10 Hz response is usable and does not cause baseline instability.
- Add frequency-dependent amplitude calibration only if accurate 1.00 Vpp output at 10–100 Hz is a product requirement.
- Calibrate the DAC/offset transfer so a 2.35 V command produces approximately 2.35 V at the output rather than 2.30 V.
- Prioritize high-frequency noise investigation around grounding, supply decoupling, the X9C103S path, AD9833 clock feedthrough, and breadboard parasitics.
- Use a sine-wave FFT or residual-noise measurement in a later test to quantify the periodic ripple and identify its dominant frequency.
- Treat 100–200 kHz as amplitude-capable but not high-fidelity operation in the present breadboard implementation.

Final disposition: The offset-enabled frequency sweep passed the safety and baseline-stability objectives. Low-frequency attenuation and high-frequency distortion are characterized limitations for subsequent calibration and signal-integrity work.

PocketLab Frequency Sweep with Offset • July 16, 2026 •

POCKETLAB | FUNCTION GENERATOR VALIDATION

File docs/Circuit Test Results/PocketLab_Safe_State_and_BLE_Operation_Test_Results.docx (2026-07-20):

POCKETLAB TEST REPORT

Safe-State and BLE-Controlled Operation

AD5626 offset output and OP484 final-output transient evaluation

Project | PocketLab Programmable Function Generator
Test date | July 16, 2026 (Pacific Time)
Operating point | 1 kHz sine, 1.00 Vpp, 2.35 V offset
Acquisition | Analog Discovery 3 / WaveForms, DC-coupled dual-channel capture

# Executive Summary

Overall result: PASS — no unsafe rail excursion was observed during configuration, OUTPUT ON, OUTPUT OFF, BLE disconnect, or ESP32 reset. The largest reset-related OP484 transient was 470.23 mV and lasted approximately 0.3–0.4 ms. Both outputs returned to the 0 V safe-off state.

Improvement identified: OUTPUT ON is electrically safe but not yet clean. The AD5626 steps to its programmed bias while the OP484 output briefly follows, returns near 0 V, and then develops the commanded waveform gradually. A mute/rebias/start/restore sequence is recommended for startup.

# 1. Test Objective

Verify safe behavior of the offset and final-output stages during cold/default operation and BLE-controlled state changes, with particular attention to unintended rail excursions, prolonged transients, unstable intermediate states, and the final logical safe state.

- Power-on with output logically off
- OUTPUT ON at 1 kHz, 1.00 Vpp, and 2.35 V offset
- OUTPUT OFF while running
- BLE disconnect while running
- ESP32 reset while running

# 2. Test Configuration

Item | Configuration | Purpose
CH1 | AD5626 output | Monitor programmed DC offset and safe-off behavior
CH2 | OP484 output | Monitor final externally presented waveform/output
Coupling | DC | Preserve offset and rail-transient information
Nominal supply | Approximately 4.71 V | Reference for unsafe positive-rail excursion
Safe-off target | 0 V physical output | Firmware retains logical settings while output is disabled

# 3. Acceptance Criteria

- No output approaches or remains at either supply rail.
- No sustained oscillation or unstable intermediate state occurs.
- OUTPUT OFF, BLE disconnect, and ESP32 reset restore the logical safe state and physical 0 V safe-off output.
- Any transient is documented by peak voltage, duration, settling behavior, and final state.

# 4. Results

## 4.1 Configuration Applied While Output Was Off

The app sent SET_STATE with FREQ=1000, AMP=1.00, OFFSET=2.35, and WAVE=SINE while OUTPUT remained OFF. Both observed nodes stayed near 0 V. This confirms that changing app controls stores the requested operating point without unexpectedly energizing the physical output.

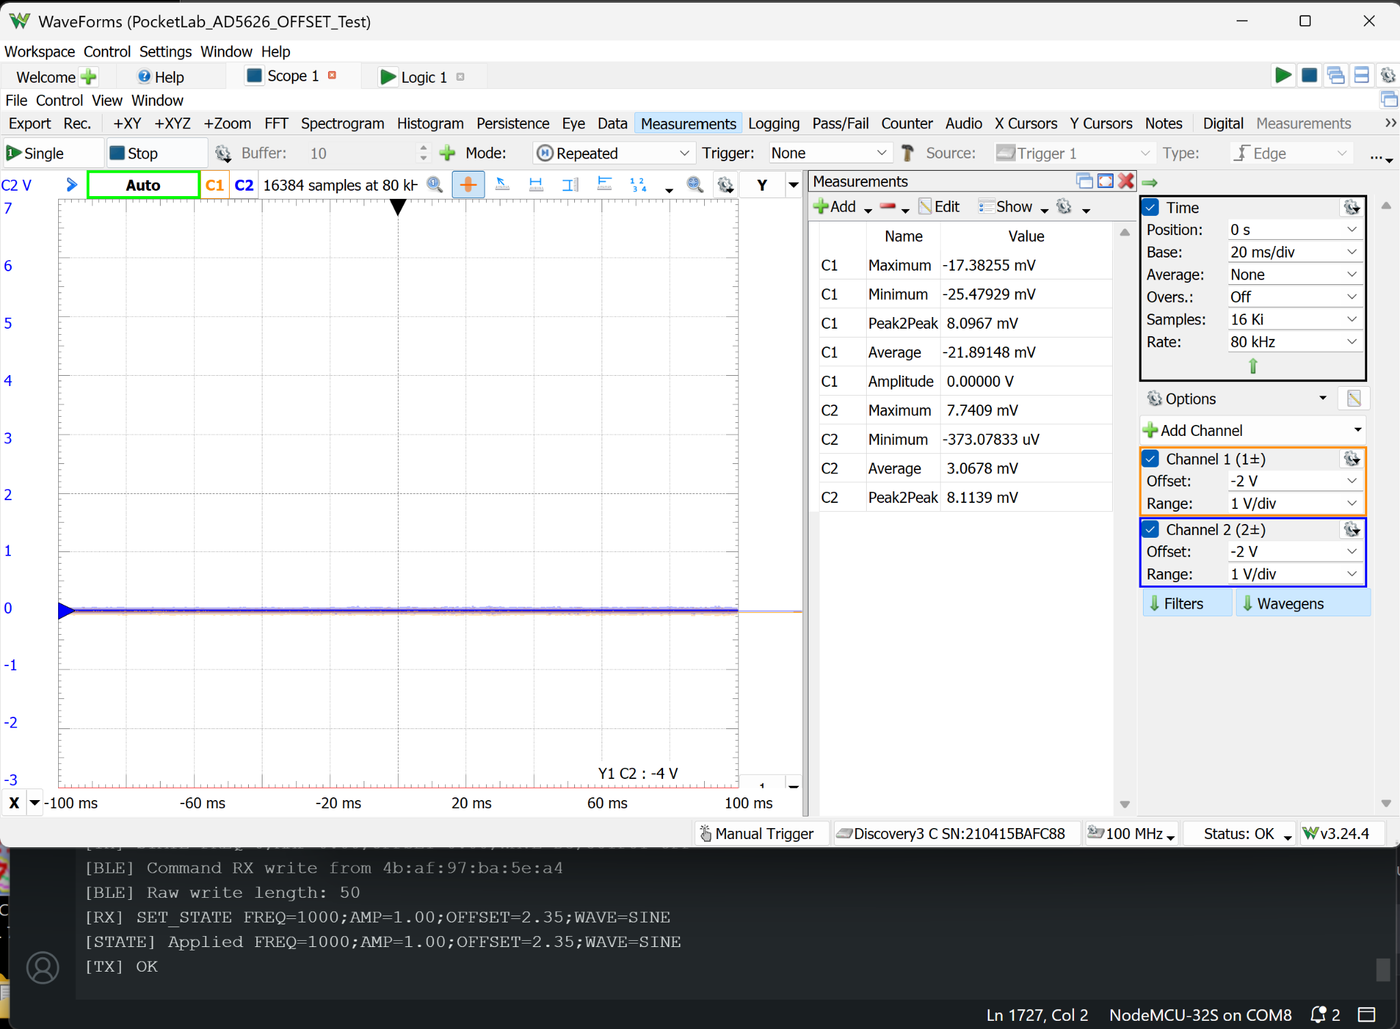
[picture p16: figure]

Figure 1. App configuration applied while OUTPUT was OFF; both physical outputs remain near 0 V.

## 4.2 OUTPUT ON

When OUTPUT ON was pressed, the AD5626 rose to approximately 2.34 V. The OP484 output initially followed the bias step, returned near 0 V, and then developed the 1 kHz waveform gradually. No excursion toward the 4.71 V supply rail was observed. The transition is safe, but the long waveform-envelope buildup is not an ideal instrument startup response.

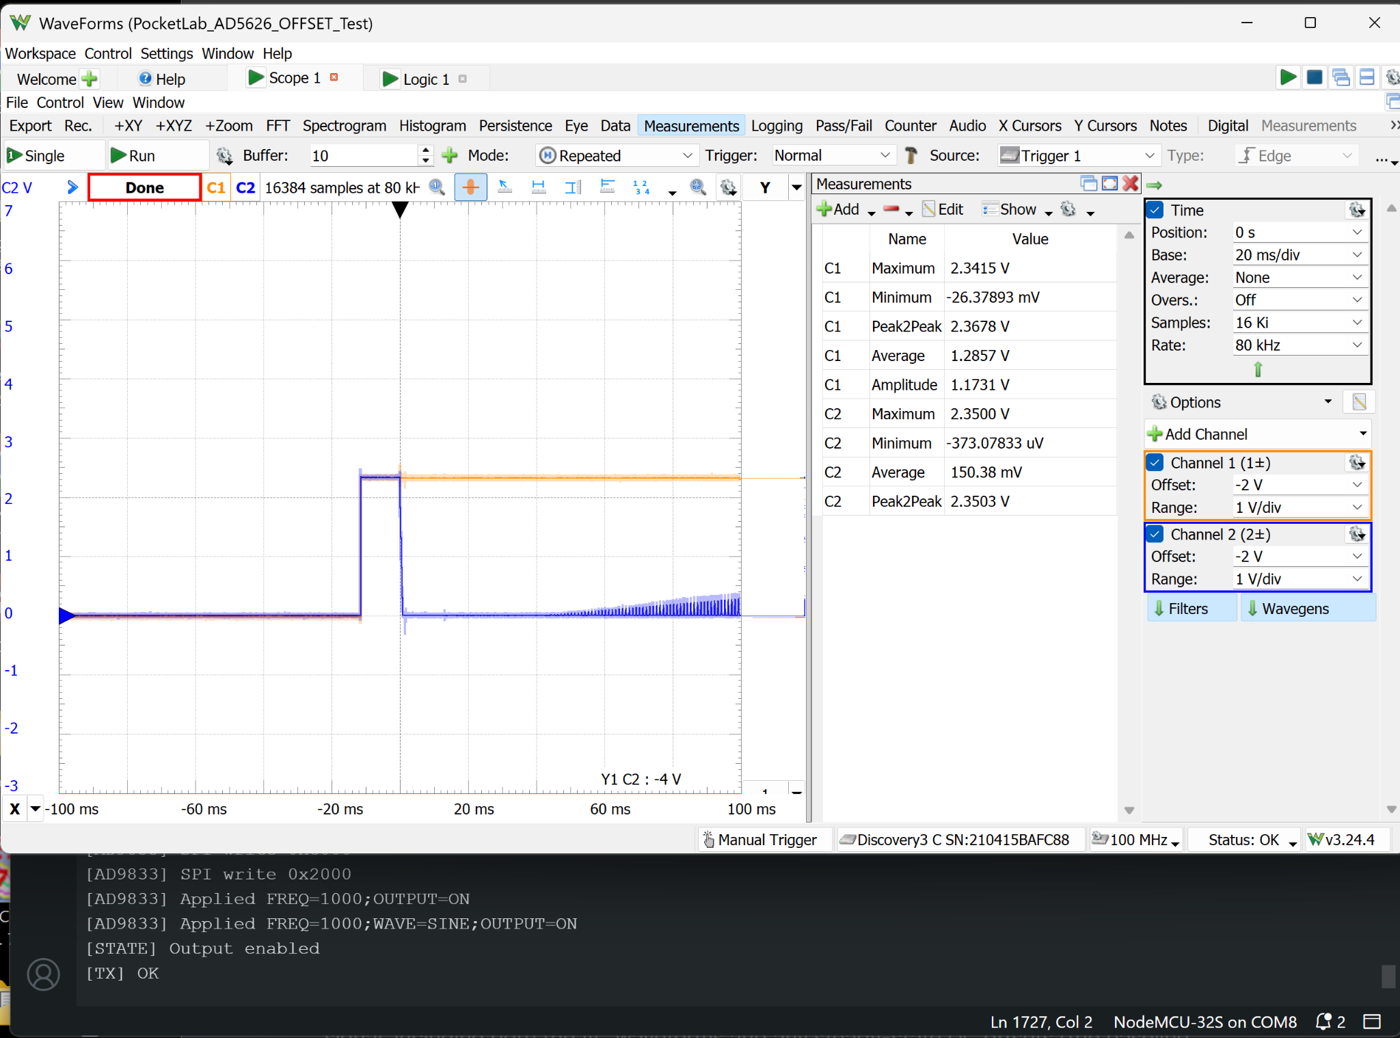
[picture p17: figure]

Figure 2. OUTPUT ON transition at 20 ms/div. CH1 steps to the offset level while the CH2 waveform envelope begins to develop.

## 4.3 OUTPUT OFF While Running

The waveform was first muted or stopped, leaving a flat level near 2.33 V for roughly 30 ms. The AD5626 and OP484 outputs then transitioned together to the 0 V safe-off level. The CH2 maximum of approximately 2.803 V is the normal upper peak of the commanded waveform, not a shutdown overshoot.

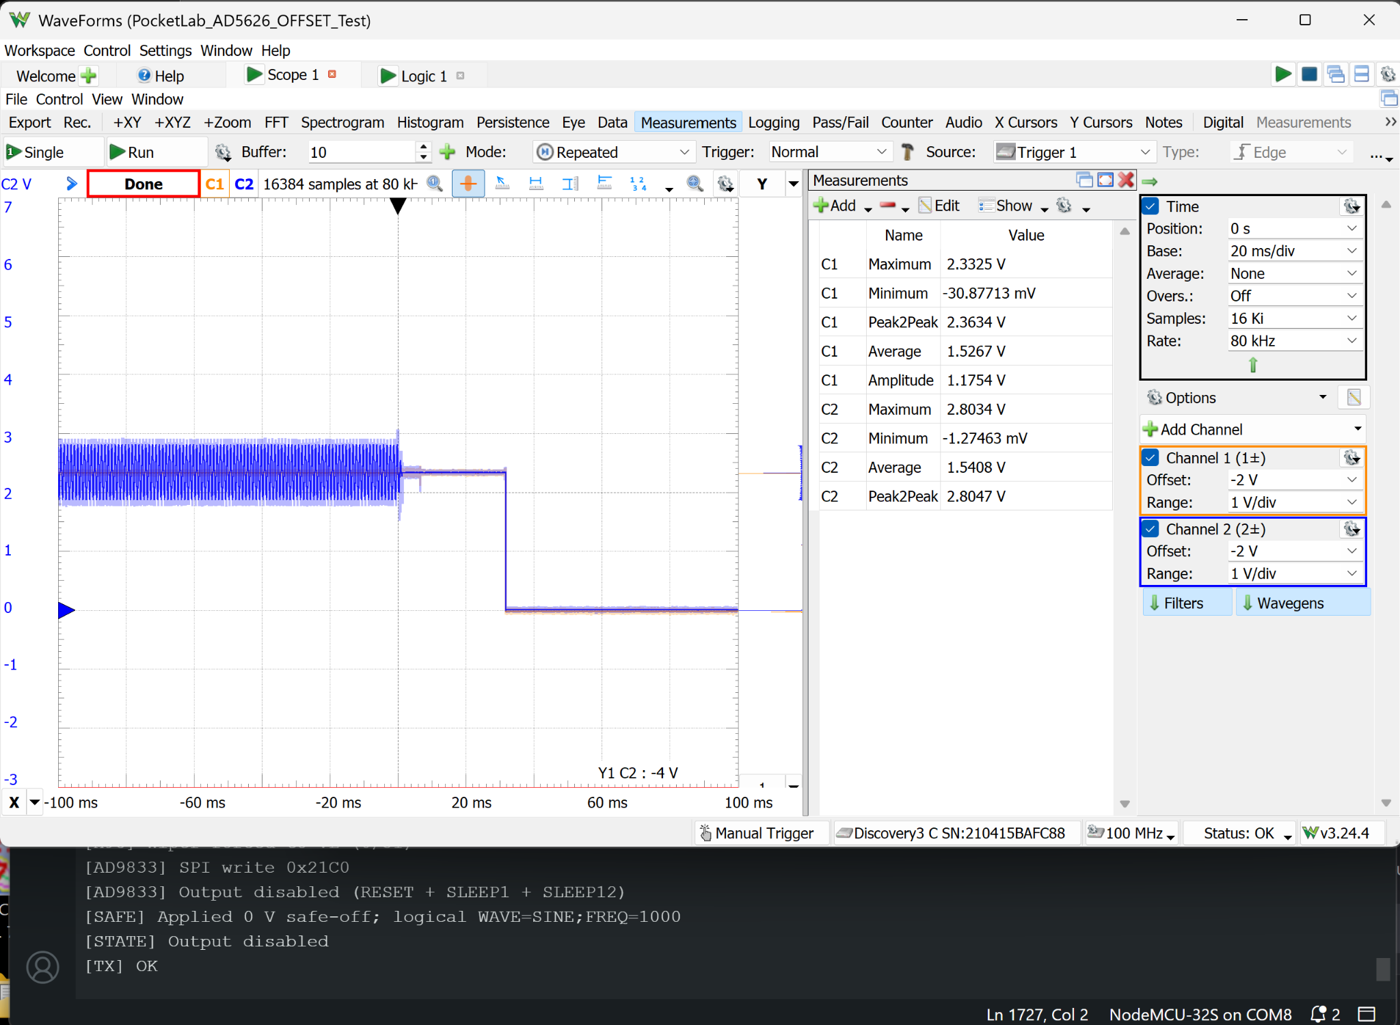
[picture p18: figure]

Figure 3. Explicit OUTPUT OFF command. The output is muted, briefly held near the bias level, and then placed at 0 V safe-off.

## 4.4 BLE Disconnect While Running

BLE disconnect produced nearly the same controlled shutdown as the explicit OUTPUT OFF command. Firmware logging confirmed that the X9C wiper was forced to VL and the AD9833 output was disabled. No unsafe excursion was observed, demonstrating that loss of the controlling client invokes the safe shutdown path.

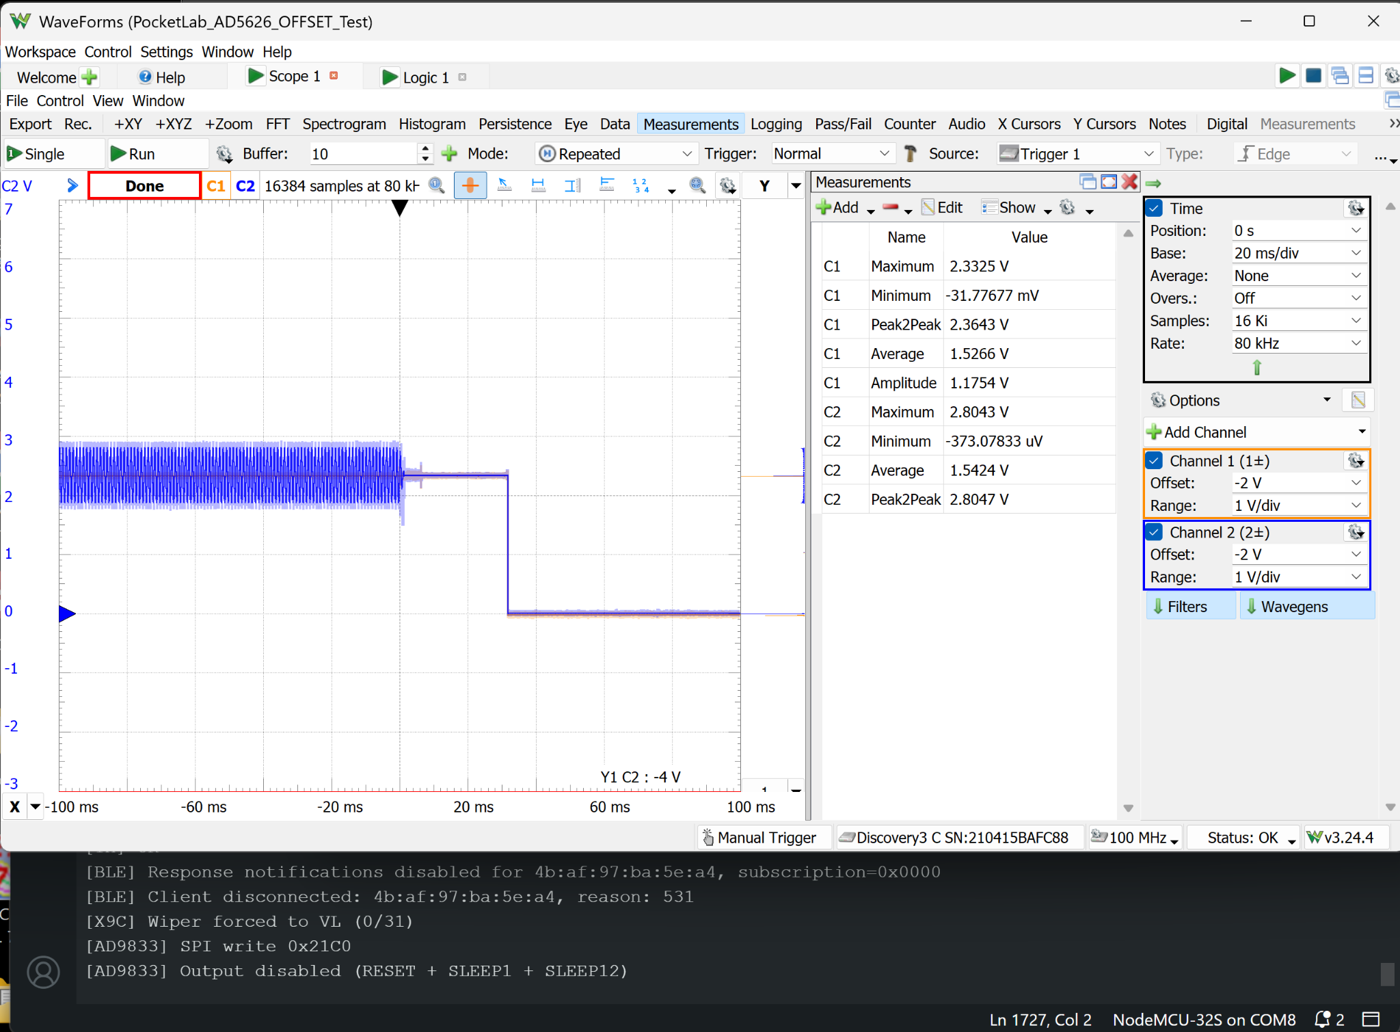
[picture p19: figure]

Figure 4. BLE disconnect while running; the controlled shutdown closely matches explicit OUTPUT OFF behavior.

## 4.5 ESP32 Reset While Running

During reset, the output collapsed to the safe-off level without a graceful application-controlled shutdown. A short, simultaneous positive pulse appeared at the AD5626 and OP484 outputs during restart. The close capture measured 436.04 mV maximum on CH1 and 470.23 mV maximum on CH2, with an estimated duration of 0.3–0.4 ms. The pulse remained far below the positive supply rail and was followed by a stable 0 V output.


Figure 5. Close capture of the ESP32 reset transient at 1 ms/div and 1.587 MHz sample rate.

# 5. Consolidated Measurements

Test | AD5626 behavior | OP484 behavior | Transient / settling | Result
Configure while OFF | Remained near 0 V | Remained near 0 V | No commanded output | PASS
OUTPUT ON | 0 V → ≈2.34 V | Bias step, near-0 interval, gradual waveform buildup | Long envelope recovery; no rail excursion | PASS*
OUTPUT OFF | ≈2.33 V → 0 V | Waveform → ≈2.33 V → 0 V | ≈30 ms biased hold before safe-off | PASS
BLE disconnect | ≈2.33 V → 0 V | Waveform → ≈2.33 V → 0 V | Matches controlled shutdown | PASS
ESP32 reset | 436.04 mV max; −31.78 mV min | 470.23 mV max; −8.49 mV min | ≈0.3–0.4 ms pulse | PASS

* PASS for electrical safety; startup quality improvement recommended.

# 6. Conclusions and Recommendations

All required transitions met the primary safety objective: no unsafe excursion toward either supply rail occurred, and all fault-like events returned the instrument to the physical 0 V safe-off state. Explicit OUTPUT OFF and BLE disconnect use an effective controlled shutdown sequence. ESP32 reset produces only a small, brief restart pulse and correctly restores the logical default state.

## Recommended OUTPUT ON sequence

1. Keep the X9C amplitude path muted.
2. Program the AD5626 to the requested offset and allow the bias network to settle.
3. Start the AD9833 at the requested frequency and waveform while muted.
4. Restore the requested amplitude in controlled steps.
5. Report OUTPUT=ON after the restoration completes.

This sequence can remain invisible to the user: the app workflow stays unchanged, with one press of OUTPUT ON after selecting waveform, frequency, amplitude, and offset.

# 7. Final Disposition

SAFE-STATE / BLE OPERATION TEST: PASS

The hardware and firmware are suitable to proceed to refinement of the OUTPUT ON transition. No additional shutdown sequencing is required based on these captures; the existing OUTPUT OFF and disconnect behavior should be preserved during future firmware changes.

Safe-State & BLE Operation Test • July 16, 2026 |

POCKETLAB | PROGRAMMABLE FUNCTION GENERATOR

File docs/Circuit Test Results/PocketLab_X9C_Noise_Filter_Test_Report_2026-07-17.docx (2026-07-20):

PocketLab Function Generator

# X9C Wiper Noise and Filter Evaluation

Engineering Test Report • 17 July 2026

Test configuration | Key outcome
Bench-powered 4.75 V analog circuit; midpoint X9C setting; 1 kHz–200 kHz sine tests | 100 pF wiper-reference capacitor gave the best tested noise suppression, with ~11% amplitude loss at 200 kHz

# 1. Objective

Determine the source of the thick, distorted waveform observed at intermediate X9C103 wiper positions, evaluate power-supply and local filtering changes, and select a practical capacitor value that prioritizes noise reduction while preserving usable bandwidth.

# 2. Hardware and Test Configuration

Item | Configuration
Signal chain | AD9833 → conditioned signal → X9C103 → OP484 output stage
Offset source | AD5626 DAC buffered by OP484; no separate VBIAS divider
X9C reference | VL connected to OP484 pin 7 (buffered DAC offset)
Compensation capacitor | Installed between X9C VW and OP484 pin 7
OP484 gain network | Rf = 62.2 kΩ, Rg = 10.00 kΩ; nominal gain = 7.22 V/V
Analog supply | 4.75 V bench supply; 10 µF + 47 µF bulk capacitance and local 100 nF bypassing
Instrumentation | Digilent Discovery 3 / WaveForms oscilloscope, logic analyzer, and FFT
Representative state | SINE, offset ≈ 2.30 V; X9C at an intermediate wiper position

# 3. Diagnostic Findings

- X9C digital control was correct: CS remained low during the update, U/D was stable, and 31 INC pulses were observed at roughly 200 µs per step.
- The distortion was strongest at intermediate wiper positions and largely absent at the endpoints, consistent with the higher Thevenin impedance of the wiper near midscale.
- FFT measurements revealed periodic interference near 1.05 MHz and harmonics near 2.10, 3.15, and 4.20 MHz. These components were coupled into the high-impedance wiper node.
- Changing from laptop USB power to a bench supply substantially reduced long-timescale supply droop. Added bulk capacitance helped, but did not by itself remove wiper-node pickup.
- The OP484 gain stage measured approximately 7.204 V/V using AC RMS measurements, closely matching the 7.22 V/V design value.

# 4. Filter Comparison

At approximately 1 kHz and the same intermediate wiper position, the residual non-sinusoidal thickness was estimated by subtracting the sine-derived peak-to-peak value from the measured peak-to-peak value.

Condition | Measured p-p | Sine-derived p-p | Excess thickness | Interpretation
No capacitor | 297.4 mV | 244.1 mV | 53.3 mV | Strong pickup/distortion
68 pF | 270.6 mV | 256.8 mV | 13.8 mV | Major improvement
100 pF | 268.88 mV | 262.36 mV | 6.52 mV | Best tested suppression

The 100 pF capacitor reduced the remaining excess thickness by approximately 53% relative to 68 pF, and by approximately 88% relative to the unfiltered midpoint measurement.

# 5. Frequency-Response Results

C1 measured X9C VW and C2 measured X9C VH. Wiper ratio = C1 AC RMS ÷ C2 AC RMS.

Capacitor | Frequency | VW AC RMS | VH AC RMS | Wiper ratio | Change from 1 kHz
68 pF | 1 kHz | — | — | 0.45134 | Reference
68 pF | 200 kHz | — | — | 0.41579 | −7.88% (−0.71 dB)
100 pF | 1 kHz | 92.845 mV | 205.84 mV | 0.45106 | Reference
100 pF | 10 kHz | 93.123 mV | 206.56 mV | 0.45084 | −0.05%
100 pF | 50 kHz | 92.482 mV | 207.19 mV | 0.44636 | −1.04%
100 pF | 100 kHz | 89.746 mV | 206.79 mV | 0.43398 | −3.79%
100 pF | 200 kHz | 82.451 mV | 206.11 mV | 0.40004 | −11.31% (−1.04 dB)

# 6. Interpretation

The original high-frequency waveform degradation was not primarily an AD9833 waveform-generation limit. It was dominated by interference coupled into the X9C wiper while the wiper presented a high source impedance. The 100 pF capacitor provides a lower-impedance high-frequency path to the buffered offset reference, materially cleaning the waveform.

The tradeoff is predictable frequency-dependent attenuation. With 100 pF installed, the midpoint wiper ratio remained essentially unchanged through 10 kHz, fell about 3.8% by 100 kHz, and fell about 11.3% by 200 kHz. The present 200 kHz waveform is smooth and symmetric compared with the earlier multi-lobed, stair-stepped result.

# 7. Conclusions

- Keep the 100 pF capacitor from X9C VW to OP484 pin 7 as the provisional hardware configuration.
- Retain the bench-supply and local-decoupling improvements; power integrity and wiper filtering address different parts of the observed noise.
- Treat the remaining amplitude roll-off as a calibration problem rather than removing the filter and reintroducing distortion.
- Do not assume a single amplitude scale factor: correction will depend on both frequency and X9C wiper position.

# 8. Recommended Next Steps

1. Finalize the shorter-lead breadboard layout with the 100 pF capacitor and the current bypass/bulk capacitors installed.
2. Repeat the formal frequency sweep on the final physical layout, including 1, 10, 50, 100, 150, and 200 kHz checkpoints.
3. Build a two-dimensional calibration table across frequency and X9C positions (suggested positions: 0, 4, 8, 12, 16, 20, 24, 28, and 31).
4. Use interpolation in firmware to compensate amplitude attenuation while enforcing output-envelope and maximum-headroom limits.
5. Measure phase shift and harmonic distortion separately; amplitude correction cannot compensate phase lag or residual waveform-shape error.
6. Revalidate amplitude/offset envelope limits after calibration, especially at maximum amplitude and near the output rails.

# 9. Test Limitations

Measurements were made on a solderless breadboard and are sensitive to probe placement, lead length, grounding, X9C position, and acquisition settings. Values should therefore be treated as engineering characterization rather than final production specifications. The 100 pF decision is provisional until the rebuilt layout is swept under the same measurement conditions.

PocketLab X9C Noise and Filter Evaluation • 17 July 2026

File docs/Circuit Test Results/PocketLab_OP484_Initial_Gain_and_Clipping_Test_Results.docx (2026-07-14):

PocketLab OP484 Analog Amplifier Stage

Initial Gain, Safe-Idle, Waveform Fidelity, and Clipping Test Results

Project | PocketLab Function Generator | Test date | July 13, 2026
Test time | Approximately 5:00–6:00 PM PDT | Author | Mark Anderson

# Purpose

The purpose of this test was to build and characterize the first OP484 analog-conditioning stage using the known-good AD9833 sine and triangle outputs. The stage AC-couples the DDS signal, replaces its approximately 0.34 V DC bias with a buffered half-supply reference, and applies noninverting voltage gain. Testing established basic gain accuracy, waveform fidelity, stopped-output behavior, and the maximum useful swing available from a USB-powered 4.71–4.75 V supply.

# Circuit configuration

Item | Connection / value
Amplifier | OP484, channel A; single-supply operation
Supply | ESP32 USB-derived 5 V pin; measured 4.71–4.75 V
Reference | Equal-resistor divider buffered by OP484 channel B; approximately 2.4 V
Signal coupling | AD9833 OUT through 1 µF capacitor; 100 kΩ bias resistor to buffered VREF
Gain topology | Noninverting: Av = 1 + Rf/Rg
Measured Rg | 10.19 kΩ, from channel A inverting input to buffered VREF
Oscilloscope load | Digilent Analog Discovery / WaveForms, high-impedance input
Test frequency | Approximately 1 kHz

# Results summary

Test | Rf | Calculated gain | Input | Output | Measured gain | Result
Initial sine | 10 kΩ | 2.00 | ≈0.607 Vpp | 1.2146 Vpp | ≈2.00 | Clean
Sine | 46.3 kΩ | 5.544 | 0.61292 Vpp | 3.3214 Vpp | 5.419 | Clean
Triangle | 46.3 kΩ | 5.544 | 0.60842 Vpp | 3.3268 Vpp | 5.468 | Clean
High-gain sine | 67.9 kΩ | 7.664 | 0.61022 Vpp | 4.5793 Vpp | 7.504 | Rail limit
Overdrive sine | 89.9 kΩ | 9.822 | 0.61112 Vpp | 4.7111 Vpp | 7.709* | Clipped

* The clipped-stage Vpp ratio is not the linear gain; the output is constrained by the supply rails.

# Safe-idle observation

When firmware stopped the AD9833 output, the 1 kHz waveform disappeared and the amplifier output settled to the buffered reference. WaveForms measured an average of 2.4107 V with 26.188 mV peak-to-peak residual activity at the displayed scale. This confirms that the AC-coupling network prevents the AD9833 stopped-state DC level from being amplified. It does not yet create a ground-referenced 0 V external safe-off state; the present internal idle level is approximately VREF.


Figure 1. OP484 output after stopping the AD9833: approximately 2.41 V internal idle level with no 1 kHz waveform.

# Waveform fidelity at gain ≈ 5.54

Using measured resistor values Rf = 46.3 kΩ and Rg = 10.19 kΩ, the calculated closed-loop gain was 5.544. The measured sine and triangle gains were 5.419 and 5.468, respectively. Both waveforms remained stable and unclipped. The triangle retained straight slopes and sharp turning points, indicating that the amplifier reproduced the AD9833 waveform without visible slew-rate limitation at 1 kHz.


Figure 2. Simultaneous sine measurement: C1 is the raw AD9833 output; C2 is the OP484 output at measured gain 5.419.


Figure 3. Triangle-wave fidelity at measured gain 5.468. No visible clipping, ringing, or instability was observed.
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

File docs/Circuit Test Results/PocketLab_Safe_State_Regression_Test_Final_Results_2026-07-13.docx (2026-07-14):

PocketLab Safe-State
Regression Test

Final Test Results

Project | PocketLab BLE-Controlled Function Generator
Firmware | PocketLab-FG.safe-idle.ino, version 0.3.2
Controller | ESP32 NodeMCU-32S
Signal source | AD9833 DDS module
Test instrument | Digilent Analog Discovery / WaveForms
Date and time | July 13, 2026, 2:19 PM Pacific Daylight Time (PDT)

OVERALL RESULT: PASS

All eight regression tests passed. The hardware boots safely, STOP and BLE disconnect force the AD9833 into safe-off mode, reconnection does not restart the output, and invalid DC output requests are rejected.
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

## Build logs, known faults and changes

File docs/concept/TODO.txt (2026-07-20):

# Mobile TODO
- fix header so it doesn't have container padding
- better color schemes for light and dark mode
- use number input for DC offset
- use dropdown/select field for wave type
- implement local storage to save and retrieve wave settings

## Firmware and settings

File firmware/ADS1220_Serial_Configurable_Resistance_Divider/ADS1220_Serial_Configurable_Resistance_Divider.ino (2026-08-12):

/*
  PocketLab DMM — serial-configurable ADS1220 resistance-divider test

  Target: ESP32 NodeMCU-32S + bare ADS1220IPWR breakout

  Divider wiring:

      3.3 V / AVDD ---- Rref ----+---- AIN0 (pin 11)
                                 |
                                 Rx   unknown, unpowered resistor
                                 |
      AGND ----------------------+---- AIN1 (pin 10)

      REFP0 (pin 9)  ---- same 3.3 V / AVDD rail
      REFN0 (pin 8)  ---- AGND / AVSS

  The excitation rail is also the ADC reference, so the result is ratiometric:

      k  = signed ADC code / 2^23
      Rx = Rref * k / (1 - k)

  CONFIG0 bypasses the PGA so AIN1 may be connected to ground on a unipolar
  supply. Both ADS1220 IDACs are disabled. This is an unprotected breadboard
  circuit: connect only unpowered resistors/components and discharged capacitors.

  ADS1220 / ESP32 wiring:
    ADS1220 SCLK  -> ESP32 GPIO18
    ADS1220 MOSI  -> ESP32 GPIO23
    ADS1220 MISO  -> ESP32 GPIO19
    ADS1220 CS    -> ESP32 GPIO27
    ADS1220 DRDY  -> ESP32 GPIO26
    ADS1220 AVDD  -> ESP32 3V3
    ADS1220 AGND  -> ESP32 GND
    ADS1220 CLK   -> ADS1220 DGND

  Serial examples (115200 baud, newline ending):

      rref 1000000      set the measured reference resistance in ohms
      samples 10        average 10 conversions per report (1..100)
      interval 500      wait 500 ms after each report (0..60000)
      zero 0            resistance correction subtracted from each result
      predict 4700000   print the expected ratio and voltage for 4.7 Mohm Rx
      start              begin continuous reports
      stop               pause reports
      once               take one averaged report
      status             show current settings
      regs               read back ADS1220 registers
      adcreset           reset and reconfigure the ADS1220
      defaults           restore software defaults and reconfigure
      help               list commands

  Settings are retained until reset/power-cycle; no firmware rebuild is needed
  when Rref, Rx, averaging, or report timing changes.
*/

#include <Arduino.h>
#include <SPI.h>
#include <math.h>

constexpr int PIN_SCLK = 18;
constexpr int PIN_MISO = 19;  // ADS1220 pin 15, DOUT/DRDY
constexpr int PIN_MOSI = 23;  // ADS1220 pin 16, DIN
constexpr int PIN_CS   = 27;  // ADS1220 pin 2, CS
constexpr int PIN_DRDY = 26;  // ADS1220 pin 14, dedicated DRDY

constexpr uint32_t SERIAL_BAUD = 115200;
constexpr uint32_t SPI_CLOCK_HZ = 1000000;
constexpr uint32_t DRDY_TIMEOUT_MS = 500;

constexpr double DEFAULT_RREF_OHMS = 1000000.0;
constexpr uint16_t DEFAULT_SAMPLES = 10;
constexpr uint32_t DEFAULT_REPORT_INTERVAL_MS = 500;
constexpr double DEFAULT_ZERO_OFFSET_OHMS = 0.0;

constexpr uint16_t MAX_SAMPLES = 100;
constexpr uint32_t MAX_REPORT_INTERVAL_MS = 60000;
constexpr double MIN_RREF_OHMS = 1.0;
constexpr double MAX_RREF_OHMS = 1.0e9;

constexpr uint8_t CMD_RESET      = 0x06;
constexpr uint8_t CMD_START_SYNC = 0x08;
constexpr uint8_t CMD_POWERDOWN  = 0x02;
constexpr uint8_t CMD_RDATA      = 0x10;

// AIN0-AIN1, gain 1, PGA bypassed for a ground-referenced unipolar input.
constexpr uint8_t CONFIG0 = 0x01;
// 20 SPS, normal mode, continuous conversion.
constexpr uint8_t CONFIG1 = 0x04;
// External REFP0/REFN0 reference; IDAC current sources disabled.
constexpr uint8_t CONFIG2 = 0x40;
// Both IDAC outputs disconnected.
constexpr uint8_t CONFIG3 = 0x00;

constexpr uint8_t EXPECTED_REGS[4] = {
  CONFIG0, CONFIG1, CONFIG2, CONFIG3
};

constexpr int32_t ADC_POSITIVE_FULL_SCALE = 0x7FFFFF;
constexpr int32_t ADC_NEGATIVE_FULL_SCALE = -0x800000;
constexpr double ADC_DENOMINATOR = 8388608.0;  // 2^23

SPISettings adsSpiSettings(SPI_CLOCK_HZ, MSBFIRST, SPI_MODE1);

double rrefOhms = DEFAULT_RREF_OHMS;
double zeroOffsetOhms = DEFAULT_ZERO_OFFSET_OHMS;
uint16_t samplesPerReport = DEFAULT_SAMPLES;
uint32_t reportIntervalMs = DEFAULT_REPORT_INTERVAL_MS;
bool streamingEnabled = false;
bool adcConfigured = false;
uint32_t lastReportFinishedMs = 0;
String serialCommand;

void selectAds() {
  SPI.beginTransaction(adsSpiSettings);
  digitalWrite(PIN_CS, LOW);
  delayMicroseconds(2);
}

void deselectAds() {
  delayMicroseconds(2);
  digitalWrite(PIN_CS, HIGH);
  SPI.endTransaction();
}

void sendCommand(uint8_t command) {
  selectAds();
  SPI.transfer(command);
  deselectAds();
}

void writeRegisters(const uint8_t *values, uint8_t count) {
  if (count == 0 || count > 4) return;

  // WREG starting at register 0; low two bits encode count - 1.
  const uint8_t command = 0x40 | ((count - 1) & 0x03);
  selectAds();
  SPI.transfer(command);
  for (uint8_t i = 0; i < count; ++i) SPI.transfer(values[i]);
  deselectAds();
}

void readRegisters(uint8_t *values, uint8_t count) {
  if (count == 0 || count > 4) return;

  // RREG starting at register 0; low two bits encode count - 1.
  const uint8_t command = 0x20 | ((count - 1) & 0x03);
  selectAds();
  SPI.transfer(command);
  for (uint8_t i = 0; i < count; ++i) values[i] = SPI.transfer(0x00);
  deselectAds();
}

void printHexByte(uint8_t value) {
  if (value < 0x10) Serial.print('0');
  Serial.print(value, HEX);
}

bool verifyRegisters() {
  uint8_t actual[4] = {};
  readRegisters(actual, 4);

  bool match = true;
  for (uint8_t i = 0; i < 4; ++i) {
    if (actual[i] != EXPECTED_REGS[i]) match = false;
  }

  Serial.print("Registers: ");
  for (uint8_t i = 0; i < 4; ++i) {
    printHexByte(actual[i]);
    if (i < 3) Serial.print(' ');
  }
  Serial.print(match ? "  [PASS] expected " : "  [FAIL] expected ");
  for (uint8_t i = 0; i < 4; ++i) {
    printHexByte(EXPECTED_REGS[i]);
    if (i < 3) Serial.print(' ');
  }
  Serial.println();
  return match;
}

bool configureAdc() {
  streamingEnabled = false;
  adcConfigured = false;

  sendCommand(CMD_RESET);
  delay(2);
  writeRegisters(EXPECTED_REGS, 4);
  delay(2);

  if (!verifyRegisters()) {
    Serial.println("STOP: ADS1220 register verification failed.");
    Serial.println("Check power, common ground, CS, MISO/MOSI, and SPI mode.");
    return false;
  }

  sendCommand(CMD_START_SYNC);
  delay(60);
  adcConfigured = true;
  lastReportFinishedMs = millis();
  Serial.println("ADS1220 divider mode configured; streaming remains stopped.");
  return true;
}

bool waitForDataReady(uint32_t timeoutMs) {
  const uint32_t started = millis();
  while (digitalRead(PIN_DRDY) == HIGH) {
    if (millis() - started >= timeoutMs) return false;
    delay(1);
  }
  return true;
}

int32_t readConversion() {
  selectAds();
  SPI.transfer(CMD_RDATA);
  const uint32_t msb = SPI.transfer(0x00);
  const uint32_t mid = SPI.transfer(0x00);
  const uint32_t lsb = SPI.transfer(0x00);
  deselectAds();

  uint32_t raw = (msb << 16) | (mid << 8) | lsb;
  if (raw & 0x800000UL) raw |= 0xFF000000UL;
  return static_cast<int32_t>(raw);
}

bool codeToResistance(double code, double &resistanceOhms) {
  const double ratio = code / ADC_DENOMINATOR;
  if (ratio < 0.0 || ratio >= 1.0) return false;

  resistanceOhms = rrefOhms * ratio / (1.0 - ratio);
  return isfinite(resistanceOhms);
}

void printResistance(double ohms, uint8_t decimals = 3) {
  const double magnitude = fabs(ohms);
  if (magnitude >= 1.0e6) {
    Serial.print(ohms / 1.0e6, decimals);
    Serial.print(" Mohm");
  } else if (magnitude >= 1.0e3) {
    Serial.print(ohms / 1.0e3, decimals);
    Serial.print(" kohm");
  } else {
    Serial.print(ohms, decimals);
    Serial.print(" ohm");
  }
}

bool reportMeasurement() {
  if (!adcConfigured) {
    Serial.println("ADC is not configured. Send adcreset.");
    return false;
  }

  int64_t codeSum = 0;
  int32_t codeMin = ADC_POSITIVE_FULL_SCALE;
  int32_t codeMax = ADC_NEGATIVE_FULL_SCALE;

  for (uint16_t i = 0; i < samplesPerReport; ++i) {
    if (!waitForDataReady(DRDY_TIMEOUT_MS)) {
      Serial.println("TIMEOUT: DRDY stayed high. Check pin 14 -> GPIO 26.");
      return false;
    }

    const int32_t code = readConversion();
    codeSum += code;
    if (code < codeMin) codeMin = code;
    if (code > codeMax) codeMax = code;
  }

  const double averageCode =
      static_cast<double>(codeSum) / static_cast<double>(samplesPerReport);
  const double ratio = averageCode / ADC_DENOMINATOR;
  double rawResistance = NAN;
  const bool valid = codeToResistance(averageCode, rawResistance);

  Serial.print("avg_code=");
  Serial.print(averageCode, 1);
  Serial.print("  ratio=");
  Serial.print(100.0 * ratio, 5);
  Serial.print("%  ");

  if (!valid) {
    Serial.print("Rx=INVALID");
  } else {
    const double correctedResistance = rawResistance - zeroOffsetOhms;
    Serial.print("Rx=");
    printResistance(correctedResistance);
    Serial.print("  raw=");
    printResistance(rawResistance);

    double minResistance = NAN;
    double maxResistance = NAN;
    if (codeToResistance(codeMin, minResistance) &&
        codeToResistance(codeMax, maxResistance)) {
      Serial.print("  span=");
      printResistance(maxResistance - minResistance);
    }
  }

  if (codeMax >= ADC_POSITIVE_FULL_SCALE - 1000 || ratio >= 0.999) {
    Serial.print("  [NEAR +FS: open circuit or Rx too high]");
  } else if (codeMin <= ADC_NEGATIVE_FULL_SCALE + 1000 || ratio < 0.0) {
    Serial.print("  [NEGATIVE: check AIN0/AIN1 polarity]");
  }
  Serial.println();
  lastReportFinishedMs = millis();
  return valid;
}

void printStatus() {
  Serial.println();
  Serial.println("Current divider settings:");
  Serial.print("  Rref:       ");
  printResistance(rrefOhms, 6);
  Serial.println();
  Serial.print("  zero:       ");
  printResistance(zeroOffsetOhms, 6);
  Serial.println();
  Serial.print("  samples:    ");
  Serial.println(samplesPerReport);
  Serial.print("  interval:   ");
  Serial.print(reportIntervalMs);
  Serial.println(" ms after each report");
  Serial.print("  ADC:        ");
  Serial.println(adcConfigured ? "configured" : "not configured");
  Serial.print("  streaming:  ");
  Serial.println(streamingEnabled ? "on" : "off");
  Serial.println("  registers:  expected 01 04 40 00");
  Serial.println();
}

void printPrediction(double rxOhms) {
  if (!isfinite(rxOhms) || rxOhms < 0.0) {
    Serial.println("ERROR: predict value must be a nonnegative resistance in ohms.");
    return;
  }

  const double ratio = rxOhms / (rrefOhms + rxOhms);
  Serial.print("For Rx=");
  printResistance(rxOhms, 6);
  Serial.print(" with Rref=");
  printResistance(rrefOhms, 6);
  Serial.println(':');
  Serial.print("  expected ratio / ADC full scale: ");
  Serial.print(100.0 * ratio, 5);
  Serial.println('%');
  Serial.print("  expected divider node: Vexc * ");
  Serial.println(ratio, 8);
  Serial.print("  at 3.300 V excitation: ");
  Serial.print(3.3 * ratio, 6);
  Serial.println(" V");
}

void printHelp() {
  Serial.println();
  Serial.println("PocketLab ADS1220 serial-configurable resistance divider");
  Serial.println("---------------------------------------------------------");
  Serial.println("Wiring: 3.3V--Rref--AIN0--Rx--AIN1/GND");
  Serial.println("        REFP0=3.3V, REFN0=GND; IDACs disabled");
  Serial.println("WARNING: connect only unpowered resistors/components.");
  Serial.println();
  Serial.println("Commands (values are decimal; press Enter):");
  Serial.println("  rref <ohms>       set measured Rref, 1 to 1e9 ohms");
  Serial.println("  samples <1..100>  conversions averaged per report");
  Serial.println("  interval <ms>     post-report pause, 0..60000 ms");
  Serial.println("  zero <ohms>       subtract this correction from Rx");
  Serial.println("  predict <ohms>    expected ratio and divider voltage");
  Serial.println("  start             start continuous reports");
  Serial.println("  stop              pause continuous reports");
  Serial.println("  once              take one averaged report");
  Serial.println("  status            show settings and state");
  Serial.println("  regs              read and verify registers");
  Serial.println("  adcreset          reset/reconfigure ADC; stream stays off");
  Serial.println("  powerdown         power down ADC; use adcreset to restart");
  Serial.println("  defaults          restore defaults and reconfigure ADC");
  Serial.println("  help              show this help");
  Serial.println();
  Serial.println("Typical setup:");
  Serial.println("  rref 1000000");
  Serial.println("  predict 4700000");
  Serial.println("  start");
  Serial.println();
}

bool splitCommand(const String &line, String &name, String &argument) {
  const int separator = line.indexOf(' ');
  if (separator < 0) {
    name = line;
    argument = "";
  } else {
    name = line.substring(0, separator);
    argument = line.substring(separator + 1);
    argument.trim();
  }
  name.trim();
  name.toLowerCase();
  return name.length() > 0;
}

bool parseDoubleStrict(const String &text, double &value) {
  if (text.length() == 0) return false;
  char *end = nullptr;
  value = strtod(text.c_str(), &end);
  while (end != nullptr && *end == ' ') ++end;
  return end != text.c_str() && end != nullptr && *end == '\0' && isfinite(value);
}

bool parseUnsignedLongStrict(const String &text, unsigned long &value) {
  if (text.length() == 0 || text.charAt(0) == '-') return false;
  char *end = nullptr;
  value = strtoul(text.c_str(), &end, 10);
  while (end != nullptr && *end == ' ') ++end;
  return end != text.c_str() && end != nullptr && *end == '\0';
}

void processSerialCommand(String line) {
  line.trim();
  if (line.length() == 0) return;

  String command;
  String argument;
  if (!splitCommand(line, command, argument)) return;

  if (command == "rref") {
    double value = NAN;
    if (!parseDoubleStrict(argument, value) ||
        value < MIN_RREF_OHMS || value > MAX_RREF_OHMS) {
      Serial.println("ERROR: use rref <ohms>, from 1 to 1e9.");
      return;
    }
    rrefOhms = value;
    Serial.print("Rref set to ");
    printResistance(rrefOhms, 6);
    Serial.println(". No ADC restart needed.");
  } else if (command == "samples") {
    unsigned long value = 0;
    if (!parseUnsignedLongStrict(argument, value) ||
        value < 1 || value > MAX_SAMPLES) {
      Serial.println("ERROR: use samples <1..100>.");
      return;
    }
    samplesPerReport = static_cast<uint16_t>(value);
    Serial.print("Samples per report set to ");
    Serial.println(samplesPerReport);
  } else if (command == "interval") {
    unsigned long value = 0;
    if (!parseUnsignedLongStrict(argument, value) ||
        value > MAX_REPORT_INTERVAL_MS) {
      Serial.println("ERROR: use interval <0..60000> milliseconds.");
      return;
    }
    reportIntervalMs = static_cast<uint32_t>(value);
    Serial.print("Post-report interval set to ");
    Serial.print(reportIntervalMs);
    Serial.println(" ms");
  } else if (command == "zero") {
    double value = NAN;
    if (!parseDoubleStrict(argument, value) || fabs(value) > 1.0e9) {
      Serial.println("ERROR: use zero <ohms>, magnitude <= 1e9.");
      return;
    }
    zeroOffsetOhms = value;
    Serial.print("Zero correction set to ");
    printResistance(zeroOffsetOhms, 6);
    Serial.println();
  } else if (command == "predict") {
    double value = NAN;
    if (!parseDoubleStrict(argument, value)) {
      Serial.println("ERROR: use predict <Rx ohms>.");
      return;
    }
    printPrediction(value);
  } else if (command == "start") {
    if (!adcConfigured) {
      Serial.println("ADC is not configured. Send adcreset first.");
      return;
    }
    streamingEnabled = true;
    lastReportFinishedMs = millis() - reportIntervalMs;
    Serial.println("Continuous reporting started.");
  } else if (command == "stop") {
    streamingEnabled = false;
    Serial.println("Continuous reporting stopped.");
  } else if (command == "once") {
    reportMeasurement();
  } else if (command == "status") {
    printStatus();
  } else if (command == "regs") {
    verifyRegisters();
  } else if (command == "adcreset") {
    configureAdc();
  } else if (command == "powerdown") {
    sendCommand(CMD_POWERDOWN);
    streamingEnabled = false;
    adcConfigured = false;
    Serial.println("ADS1220 powered down. Send adcreset to restart.");
  } else if (command == "defaults") {
    rrefOhms = DEFAULT_RREF_OHMS;
    zeroOffsetOhms = DEFAULT_ZERO_OFFSET_OHMS;
    samplesPerReport = DEFAULT_SAMPLES;
    reportIntervalMs = DEFAULT_REPORT_INTERVAL_MS;
    Serial.println("Software defaults restored.");
    configureAdc();
  } else if (command == "help" || command == "h") {
    printHelp();
  } else {
    Serial.println("Unknown command. Send help for the command list.");
  }
}

void handleSerialInput() {
  while (Serial.available()) {
    const char incoming = static_cast<char>(Serial.read());
    if (incoming == '\n' || incoming == '\r') {
      if (serialCommand.length() > 0) {
        processSerialCommand(serialCommand);
        serialCommand = "";
      }
    } else if (serialCommand.length() < 95) {
      serialCommand += incoming;
    }
  }
}

void setup() {
  Serial.begin(SERIAL_BAUD);
  delay(750);

  pinMode(PIN_CS, OUTPUT);
  digitalWrite(PIN_CS, HIGH);
  pinMode(PIN_DRDY, INPUT);
  SPI.begin(PIN_SCLK, PIN_MISO, PIN_MOSI, PIN_CS);

  printHelp();
  configureAdc();
  printStatus();
  Serial.println("Set Rref if needed, then send start or once.");
}

void loop() {
  handleSerialInput();

  if (streamingEnabled &&
      millis() - lastReportFinishedMs >= reportIntervalMs) {
    reportMeasurement();
  }

  delay(2);
}

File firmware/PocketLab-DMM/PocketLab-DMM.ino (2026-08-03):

/*
  PocketLab DMM — 999:1 Input Divider Test

  ADS1220 / ESP32 wiring:
    ADS1220 SCLK  -> ESP32 GPIO18
    ADS1220 MOSI  -> ESP32 GPIO23
    ADS1220 MISO  -> ESP32 GPIO19
    ADS1220 CS    -> ESP32 GPIO27
    ADS1220 DRDY  -> ESP32 GPIO26
    ADS1220 AVDD  -> ESP32 3V3
    ADS1220 AGND  -> ESP32 GND
    ADS1220 CLK   -> ADS1220 DGND

  Divider and source wiring:
    Source positive -> divider P1  (VIN)
    Divider P11     -> OPA input
    OPA output      -> 1 kohm -> ADS1220 AIN0 (VSENSE)
    Divider P12     -> ADS1220 AIN1 and AGND (COM)
    Source negative -> divider P12 (COM)

  Divider:
    9.98 Mohm high side and 10.000 kohm low side
    Nominal attenuation = 999:1

  Range relay:
    ESP32 GPIO25 -> 1 kohm -> 2N3904 base
    2N3904 base -> 10 kohm -> COM
    2N3904 emitter -> COM
    2N3904 collector -> relay coil
    Other relay coil terminal -> ESP32 5V0
    Relay NO contacts -> divider P1 and P9
    Relay OFF = 999:1 range (safe startup state)
    Relay ON  = 37:1 range

  Test configuration:
    - AIN0 minus AIN1
    - Gain 1, PGA bypassed
    - Internal nominal 2.048 V reference
    - Normal mode, 20 samples per second
    - Single-shot conversions

  This first test is for positive, isolated, current-limited DC only.
  Do not apply a negative input or connect to mains.
*/

#include <SPI.h>
#include <math.h>

constexpr uint8_t PIN_ADS1220_SCLK = 18;
constexpr uint8_t PIN_ADS1220_MISO = 19;
constexpr uint8_t PIN_ADS1220_MOSI = 23;
constexpr uint8_t PIN_ADS1220_CS   = 27;
constexpr uint8_t PIN_ADS1220_DRDY = 26;
constexpr uint8_t PIN_RANGE_RELAY  = 25;

constexpr uint32_t SERIAL_BAUD = 115200;
constexpr uint32_t SPI_CLOCK_HZ = 1000000;
constexpr uint32_t DRDY_TIMEOUT_MS = 250;
constexpr size_t SAMPLE_COUNT = 100;

constexpr uint8_t CMD_RESET = 0x06;
constexpr uint8_t CMD_START_SYNC = 0x08;
constexpr uint8_t CMD_RDATA = 0x10;
constexpr uint8_t CMD_RREG = 0x20;
constexpr uint8_t CMD_WREG = 0x40;

// CONFIG0: AIN0-AIN1, gain 1, PGA bypassed.
constexpr uint8_t CONFIG0_AIN0_AIN1_GAIN1_PGA_BYPASS = 0x01;
constexpr uint8_t CONFIG1_20_SPS_SINGLE_SHOT = 0x00;
constexpr uint8_t CONFIG2_INTERNAL_REF = 0x00;
constexpr uint8_t CONFIG3_DEFAULT = 0x00;

constexpr double INTERNAL_REFERENCE_V = 2.048;
constexpr double ADC_POSITIVE_CODES = 8388608.0;  // 2^23
constexpr double HIGH_RANGE_DIVIDER_RATIO = 999.0;
constexpr double LOW_RANGE_DIVIDER_RATIO = 37.0;

bool rangeRelayEnergized = false;

SPISettings ads1220SpiSettings(SPI_CLOCK_HZ, MSBFIRST, SPI_MODE1);

void selectAds1220() { digitalWrite(PIN_ADS1220_CS, LOW); }
void deselectAds1220() { digitalWrite(PIN_ADS1220_CS, HIGH); }

void sendCommand(uint8_t command) {
  SPI.beginTransaction(ads1220SpiSettings);
  selectAds1220();
  SPI.transfer(command);
  deselectAds1220();
  SPI.endTransaction();
}

void resetAds1220() {
  sendCommand(CMD_RESET);
  delay(2);
}

uint8_t readRegister(uint8_t address) {
  const uint8_t command = CMD_RREG | ((address & 0x03) << 2);
  SPI.beginTransaction(ads1220SpiSettings);
  selectAds1220();
  SPI.transfer(command);
  const uint8_t value = SPI.transfer(0x00);
  deselectAds1220();
  SPI.endTransaction();
  return value;
}

void writeRegister(uint8_t address, uint8_t value) {
  const uint8_t command = CMD_WREG | ((address & 0x03) << 2);
  SPI.beginTransaction(ads1220SpiSettings);
  selectAds1220();
  SPI.transfer(command);
  SPI.transfer(value);
  deselectAds1220();
  SPI.endTransaction();
}

void printHexByte(uint8_t value) {
  if (value < 0x10) Serial.print('0');
  Serial.print(value, HEX);
}

void printRegisters() {
  for (uint8_t address = 0; address < 4; ++address) {
    Serial.print("CONFIG");
    Serial.print(address);
    Serial.print(" = 0x");
    printHexByte(readRegister(address));
    Serial.println();
  }
}

bool waitForDataReady(uint32_t timeoutMs) {
  const uint32_t startMs = millis();
  while (digitalRead(PIN_ADS1220_DRDY) != LOW) {
    if (millis() - startMs >= timeoutMs) return false;
    delayMicroseconds(100);
  }
  return true;
}

int32_t readConversion() {
  SPI.beginTransaction(ads1220SpiSettings);
  selectAds1220();
  SPI.transfer(CMD_RDATA);
  const uint32_t raw =
      (static_cast<uint32_t>(SPI.transfer(0x00)) << 16) |
      (static_cast<uint32_t>(SPI.transfer(0x00)) << 8) |
      static_cast<uint32_t>(SPI.transfer(0x00));
  deselectAds1220();
  SPI.endTransaction();

  if ((raw & 0x00800000UL) != 0) {
    return static_cast<int32_t>(raw | 0xFF000000UL);
  }
  return static_cast<int32_t>(raw);
}

double codeToSenseVolts(int32_t code) {
  return static_cast<double>(code) * INTERNAL_REFERENCE_V /
         ADC_POSITIVE_CODES;
}

bool configureAds1220() {
  resetAds1220();
  writeRegister(0, CONFIG0_AIN0_AIN1_GAIN1_PGA_BYPASS);
  writeRegister(1, CONFIG1_20_SPS_SINGLE_SHOT);
  writeRegister(2, CONFIG2_INTERNAL_REF);
  writeRegister(3, CONFIG3_DEFAULT);

  Serial.println("Configuration readback (expected 01 00 00 00):");
  printRegisters();

  const bool configPass =
      readRegister(0) == CONFIG0_AIN0_AIN1_GAIN1_PGA_BYPASS &&
      readRegister(1) == CONFIG1_20_SPS_SINGLE_SHOT &&
      readRegister(2) == CONFIG2_INTERNAL_REF &&
      readRegister(3) == CONFIG3_DEFAULT;

  if (!configPass) {
    Serial.println();
    Serial.println("FAIL: Configuration register readback does not match.");
    return false;
  }

  return true;
}

void printCommandPrompt() {
  Serial.println();
  Serial.println("Commands:");
  Serial.println("  run             Collect 100 samples using the selected range");
  Serial.println("  relay on        Select 37:1 range (relay energized)");
  Serial.println("  relay off       Select 999:1 range (safe range)");
  Serial.println("  relay status    Show the selected range");
  Serial.println("  help            Show this command list");
}

double selectedDividerRatio() {
  return rangeRelayEnergized ? LOW_RANGE_DIVIDER_RATIO
                             : HIGH_RANGE_DIVIDER_RATIO;
}

void printRelayStatus() {
  Serial.print("Range relay: ");
  Serial.print(rangeRelayEnergized ? "ON" : "OFF");
  Serial.print("; nominal divider ratio: ");
  Serial.print(selectedDividerRatio(), 0);
  Serial.println(":1");
}

void setRangeRelay(bool energized) {
  digitalWrite(PIN_RANGE_RELAY, energized ? HIGH : LOW);
  rangeRelayEnergized = energized;

  // Allow the relay contacts and analog signal to settle before measurement.
  delay(10);
  printRelayStatus();
  if (energized) {
    Serial.println("CAUTION: 37:1 range selected; use only a known safe input voltage.");
  }
}
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

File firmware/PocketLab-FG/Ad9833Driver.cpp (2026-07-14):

#include "Ad9833Driver.h"

#include <SPI.h>

namespace {
constexpr uint16_t CONTROL_B28 = 0x2000;
constexpr uint16_t CONTROL_RESET = 0x0100;
constexpr uint16_t CONTROL_SLEEP1 = 0x0080;
constexpr uint16_t CONTROL_SLEEP12 = 0x0040;
constexpr uint16_t CONTROL_OPBITEN = 0x0020;
constexpr uint16_t CONTROL_DIV2 = 0x0008;
constexpr uint16_t CONTROL_MODE = 0x0002;

constexpr uint16_t FREQ0_REGISTER = 0x4000;
constexpr uint16_t PHASE0_REGISTER = 0xC000;
constexpr double TUNING_WORD_SCALE = 268435456.0;  // 2^28
}

Ad9833Driver::Ad9833Driver(
    int sclkPin,
    int sdataPin,
    int fsyncPin,
    double masterClockHz,
    uint32_t spiClockHz
) :
    sclkPin_(sclkPin),
    sdataPin_(sdataPin),
    fsyncPin_(fsyncPin),
    masterClockHz_(masterClockHz),
    spiClockHz_(spiClockHz) {}

bool Ad9833Driver::begin() {
    pinMode(fsyncPin_, OUTPUT);
    digitalWrite(fsyncPin_, HIGH);

    SPI.begin(sclkPin_, -1, sdataPin_, fsyncPin_);
    delay(10);

    initialized_ = true;
    stop();

    Serial.println("[AD9833] Hardware initialized in safe-off state");
    return true;
}

bool Ad9833Driver::apply(uint32_t frequencyHz, Waveform waveform) {
    if (!initialized_) {
        Serial.println("[AD9833] Cannot apply settings before initialization");
        return false;
    }

    if (!supports(waveform)) {
        Serial.println("[AD9833] Unsupported active waveform");
        return false;
    }

    if (frequencyHz == 0) {
        Serial.println("[AD9833] Active frequency must be greater than zero");
        return false;
    }

    // Hold the phase accumulator in reset while updating frequency and phase.
    writeWord(buildControlWord(waveform, true));
    writeFrequency(frequencyHz);
    writeWord(PHASE0_REGISTER);
    writeWord(buildControlWord(waveform, false));

    Serial.printf(
        "[AD9833] Applied FREQ=%lu;OUTPUT=ON\n",
        static_cast<unsigned long>(frequencyHz)
    );
    return true;
}

void Ad9833Driver::stop() {
    if (!initialized_) {
        return;
    }

    // Clear OPBITEN, assert RESET, and power down the clock and DAC.
    const uint16_t safeOffControl =
        CONTROL_B28 |
        CONTROL_RESET |
        CONTROL_SLEEP1 |
        CONTROL_SLEEP12;

    writeWord(safeOffControl);
    Serial.println("[AD9833] Output disabled (RESET + SLEEP1 + SLEEP12)");
}

bool Ad9833Driver::supports(Waveform waveform) {
    return waveform == Waveform::Sine ||
           waveform == Waveform::Triangle ||
           waveform == Waveform::Square;
}

uint16_t Ad9833Driver::buildControlWord(
    Waveform waveform,
    bool reset
) const {
    uint16_t control = CONTROL_B28;

    if (reset) {
        control |= CONTROL_RESET;
    }

    switch (waveform) {
        case Waveform::Triangle:
            control |= CONTROL_MODE;
            break;

        case Waveform::Square:
            control |= CONTROL_OPBITEN | CONTROL_DIV2;
            break;

        case Waveform::Sine:
        case Waveform::RampUp:
        case Waveform::RampDown:
        case Waveform::DC:
            break;
    }

    return control;
}

uint32_t Ad9833Driver::calculateFrequencyWord(uint32_t frequencyHz) const {
    const double tuningWord =
        static_cast<double>(frequencyHz) *
        TUNING_WORD_SCALE /
        masterClockHz_;

    return static_cast<uint32_t>(tuningWord + 0.5);
}

void Ad9833Driver::writeFrequency(uint32_t frequencyHz) {
    const uint32_t frequencyWord = calculateFrequencyWord(frequencyHz);
    const uint16_t lower14 = static_cast<uint16_t>(frequencyWord & 0x3FFF);
    const uint16_t upper14 =
        static_cast<uint16_t>((frequencyWord >> 14) & 0x3FFF);

    writeWord(FREQ0_REGISTER | lower14);
    writeWord(FREQ0_REGISTER | upper14);

    Serial.printf(
        "[AD9833] Frequency word 0x%07lX\n",
        static_cast<unsigned long>(frequencyWord)
    );
}

void Ad9833Driver::writeWord(uint16_t word) {
    SPI.beginTransaction(SPISettings(spiClockHz_, MSBFIRST, SPI_MODE2));
    digitalWrite(fsyncPin_, LOW);
    SPI.transfer16(word);
    digitalWrite(fsyncPin_, HIGH);
    SPI.endTransaction();

    Serial.printf("[AD9833] SPI write 0x%04X\n", word);
}

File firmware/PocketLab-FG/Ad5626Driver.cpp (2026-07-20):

#include "Ad5626Driver.h"

#include <SPI.h>
#include <cmath>

Ad5626Driver::Ad5626Driver(
    int csPin,
    int sclkPin,
    int sdinPin,
    int otherChipSelectPin
)
    : _csPin(csPin),
      _sclkPin(sclkPin),
      _sdinPin(sdinPin),
      _otherChipSelectPin(otherChipSelectPin) {}

void Ad5626Driver::begin() {
    pinMode(_csPin, OUTPUT);
    pinMode(_otherChipSelectPin, OUTPUT);

    digitalWrite(_csPin, HIGH);
    digitalWrite(_otherChipSelectPin, HIGH);

    // The AD9833 initializes the shared ESP32 hardware SPI bus first.
    // Do not call pinMode() or SPI.begin() for SCLK/SDIN here; doing so would
    // detach or reconfigure the bus used by the other device.
    clear();
}

void Ad5626Driver::writeCode(uint16_t code) {
    code = constrain(code, 0, MAX_CODE);

    // The AD9833 shares the hardware SPI bus. Keep it deselected while the
    // AD5626 transaction is active.
    digitalWrite(_otherChipSelectPin, HIGH);

    // LDAC is tied low in hardware, so the DAC output updates automatically
    // when SYNC returns high at the end of this 16-bit transfer.
    // The AD5626 uses SPI mode 3 and consumes the least-significant 12 bits;
    // four leading zeros are followed by D11..D0.
    SPI.beginTransaction(SPISettings(1000000, MSBFIRST, SPI_MODE3));
    digitalWrite(_csPin, LOW);
    delayMicroseconds(1);
    SPI.transfer16(code & 0x0FFFU);
    digitalWrite(_csPin, HIGH);
    delayMicroseconds(1);
    SPI.endTransaction();

    _currentCode = code;
}

uint16_t Ad5626Driver::writeVoltage(float voltage) {
    const uint16_t code = voltageToCode(voltage);
    writeCode(code);
    return code;
}

void Ad5626Driver::clear() {
    writeCode(0);
}

uint16_t Ad5626Driver::currentCode() const {
    return _currentCode;
}

float Ad5626Driver::currentVoltage() const {
    return codeToVoltage(_currentCode);
}

uint16_t Ad5626Driver::voltageToCode(float voltage) {
    if (voltage <= ZERO_SCALE_V) {
        return 0;
    }

    if (voltage >= MEASURED_FULL_SCALE_V) {
        return MAX_CODE;
    }

    const long code = lroundf(
        (voltage - ZERO_SCALE_V) / VOLTS_PER_CODE
    );

    return static_cast<uint16_t>(constrain(code, 0L, 4095L));
}

float Ad5626Driver::codeToVoltage(uint16_t code) {
    code = constrain(code, 0, MAX_CODE);
    return ZERO_SCALE_V + VOLTS_PER_CODE * static_cast<float>(code);
}

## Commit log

2026-07-12 NodeMCU ESP32S BLE Sevrer for Function Generator
2026-07-14 circuit docs and .ino refactor to extract AD9833 Driver
2026-07-16 OP484 Fixed Gain, X9C103 Digital Amplitude Control, AD5626 CD Offset Control, python env for schematic and wiring diagram generation
    [AD5626_StandAlone_DAC_Test.ino, Ad5626Driver.cpp, Ad9833Driver.cpp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]
2026-07-20 noise reduction
    [PocketLab_Amplitude_Offset_Interaction_Test_Matrix.csv]
2026-07-26 bipolar calibration config + linter fix
2026-07-27 extend Vpp to full +/- 5V envelope
2026-07-30 added framework for an EE calculator feature
2026-08-03 DMM Rev A
    [PocketLab_DMM_RevA.kicad_pcb, PocketLab_DMM_RevA.kicad_sch, inventory.xlsx]
2026-08-12 DMM circuit progress
    [inventory.xlsx]
2026-08-14 DMM feather vsense + schematic progress
2026-08-27 PCB: complete first-pass routing before DRC audit
    [00_SYSTEM_TOP.SchDoc, 10_POWER.SchDoc, 20_MCU_BLE.SchDoc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]
2026-10-13 refactor: extract device types and DMM protocol parsing
2026-10-13 feat(ble): automatically refresh device list after disconnect
2026-10-13 refactor(ble): extract device scanning into dedicated hook
2026-10-14 feat(dmm): add live voltage measurement statistics
2026-10-14 feat(power): add automatic shutdown after BLE inactivity
2026-10-22 voltage measurement improvements
2026-10-22 feat(dmm): add interactive voltage graph and measurement UI
2026-10-22 feat(dmm): improve voltage graph, averaging, and mode navigation
2026-10-24 feat(calculator): implement interactive voltage divider designer
2026-10-26 refactor(firmware): replace buzzer PWM with BLE continuity events
2026-10-29 voltage divider ui refactor
2026-11-11 fix(compid): correct I2C pin mapping and verify TCA9539 communication
